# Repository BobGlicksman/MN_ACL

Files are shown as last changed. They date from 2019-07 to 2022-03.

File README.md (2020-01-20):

# MN_ACL
## RFID based access control and monitoring system for Maker Nexus.
This repository contains hardware, software and test information 
related to the development of an access control system for
Maker Nexus.

Each member is issued an RFID card that has been prepared to identify the member
and to ensure that cards can be revoked and/or replaced.  Membership information relevant
to card issuance and to member check-in and permission to access certain equipment
is supplied via real-time
query of the Maker Nexus CRM system which uses EZ Facility.  The code to access EZ Facility
via their REST API has been broken out into separate functions so that it can be replaced
by any suitable database.  Administrative utilities are also provided to facilitate recycling
membership RFID cards and identifying the owner of misplaced RFID cards.

A "Facility Database", separate from EZ Facility, is included in this project.  EZ Facility is the
authoritative source for all membership status, payment and training information needed for access
control decisions.  The Facility Database provides membership access records for both a real-time 
status display and for off-line reporting on facility and equipment utilization.

This project uses a Particle Argon; however, a Xenon should also work in a Particle Mesh configuration.  
The access control system is based upon Mifare Classic 1K RFID cards that are written to/read from
using a PN532-based MFC/RFID breakout board.  The Adafruit PN532 library is used to supply
the underlying communication support between the Particle device and the RFID card. Mifare Classic 1K 
cards have been chosen because they are inexpensive and widely available on the Internet.
These cards are older technology and not very secure.  However, we have deemed them to be secure 
enough for this application.  One sector of the card is chosen for this application and the sector encryption
keys and block access control bits are changed to make the card data secure from casual inspection and
from cloning.  The
remaining sectors of the card can be used for other applications, e.g. vending machine credits or special room
access.

A detailed technical overview of this project is provided in Documents/RFID_ACS_Overview_Document.pdf.  
We strongly encourage you to read through his document before deciding how this project might be
applied to your unique access control and monitoring situation.

## Files and Folders:
#### README.md:  
This document.
#### Repository_Overview.pdf:  
An overview of the structure and contents of this repository.
#### Terms_Of_Use_License_and_Disclaimer.pdf:  
You MUST READ this document and AGREE TO 
its terms and conditions before you are authorized to use the material in this repository. This
project is released under and open source, non-commercial license.
### Documents (folder):
Project documentation, including the RFID_ACS_Overview_Document and build, install and
usage documents.
### Hardware (folder): 
Design information (CAD files) and documentation for all of the hardware used
in this project, including electronic design, printed circuit board design, and
mechanical/packaging design and build information.
### Software (folder):
Design information, documentation, source and executable code for all of the software
in this project, including Particle (Argon) software, webhooks, PHP files, database
schema and stored procedures, Android app source and executable files, and web/html
files.
### Test and Development (folder):
Legacy test code and test results for integrating RFID cards and EZ Facility API calls with 
Particle devices.  The information in this folder is not necessary to build or install
this project.  However, it may be useful for developing extent ions to the RFID and/or EZ Facility
capabilities of this project.

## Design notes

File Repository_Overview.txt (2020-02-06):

Repository Overview

In this repo you will find all the software, hardware design files, and documentation to allow you to bring up and use your own RFID badge system. 

You will find the following folders:

1. Hardware: Contains the files for
1.1 creating the printed circuit board
1.2 CAD files for laser cutting the enclosure,
1.3 parts list

2. Software: Contains software for:
2.1 The Arduino C code to compile and download to the Particle.io Argon processor.
2.2 The Particle.io webhooks that allow the Argon to interact with internet based resources.
2.3 The MySQL database code and PHP web site that interface it to the internet.
2.4 The two Android administrator applications, written in the MIT App Inventor 2 environment.

3. Documents: A robust set of documentation for both assembly and operation of the RFID system.

4. Test And Development: Several programs that can be used to experiment with parts of the overall system. In particular, there are several programs we used to exercise the PN532 RFID system and software to help us understand how it works. We include them in case they are useful to you.

We hope this project is useful to you. We do not, of course, offer support in any way. However, drop us an email if you have questions and we might be able to advise you.
Bob Glicksman, Jim Schrempp, Mike Calyer

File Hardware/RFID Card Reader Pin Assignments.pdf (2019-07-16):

# RFID Card Reader Photon/Argon/Xenon Pin Assignments

Bob Glicksman; 7/15/19

## LCD Wiring:

LCD | | Particle
VSS | -- | GND
VDD | -- | +3.3 volts
V0 | -- | 10K ohm pot wiper
RS | -- | A0
RW | -- | GND
E | -- | A1
D0 | -- | N/C
D1 | -- | N/C
D2 | -- | N/C
D3 | -- | N/C
D4 | -- | A2
D5 | -- | A3
D6 | -- | D5
D7 | -- | D6
A | -- | +3.3 volts
K | -- | GND

## PN532 Breakout Board Wiring:

Breakout | | Particle
5V | -- | VIN (Photon); VUSB (3rd Gen)

GND | -- | GND
3.3V | -- | N/C
SDA/TXD | -- | D0 (5.6K pullup to 3.3V)
SCL/RXD | -- | D1 (5.6K pullup to 3.3V)
IRQ | -- | D3

DIP Switches: SEL1 = OFF (L); SEL0 = ON (H)

LED and Buzzer Wiring.

Buzzer | -- | Photon D2
Ready LED | -- | Photon D4
Admit LED | -- | Photon A4
Reject LED | -- | Photon A5

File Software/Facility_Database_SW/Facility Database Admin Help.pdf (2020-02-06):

# Facility Database Admin Help

The Facility Database holds the event logs from each of the RFID stations. It also holds the configuration information for the stations. And, it is the data source for the reporting web site.

In this document we assume you are familiar with PHP, MySQL, phpMyAdmin (or similar tool), and curl.

# Database Setup

## Create the database

Using your ISP admin console, or similar, create a database called rfidlogs (or your own name). You do not need to make the database available for remote access.

## Create users

Create two users:

- rfidreader (Execute SP, Select)
- rfidlogger (Insert, Select)

## Database structure

Use the file rfidlogs_schema.sql to create the tables and stored procedures.

# Website Setup

## Deploy

Copy all the files in datalogging to the root of your website.

## Modify the rfidconfig.ini file

- Add the two database uses in the appropriate keys, and their passwords.
- Change the photoDisplay key to have the URL prefix of the server hosting your member's photos.
- Change the file permission to 660

## Test

Bring up the web page rfidhome.html

# The Database

The rfidlogs database has two tables: rawdata and stationConfig.

## rawdata

This table holds the data for every log event that is recorded. These are typically made by an rfid Station, but could be made by any process that calls the correct URL.

rawdata is written to by rfidcheckin.php and rfidlog.php. These pages accept the POST of a JSON package. Each file has a description of the JSON it expects in the header of the file.

### rfidcheckin.php

is used to toggle the state of a clientID in the database. Each day, the first time rfidcheckin is called for a particular clientID, a record is entered for Checked In.

The next time that clientID is used a Checked Out record is entered.

### rfidlog.php

is a more generic log function. The parameters passed to it are added to the rawdata table. This is useful for logging errors, warnings, restart events, etc.

## stationConfig

This table contains configuration information for the different stations you have. In a nutshell, each station has a deviceType. When the station boots it calls fdbGetStationConfig.php passing in its deviceType. The URL returns a JSON package telling the Station what name to use, what eventName to use when logging, the strings it should look for to validate a client for machine use, etc. The fields are each documented in the comments section of the database.

Use phpMyAdmin to insert records to this table to establish your configuration.

Note: We have included sample data in stationConfig_sampledata.sql. You can insert this data into your database if you want to see what our config looks like.

# Tests

Note: To facilitate testing we supply two files of sample data: rawdata_sampledata.sql and stationConfig_sampledata.sql. You can load these two sample sets to see what the website reports look like if you are unable to get your own POSTs to work for some reason.

1. Test Logging:
a. In the header of file rfidlog.php is a sample JSON. Use that JSON to construct several test packages.
b. Post each to rfidlog.php. Look in the rawlog table to see your data.
c. Use rfidclientactivity.php to see that the data is presented on the page.
2. Test Check in/out
a. In the header of file rfidcheckin.php is a sample JSON. Use that JSON to construct several test packages. Use the same clientID in a few of the packages.
b. Post each to rfidcheckin.php.
c. Use rfidclientactivity.php to see that the data is presented on the page.
d. Use checkinreport.php to see that your clientID has been checked in and then post again to see that has been checked out.
3. Other Reports
a. From the rfidhome.html page, click on each link and see that the report shows the activity you have just performed.
4. Manual Checkout
a. With at least one client Checked In, bring up checkinreport.php.
b. Click on one of the names and see that the client is checked out.
5. Station Configuration
a. Call the URL fdbGetStationConfig.php?cmd=-1
b. See that the JSON returned has a list of stations and their device types. This is used by the admin configuration app.
c. Call the URL fdbGetStationConfig.php?cmd=<<any valid device type>>
d. See that the JSON returned is a set of configuration parameters for the Station.

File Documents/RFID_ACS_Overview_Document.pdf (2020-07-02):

# RFID Access Control System System Overview Document

By: Jim Schrempp, Bob Glicksman and Mike Calyer; v5, 6/30/2020

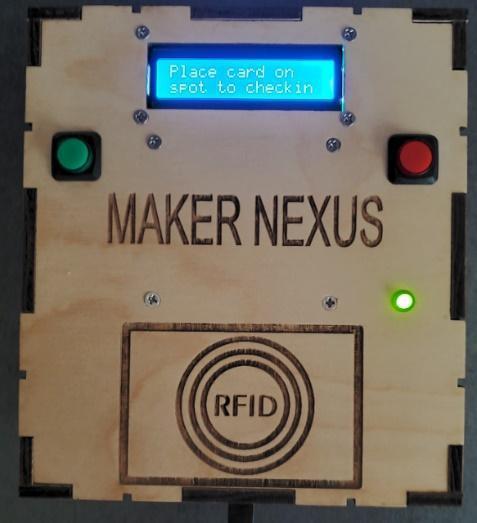
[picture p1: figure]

© 2019/2020 Team Practical Projects, Maker Nexus, Bob Glicksman, Jim Schrempp and Mike Calyer. All rights reserved.

NOTICE: Use of this document is subject to the terms of use described in the document “Terms_of_Use_License_and_Disclaimer” that is included in this release package. This document can be found at:

https://github.com/TeamPracticalProjects/MN_ACL/blob/master/Terms_of_Use_License_and_Disclaimer.pdf

© 2019/2020, Team Practical Projects, Maker Nexus, Jim Schrempp, Bob Glicksman and Mike Calyer; all rights reserved. Subject to “Terms of Use, License and Disclosure”

TABLE OF CONTENTS.

TABLE OF CONTENTS. | 1
FORWARD. | 2
GLOSSARY AND KEY CONCEPTS. | 2
PROJECT REQUIREMENTS. | 5
Background. | 5
Top Level Requirements. | 7
Control vs Cost and Accessibility Requirements. | 8
Facility Access Control Detailed Requirements. | 8
Location/Equipment Access Control Detailed Requirements. | 9
Administrative Requirements. | 9
Facility Monitoring Detailed Requirements. | 10
Technical Failure Backup Requirements. | 10
DESIGN OVERVIEW. | 10
Top Level Design. | 11
RFID Lock Design. | 13
RFID Station Design. | 15
Administrative Station Design. | 17
RFID Station Type Selection. | 17
Design for EZ Facility Access. | 18
Design For Facility Database. | 19
Security Design and Secret Information. | 21
RFID Card Security. | 21
Station Security. | 24
Cloud Security. | 25
Administrative Security. | 25
Cost Effective Design. | 26
CONCEPTS FOR PROJECT USE BY OTHER THAN MAKER NEXUS. | 26
Implement this project in a non-Maker Nexus Facility that uses EZ Facility. | 26

Implement this project in a non-Maker Nexus Facility that uses a different CRM system than
EZ Facility. | 27

Implement this project in a non-Maker Nexus Facility that does not have an electronic CRM
system. | 27

FORWARD.

The RFID Access Control System is a very complex project. The project was driven by the need for such a system at Maker Nexus, a 501(c)3 non-profit makerspace located in Sunnyvale California. This document is intended to provide the reader with an overview of the requirements and design of the project. Complete details of the project are posted in this repository and are offered to the general public under a Creative Commons open source, non-commercial license.

Interested parties may wish to implement variants of this project that meet the unique needs of their establishment or organization. We feel that it is very important for anyone who wishes to do so to read through this overview document and become familiar with the requirements and architecture of the project. It is only through a complete understanding of the project architecture that interested parties can successfully modify this project to meet their own, specific requirements and needs.

GLOSSARY AND KEY CONCEPTS.

The following terms are used throughout this document and are defined herein.

Maker Nexus. Maker Nexus is a 501(c)3 non-profit makerspace located in Sunnyvale California. https://www.makernexus.com/

EZ Facility. EZ Facility is an on-line scheduling, management and membership system. Maker Nexus has chosen EZ Facility to fulfill its customer relationship management (CRM) needs. As such, EZ Facility is the authoritative source for all Maker Nexus member information, including current membership status, current member payment status, and member “packages”. Maker Nexus uses EZ Facility “packages” to record all member training, including basic operating and safety training that is required before a member can access certain locations within Maker Nexus or use certain pieces of equipment. https://www.ezfacility.com/ If you use some system other than EZFacility, then when you see this term think: “Membership Management System”.

RFID. “Radio Frequency Identification”. In this context, “RFID” refers to a system that uses Mifare Classic 1K NFC cards operating at 13.56 MHz. Maker Nexus members are each issued a personalized “RFID” card that contains encrypted information that identifies the card holder in EZ Facility and contains a provision for card revocation. Classic 1K cards provide a reasonable level of security to prevent card cloning or tampering at a low per-card cost from a wide variety of sources. This project utilizes NFC technology based upon the NXP PN532 chip. This chip supports a wide variety of RFID cards, including the latest technology Mifare Desfire EV1/EV2 cards. This approach offers a pathway to upgrade the system to a higher level of security, albeit at a significantly higher price per card.

Encryption Keys. Mifare Classic 1K cards allow two encryption keys per sector, where a “sector” is a group of 4 user-read/write 16-byte data blocks. This project uses one sector of a Classic 1K card and two secret encryption keys. “Key A” is a secret key that is required to authenticate with a Maker Nexus RFID card for reading (only) of two items of data: the member’s EZ Facility unique “clientID” and a randomly assigned “MN card UID”, retained in the CRM system, that is used for card revocation purposes. These items of information can only be read from an RFID card by a device that knows this secret key. The second secret key, “Key B”, is required to write data to the Maker Nexus sector on the RFID card and is also required to change keys on the card and to reformat a card back to its “factory fresh” condition. Key B is only used for administrative purposes – to create new cards, update/revoke cards, and to restore a card to “factory fresh” condition.

Particle. Particle is a company that provides a complete “Internet of Things” (IoT) platform, including Arduino-like hardware, development software, and connectivity. This project uses Particle’s “3rd generation” mesh devices; specifically, the Particle Argon. The Argon is an inexpensive yet powerful microcontroller module with built-in WiFi capability. The Argon can also act as a mesh network gateway; specifically, with the lower cost Particle Xenon modules. As of this writing, we have tested use of a Xenon/Argon mesh/WiFi configuration for our stations and they appear to work. However, our initial deployment is limited to Argon devices because Particle does not yet support redundant mesh gateways with automatic failover. Therefore, each of our Particle based stations has direct WiFi connectivity via its Argon module. https://www.particle.io/

Particle Cloud. “Particle Cloud” refers to Particle’s cloud platform that provides Internet device management and integration between Particle hardware modules and the Internet connected world. This project uses basic Particle cloud connectivity to communicate with Argon-based RFID stations.

Webhook. A webhook is a real time service provided by the Particle Cloud for connecting Particle processors to the larger internet. A webhook is invoked when a Particle processor publishes a specific event via Particle.publish(), passing any parameters in a JSON package. The webhook calls out to a specified URL and interprets the JSON for any parameters to use. When a response is returned from the URL, the Particle Cloud webhook returns the data to the Particle processor, optionally formatting the response. Our system uses Particle’s cloud webhook capability to communicate with EZ Facility’s cloud API and with a cloud-based SQL database for real-time recording of member activities within Maker Nexus.

RFID Station. Various “stations” are located within the Maker Nexus facility where members are required to “tap in” with their RFID membership card. Each station uses the Secret Key A to read information from the Maker Nexus “sector” in the RFID card that is presented. The station then communicates with EZ Facility in order to obtain membership information that is necessary to determine if the member has access to the location/equipment under that station’s purview. RFID stations are configured (by an administrator) to provide specific types of access control services. There are three general types of RFID stations in this project:

Administration Station: There is generally only one administration station provided within Maker Nexus. This station is subject to added physical security and is the only station type that can create new RFID cards, revoke old RFID cards, reset RFID cards, and update/change Maker Nexus secret encryption keys used on a card.

Check-in/out station: There are one or more of these stations at each entrance/exit to Maker Nexus. Members must tap their badge at one of these stations when they enter and leave the Maker Nexus facility. Check-in/out stations use data from EZ Facility to ensure that memberships and dues are current before a member is admitted to the facility. This station also logs check-in/out events to both EZ Facility and the Facility Database.

Location/equipment station: Various subtypes of these stations are placed within Maker Nexus to check status and log member use of locations/equipment within the Maker Nexus facility. Location/equipment stations use data from EZ facility to ensure that members have the necessary safety training “packages” for that location/equipment before the member can access the associated machine or location within Maker Nexus.

RFID Lock. An “RFID lock” is a separate electronic circuit board that controls an electromechanical locking device. RFID Stations “publish” successful “tap-in events” to the Particle cloud. RFID Lock devices “subscribe” to these events and can use such events to unlock a cabinet or drawer. Such a cabinet or drawer might contain a physical access key for some piece of equipment (e.g. a laser cutter), essential tooling to use some piece of equipment (e.g. bits and a locking key for a drill press), or anything else that should only be accessible to people who are authorized to use some item of equipment. Multiple RFID Locks may be associated with a specific type of RFID Station (e.g. “Laser Cutter” location/equipment station type). Multiple RFID Stations may be of the same type (e.g. multiple facility check-in stations). Station type codes and the codes for RFID Locks to “listen for” are completely facility dependent and are defined in a table within the Facility Database (see below). Particle publish/subscribe capabilities utilize the particle Cloud and are highly secure. The RFID Lock project is an add-on to this project and details are contained in its own GitHub repository; see:

https://GitHub.com/TeamPracticalProjects/RFID_Lock

Facility Database. The “facility database” is a cloud-based SQL database (with associated php software) that keeps track (in real time) of member activity within Maker Nexus. This database keeps track of members who are inside the facility and of location/equipment for each member as they tap into areas within Maker Nexus. The facility database provides administrators and emergency response personnel with immediate and current information about member location in the event of an emergency. This database can also be used to monitor access control compliance and to produce analytical reports about equipment and location utilization. RFID stations communicate with the Facility Database through a Particle cloud webhook.

Checkin Display. A web page available within the Maker Nexus facility that shows members who are currently in the facility using data from the Facility Database. It also shows an indication of which stations each member has activated while in the facility. The Checkin Display is presented on at least one monitor located at a prominent spot within the facility.

PROJECT REQUIREMENTS.

Background.

Maker Nexus is a 501(c)3 non-profit makerspace located in Sunnyvale, California. The Maker Nexus mission statement is as follows:

“Our mission is to increase the capacity of individuals in our community to make things. We believe that unleashing the innate innovation in people can make their lives better, can improve our community, and can even change the world.”

Safety, security, and financial viability are key concerns of Maker Nexus. Maker Nexus has a substantial amount of industrial grade equipment, including (but not limited to):
- 3D printers
- Electronics bench (including soldering equipment, test equipment and hand tools)
- Laser cutters/engravers
- Vacuum formers
- CNC embroidery machines
- Woodshop, complete with planers, joiners, table, miter and band saws, drill press, lathes, CNC router, workbenches, and hand tools
- Metal shop (in development, as of this writing)
- Classrooms, including computers
- High speed WiFi

Safety is a primary concern. Each member must pass a class (or take an alternative operation and safety test) before they are permitted to use specific items of industrial equipment. The classes emphasize safety and the proper operation and handling of each item of equipment. The scope of safety also includes staff training, procedures, and information needed for emergency first responders.

Security is a related concern. It is important to monitor who is in the facility and who is using each equipment item at all times.

Financial viability is the remaining main concern of Maker Nexus. Several previous maker spaces have gone bankrupt due to a lack of financial scrutiny and control. Financial viability includes safety, as proper safety procedures and enforcement help to reduce insurance and liability costs. Financial viability includes security because good security procedures and enforcement mechanisms reduce financial losses due to abuse, neglect, and theft. Finally, financial viability necessitates tight financial controls, including billing and tracking of memberships, dues payment, and expenditures.

Maker Nexus, like virtually all non-profits, must maintain a tight budget that limits the number of paid staff personnel needed to operate the facility. Automation is viewed as a key element in reducing staffing requirements. Maker Nexus has selected EZ Facility as its CRM system. EZ Facility is the authoritative source for all Maker Nexus membership, membership status, billing, payment tracking, and class/test completion information.

Maker Nexus has also determined that automation can assist a limited and busy paid staff via an RFID card-based access control system. This system is what this project is about. Each member is issued an RFID card. The RFID card is required to check in and out of the facility and to gain access to locations/equipment within Maker Nexus. Since EZ Facility is the singular, authoritative source for all the information needed for access control purposes, the RFID card system must query EZ Facility directly, and in real-time, for information needed to make proper access control decisions. EZ Facility has a cloud API that is suitable for this purpose. However, EZ Facility does not have an RFID card system that suits this purpose. This project provides for this latter need.

The idea behind this project is that various RFID card reader stations are placed within the Maker Nexus facility. Stations are placed at the main entrance reception desk so that members can check in and check out of the facility by tapping their membership RFID card at the station. Check in/out stations are also located at secondary entrances and exits to the facility. Check -in/out stations obviate the need to staff a reception desk and to directly monitor secondary entrances/exits. Members are only permitted into Maker Nexus if they are paid up members in good standing. Otherwise, members must contact a facility manager to resolve their membership-related issue(s).

Additional RFID card stations are located inside the facility, near specific locations (e.g. textile area) or specific pieces of industrial equipment (e.g. laser cutter) that require members to pass safety and operation classes/tests before they are permitted to use the equipment. Members gain access to locations/equipment by tapping their RFID card at the location/equipment station.

Members must have the proper “package(s)” within EZ Facility in order to gain access to the associated locations/equipment. An EZ Facility “package” represents completion/passing of the relevant class(es). A member who does not have the proper package(s) in EZ Facility needed to gain access to an item of equipment or a location is rejected by the RFID card system and must contact a facility manager to resolve their credentialing issue(s).

Maker Nexus staff needs to monitor the RFID card system admit/reject decisions. Two means are provided to accomplish this end. First, each RFID card station is equipped with highly visible red and green lights that clearly indicate the station’s accept/reject decision for each card tapped. Each station also has a buzzer that provides an audible indication of accept or reject. Second, a summary status display is provided on monitors located at the entrance and at other locations within the facility. This display provides a quick overview of who has been admitted into Maker Nexus and what location/equipment each admitted member has been accepted. Staff members can use this display to quickly determine who is in the facility, where in the facility they may be, and (by omission) whether someone is in the facility or using equipment for which they do not have permission. The Facility Database drives this display and the same database may be used to generate various administrative reports, such as facility and machine utilization statistics.

RFID Locks optionally provide additional access control by keeping equipment enable keys and critical tooling locked up and inaccessible to anyone who does not successfully tap in to an RFID Station that is associated with some specific location or item of equipment. RFID Locks are supported by this project but the details are contained in their own repository; see:

https://GitHub.com/TeamPracticalProjects/RFID_Lock

Top Level Requirements.

Each member of Maker Nexus shall be issued an RFID card. The member must use their RFID card to gain access to the Maker Nexus facility and to gain access to specific items or equipment or specific locations (e.g. textile area) within the facility.

The RFID card system shall query EZ facility directly, and in real-time, in order to determine whether the cardholder is permitted into the facility and/or permitted to use specific items of equipment, depending upon the RFID card station’s location and function.

Each RFID station shall light a green “admit” light and beep an “admission” sound after a card is tapped and the proper credentials for that station location are obtained (for the card holder) from EZ Facility. Each RFID Station shall publish a successful tap-in event to the Particle cloud containing the station’s type (“woodshop”, “laser cutter”, “check-in”, etc.).

Each RFID station shall light a red “reject” light and beep a “rejection” sound after a card is tapped and the proper credentials for that station location are not found (for the card holder) in EZ Facility, or if some error occurs.

The RFID card system shall log all card taps and access control decisions to a cloud-based Facility Database. The Facility Database shall utilize this information to maintain a real-time display of members admitted to and present within Maker Nexus and of locations/equipment that each member has been admitted to.

Members shall be encouraged to “tap out” when leaving Maker Nexus. These taps shall be used to update the Facility Database and the associated summary status display. It is not required that members “tap out” on individual location/equipment stations.

The summary status display shall automatically be cleared each day after the facility has closed. This will compensate for any failures to tap out from the facility.

There shall be a manual process available to Maker Nexus staff members that allows them to “tap out” any member.

Control vs Cost and Accessibility Requirements.

The RFID card access control system shall provide a “moderate” level of security and control. The term “moderate” herein is used to indicate a need for balance between the project goals and objectives on one hand, and the cost and member usability on the other hand. Specific requirements related to “moderate” security and access control are as follows:

- Access control shall be via RFID cards that are reasonably difficult to clone. The use of bar codes or unencrypted RFID tags are not acceptable. On the other hand, RFID cards/technology must be easily available at low cost.
- Physical barriers for access control are not required and are currently deemed to be an unacceptable intrusion on member satisfaction and on safety. Powering off equipment to prevent member access after RFID system rejection is not required and is currently deemed to be undesirable from an equipment longevity perspective. However, the desirability of powering off specific items of equipment is presently under review and this limitation may be removed for certain items of equipment at some later time.

Facility Access Control Detailed Requirements.

The RFID card access control system shall query EZ Facility, in real-time, when a member taps in at a facility entrance station. The member shall be identified to EZ Facility by the EZ Facility “clientID”, which is a unique identifier for each membership record within EZ Facility.

A member shall only be admitted to Maker Nexus if (a) their membership status is “current”, and
(b) they do not owe money for dues or for other purchases, and (c) their RFID card has not been revoked. If a member is rejected for any of these reasons, admission to Maker Nexus shall be rejected and the cardholder shall be directed to see a facility administrator to clear up their account.

Each time that an RFID card is tapped at a facility entrance station, the station shall query EZ Facility for admission information as required above. The station shall also check the current check-in status with the Facility Database to see if the card holder is already checked into Maker Nexus. If not, the station shall consider the tap to be a check-in. If the card holder is already checked into Maker Nexus, the tap shall be considered a check out and the Facility Database shall be updated accordingly.

Location/Equipment Access Control Detailed Requirements.

The RFID card access control system shall query EZ Facility, in real-time, when a member taps in at a location/equipment station. The member shall be identified to EZ Facility by the EZ Facility “clientID”, which is a unique identifier for each membership record within EZ Facility.

A member shall only be admitted to the location/equipment of the station if they have the required “package(s)” for that equipment/location. If a member is rejected on this basis, use of the associated location/equipment shall be rejected and the cardholder shall be directed to see a facility administrator to clear up their records.

If the member is admitted by the station, an indication shall appear with their information on the summary status display.

Access control activity - positive and negative - shall be logged to the Facility Database.

Administrative Requirements.

Maker Nexus administrative personnel shall be provided with the following capabilities:
- The capability to create and issue a valid Maker Nexus RFID card to a member.
- The capability to revoke all previous cards issued to a member whenever a new card is issued.
- The capability to reset any Maker Nexus formatted cards to a “factory fresh” condition.
- The capability to determine the owner and status of an unknown RFID card.

All information needed to produce/manipulate Maker Nexus RFID cards and EZ Facility record information shall be kept secret and shall be known only to selected Maker Nexus administrative personnel.

RFID card check in/out stations and location/equipment stations shall not have the capability to write or to alter information stored on the RFID cards; only to read information from the cards securely. Only specifically designated administration stations shall have the capability to create or modify Maker Nexus formatted RFID cards.

Only duly designated Maker Nexus administrative personnel shall be able to configure or reconfigure RFID card stations to be check in/out stations, location/equipment stations for specific location/equipment, configure RFID Lock types and listen codes, or to perform administrative functions.

Facility Monitoring Detailed Requirements.

A Facility Database shall be provided to record successful and unsuccessful taps at all check-in and location/equipment stations. Information recorded in the facility database shall be used to determine if a tap at a facility check-in station represents a check-in or check-out; i.e. toggling this status.

The Facility Database shall drive a summary status display (e.g. web page) that depicts all members who are currently checked-in to Maker Nexus. This display shall be updated in near real-time as check-ins and check-outs take place. This display shall also show current member check-in status for each location/equipment item within Maker Nexus. Reports of check ins shall only report members who have checked in that day. Members who fail to check out the previous day shall not be reported as checked in.

Displays that are driven from the Facility Database shall be placed near the front desk and at other locations within Maker Nexus that are visible to staff members throughout the facility.

Note: the Facility Database does not supply data used to admit or deny a member access to the facility or equipment. The data for these decisions shall be provided by EZ Facility exclusively.

Technical Failure Backup Requirements.

Procedures for facility check-in and location/machine access control shall be created that operate in the event of failure of any part of the RFID card access control system. The same procedures shall be used if a member does not have their RFID card with them and for guests who are not current members of Maker Nexus. Manual sign-in sheets are an acceptable solution.

DESIGN OVERVIEW.

The section presents an overview of the RFID access control system project design. The overview introduces the major components of the system and the data flows between them. This overview also highlights how the system design achieves the project requirements.

Top Level Design.

The overall architecture for the system is depicted in figure 1:

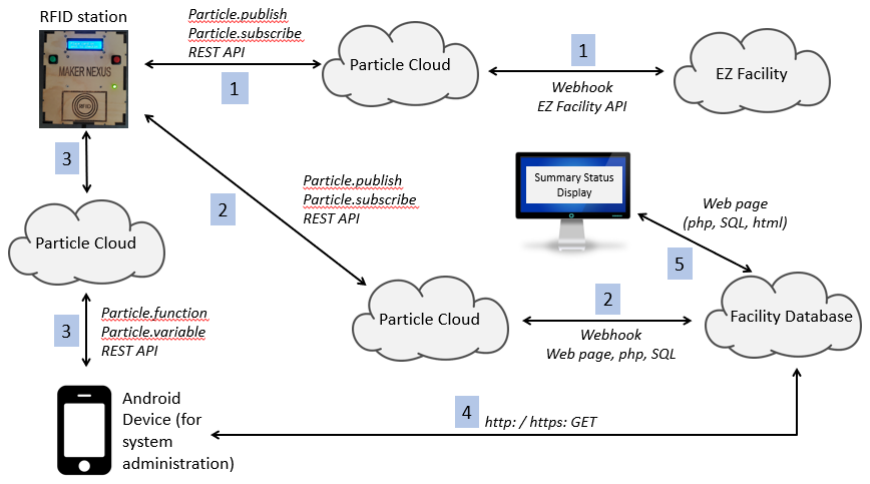
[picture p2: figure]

Figure 1. System Architecture.

The major components of the system are as follows:

- RFID station: There are multiple RFID stations that are part of this project. The stations are used for facility check-in, location and equipment access control, and system administration. Each station contains a Particle¹ Argon²
; a high-end microcontroller with WiFi – Internet access.
- Particle cloud: The Particle devices in the RFID stations communicate securely with the Particle cloud. The Particle cloud allows Particle devices to securely communicate with Internet based services via a REST interface, and also via webhooks. Both the REST interfaces and webhooks are used in this project.

1 www.particle.io

2 Any 3rd Generation Particle device may be used in RFID stations. The Argon provides WiFi access to the Internet directly. Xenons can be used to provide Internet access indirectly, via the Particle mesh network capability, using an Argon or Boron as the Internet gateway. We have tested a Xenon working through an Argon as the gateway but have not currently deployed any Particle devices other than Argons. As a result, each RFID station communicates directly with the Particle cloud over the Maker Nexus WiFi.

- EZ Facility: EZ Facility is a cloud-based CRM system. EZ Facility offers a REST API that allows Internet connected devices to query and modify information in the EZ Facility Maker Nexus account.
- Facility Database: This is a mySQL database, with associated web pages and PHP code that is hosted in the Maker Nexus web hosting cloud account. At the moment, the database logs all transactions sent there by the RFID stations³
in a single table.
- Summary Status Display: This is a computer monitor that displays a web page(s) produced by querying the Facility Database using php scripts and javascript. The web page shows all members who are currently checked in to Maker Nexus and all locations/equipment that each member checked into using their RFID card.
- Android Device: This is any WiFi-connected android smartphone or tablet. As of this writing, an inexpensive 7” Kindle Fire tablet is used, but most any Android device will do. This device hosts apps that Maker Nexus administrators can use to configure other stations, to manage RFID cards, and other related administrative functions.

The various flows of data within the system are depicted by numbers above the arrows in figure 1.

(1) Several webhooks have been created to communicate with EZ facility using the EZ Facility API. These webhooks are stored in the Maker Nexus RFID Admin account on the Particle cloud. Each webhook is triggered by a Particle.publish() statement in the Argon’s firmware. Each Argon receives webhook responses via Particle.subscribe() statements. Webhooks are provided to: (a) Obtain a temporary access token (OAuth) to the Maker Nexus EZ Facility account, (b) Obtain member information from EZ Facility based upon the membership number, (c) Obtain member information from EZ Facility based upon the EZ Facility ClientID field, (d) Obtain package information for a member from EZ Facility, and (e) check a member in to EZ Facility (check-in to Maker Nexus). (Note, this EZ Facility check in is made to enable EZ Facility reports. It is separate and distinct from the Facility Database check in logging and reporting.)
(2) Three webhooks have been created to communicate with the Facility Database via the webserver and php. The first webhook logs events from an RFID station to the Facility Database. The second webhook logs checkin/out taps and retrieves information from the Facility Database back to the RFID Station to determine if a member is checking in or out. The third webhook returns admission criteria and station codes for each type of RFID station defined for the facility.

3 Another table is used to store information about RFID station types, the codes associated with each station type, and the credentials (packages) needed for member access to locations/equipment. This table provides centralized definition and control of station types and access requirements.

(3) Apps on the Android device communicate with RFID stations to assist Maker Nexus administrators with managing the various RFID station types and with making, revoking, and verifying Maker Nexus RFID cards. Each app communicates with the Administration RFID station via WiFi-Internet to the Particle cloud. Functions on the RFID station are exposed to the Particle cloud via Particle.function() declarations within the firmware. Likewise, data items within the RFID Station firmware are exposed to the Particle cloud via Particle.variable() declarations within the firmware. Apps on the Android device call such functions and read such variables via Particle’s REST interface to the Particle cloud.
(4) A REST interface (http: or https: GET) calls a php script that returns a JSON formatted list of station types and station type codes from the Facility Database. A table in the Facility Database defines all station types, their type codes, and the criteria for admitting a member to the location corresponding to each station type.
(5) A computer obtains a summary status web page from the Facility Database once every few seconds and displays the summary status on the Summary Status Display monitor. At Maker Nexus, the summary status page shows each currently checked in member’s photo and first name and well as the locations/equipment that the member has checked into using their RFID card. In addition, this display shows other web pages in a timed sequence, such as the calendar of events for the current month.

RFID Lock Design.

RFID Locks are optional add-on to the Maker Nexus Access Control system. RFID Locks are particle Photon based circuit boards with hardware to control various types of electromechanical locks. The architecture for incorporating RFID Locks into the system is shown in figure 2, below:

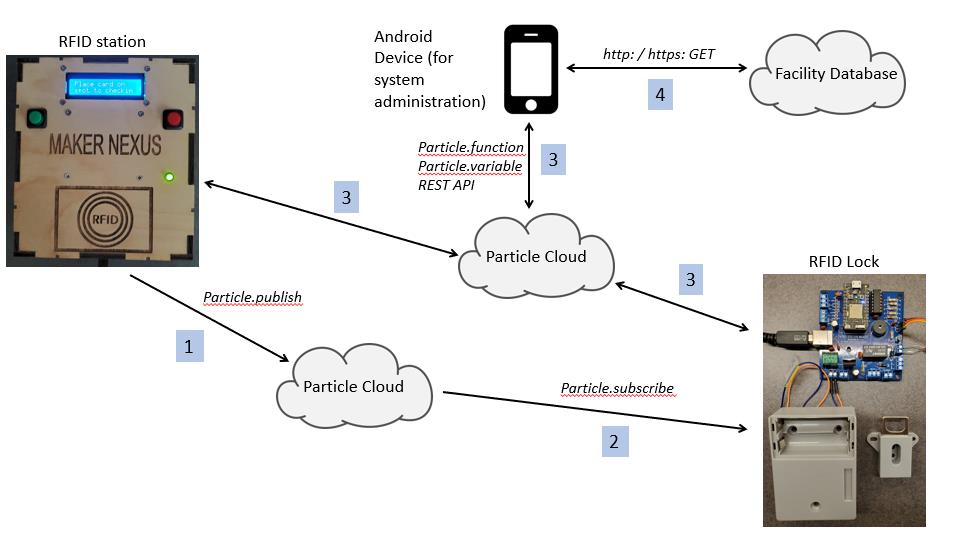
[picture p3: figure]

Figure 2. RFID Lock Architecture.

The components shown in figure 2 are the same as described for figure 1, above, with the addition of an RFID Lock board and associated electromagnetic locking device. The RFID Lock board is based on the Particle Photon and is fully described in its own repository; see:

https://GitHub.com/TeamPracticalProjects/RFID_Lock

The various flows of data supporting the optional RFID Lock capability are depicted by numbers above the arrows in figure 2.

(1) RFID Stations publish an “event” to the Particle cloud whenever a user successfully taps-in to the station. The event data contains the station’s type (“check-in”, “laser cutter”, “woodshop”, etc.). The station type is a code that is defined in a table in the Facility Database.
(2) RFID Locks subscribe to these “events”. Each RFID Lock matches the event data to a “Lock Listen code” that is configured for that specific lock device. If the codes match, the RFID Lock unlocks its electromechanical device.
(3) An App on the Android device communicates with RFID Stations and RFID Locks to set a “station type” into each device. Station types are facility-defined codes that designate the type of the Station or Lock. Codes for RFID Stations are assigned within the range of 0 – 999, while type codes for RFID Locks are assigned values of 1000 and above. Functions on the RFID Station/Lock are exposed to the Particle cloud via Particle.function() declarations within the firmware. Likewise, data items within the RFID

Station/Lock firmware are exposed to the Particle cloud via Particle.variable() declarations within the firmware. The App on the Android device calls such functions and reads such variables via Particle’s REST interface to the Particle cloud.

(4) A REST interface (http: or https: GET) calls a php script that returns a JSON formatted list of station/lock types and station/lock type codes from the Facility Database. A table in the Facility Database defines all station/lock types, their type codes, and the criteria for admitting a member to the location corresponding to each station type.

Hardware and software details pertaining to RFID Locks are contained in the repository:

https://GitHub.com/TeamPracticalProjects/RFID_Lock

RFID Station Design.

Figure 3 depicts the internals of an RFID station. All RFID stations contain identical hardware and firmware. The station’s function is set by calling a cloud function on that station with an argument that designates the type and function of that station. Once set, the station type is stored in non-volatile memory in the Argon. The cloud function can be called from an android app or via the Particle Console.

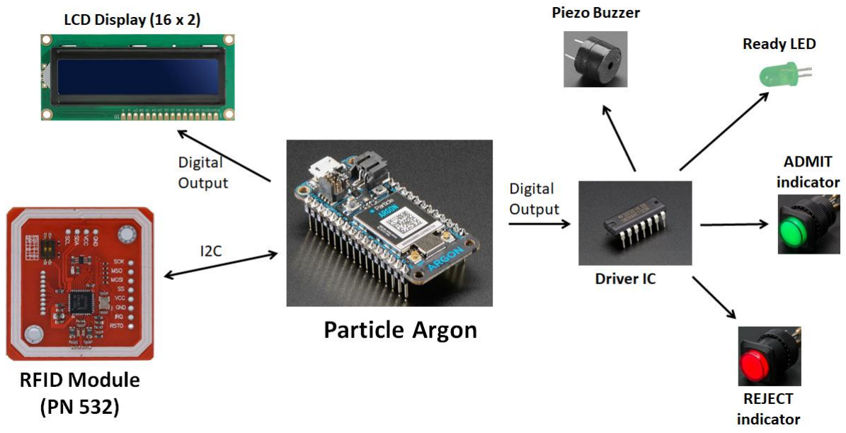
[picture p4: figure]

Figure 3. RFID Station Hardware.

Each RFID station contains the following major components:

- Particle Argon. The Particle Argon is the central “brain” of an RFID station. The Argon contains an advanced microcontroller and internal WiFi capability. The Argon uses WiFi to communicate with the Particle cloud. This communication allows the Argon to be re-programmed “over the air” with new firmware. It also provides for “cloud communication” between the Argon and the other components of the system. As a microcontroller, the Argon communicates with the other hardware components of the station via it’s I/O ports.
- RFID module. The RFID module provides near field power and communication with RFID cards that come it close proximity to it. The module used in the RFID station uses a PN532 chip from NXP. The PN532 can communicate with a wide variety of RFID/NFC cards, including the Mifare Classic 1K cards used in this project. The RFID module offers several means of communication with a host processor. I2C communication is used in the RFID station because it is reliable, is supported by the Argon, and uses only 3 I/O pins (including an “interrupt” signal to the microcontroller).
- LCD display. A two-line, sixteen character per line LCD display is used to provide prompts and feedback between the Station and an RFID card holder. A 3.3 volt LCD module is required to interface with the Argon without additional level shifting circuitry.
- Driver IC. A 74AHCT125 driver is used to integrate LEDs and a buzzer with the Argon microcontroller. This IC allows these external devices to be powered from the Station’s 5 volt power supply, thereby limiting drain on the Argon’s 3.3 volt regulator. The driver IC converts 3.3 volt outputs from the Argon to 5 volts that power these external devices.
- Piezo Buzzer. A piezo buzzer is used to provide audible feedback to users and other people in the vicinity of a Station. User interactions with a Station will normally resolve into either acceptance of their use of the facility or of some equipment, or rejection of their request to use the facility or equipment. The Argon firmware produces distinctive sounds from the piezo buzzer when an accept or reject decision is made.
- Ready LED. A simple, green LED is used on the Station to inform a user that the Station is ready for them to tap their RFID card on the RFID reader.
- Admit indicator. A large, green LED indicator is used to provide visual feedback to users, and to other people in the vicinity of a Station, of acceptance of their RFID card and of their request for access to the facility or equipment (depending upon the Station type and location).
- Reject indicator. A large, red LED indicator is used to provide visual feedback to users, and to other people in the vicinity of a Station, of rejection of their RFID card or of their request for access to the facility or equipment (depending upon the Station type and location).

All of these station components are packaged into a custom enclosure that is assembled from laser cut panels. Complete CAD files for laser cutting the enclosure parts, as well as complete instructions and parts lists for assembling an RFID station are included in this repository.

Administrative Station Design.

The Administrative version of the RFID Station contains the same hardware and the same Particle firmware as all other versions of the RFID Station. In addition, the administrative version of the Station requires an Android device with an app called “MN_Card_Admin”. This app provides administrators with a user interface to:
- Query the EZ Facility database for the ClientID number for a member.
- Format RFID cards for members.
- Identify the contents and format of an unknown RFID card.
- Reset an RFID card that was previously formatted for Maker Nexus to a “factory fresh” state.
The app does not communicate directly with EZ Facility. The app communicates with the administrative Station’s Argon via the Particle cloud. The firmware on the Argon then communicates with EZ Facility using webhooks and Particle.publish() and Particle.subscribe() firmware commands.

The Android app(s) communicate with the Argon using Particle’s REST API to the Particle cloud. The Particle cloud, in turn, communicates with the Argon using Particle’s proprietary, secure internal protocols. A detailed description of the cloud functions and cloud variables involved in this interface is in the document “MN_Card_Writer_API” which is published in this repository.

RFID Station Type Selection.

An Android app called “MN_Station_Configurator” provides administrators with the ability to configure an RFID Station to be an administrative Station, a check-in Station, or any other type of Station (various flavors of location/equipment stations). All RFID Stations share the same hardware and firmware design. A Station is configured to become a certain type by using this app to select the desired type from a list of station types stored in the Facility Database. This station type list contains the station type, a type code for each type, and the criteria for accepting a member into the location/equipment associated with each station type. RFID Stations are configured with type codes in the range of 0 – 999. The type code definitions are otherwise flexible and are defined to meet the needs of any specific facility.

The same App is used to configure RFID Locks. RFID Locks have their own device types that are assigned codes in the range of 1000 and above. The App is also used to configure a “Lock Listen code” into each RFID Lock. The “Lock Listen code” is an RFID Station type that the RFID Lock responds to.

The MN_Station_Configurator app makes an http: or https: GET call to a php script on the Facility database server (“fdbGetStationConfig.php”). The URL, including the script call, is user-configurable within the app. The script queries the Facility Database and returns a JSON formatted list of station/lock types and their associated codes. The user then selects the desired station/lock type and commands the selected Station/Lock to become that type via a Particle.function() cloud call to the selected Particle device (selected station) (“setDeviceType(device type code)”). This cloud function can also be called with an argument of -1 (device types are positive numbers) after which the RFID Station returns the currently set device type to the app. RFID Locks support a second Particle.function() cloud call (“setLockListenType(device type code)”). This cloud function can also be called with an argument of -1 (device types are positive numbers) after which the RFID Lock returns the currently set Listen Code to the app.

After an RFID Station to configured to be a certain type via the setDeviceType() cloud call from this app, the station firmware uses a webhook “fdbGetStationConfg” to query the Facility Database to return a JSON formatted list of member admission criteria for the selected station type.

The “code” for this webhook is contained in this repository in the software folder in the file called “webhooks.txt”. PHP source code is in the Software folder of this repository.

Design for EZ Facility Access.

The Argon in an RFID Station communicates with EZ Facility using webhooks that are stored in the Particle cloud. These webhooks are only accessible to Particle devices that are claimed into the Maker Nexus administrative account. Webhook responses from EZ Facility are only returned to the Argon that published to that webhook.

The following webhooks are involved in the EZ facility interface:

- ezfClientByMemberNumber: queries EZ Facility for membership information based upon the Maker Nexus membership number. This interface is primarily used by the administration Station to look up member information needed to create an RFID card for a member. Member number can be found on the personal information page for each member in EZFacility. The member number can be a mix of letters and digits, and EZFacility enforces uniqueness.
- ezfClientByClientID: queries EZ Facility for membership information based upon the EZ Facility “ClientID” unique key. This interface is used by the administration and checkin Stations to look up member information. This information is needed to determine ownership and revocation status of an unknown RFID card, and to determine if a member has a current valid membership. ClientID is not easily discerned in the EZFacility user interface.
- ezfGetPackagesByClientID: queries EZ Facility for the packages (training records) that are registered for a member within EZ Facility. This interface is primarily used by location/equipment RFID Stations for member access control purposes.
- | ezfCheckInClient: | checks a client into EZ Facility for entrance into Maker Nexus.
EZFacility does not have the notion of “check out”.
- | ezfCheckInToken: | uses Maker Nexus secret information to obtain an OAUTH2 bearer
token that is subsequently used for secure access to EZ Facility in all of the other webhook API functions (above).

The “code” for these webhooks is contained in this repository in the software folder in the file called “webhooks.txt”.

Design For Facility Database.

The Facility Database is a mySQL database that is used for logging events generated by the RFID stations. Each record in the database contains:
- the RFID station local time
- the Particle coreID that generated the request
- the device function
- If the log record was made by an RFID station, this will be the function of the station at the time the request was made (Check In, Woodshop, Laser, etc)
- If the log record was made by another source, such as a PHP script, then that name will be in the field.
- the Particle EventName (this will be the webhook name)
- the clientID
- the client’s first name
- a log event name (this is the truly significant information)
- any log data

One important event is member check in and check out. EZ Facility only provides the capability to record member check-ins to Maker Nexus. The Facility Database records all Station events including facility check-ins and check-outs as well as location/equipment check-ins (access requests).

When an RFID Check-in Station posts a check-in event to the Facility Database system, the system checks to see if the user is already checked-in. If so, the system will enter a Checked Out record in the database. The system returns the action it took so that the RFID Station can inform the user if a check-in or check-out occurred.

The Argon in an RFID Station communicates with the Facility Database using webhooks that are stored in the Particle cloud. These webhooks are only accessible to Particle devices that are claimed into the Maker Nexus administrative account. Webhook responses from the Facility Database are only returned to the Argon that published to that instance of the webhook.

The following webhooks are involved in the Facility Database interface:

- RFIDlogging: logs an event supplied by the Argon firmware to the Facility Database. Logging data is passed to the webhook in a JSON package.
- RFIDLogCheckInOut: logs a check-in request for a ClientID. The Facility Database system returns a status of check-in or check-out that is passed to the RFID Station.

The “code” for these webhooks is contained in this repository in the software folder in the file called “webhooks.txt”.

The API to the Facility Database is a set of PHP scripts that run on the server hosting the Facility Database. Direct internet access to the Facility Database is disabled. There are two main PHP scripts:

- rfidcheckin.php: Called from the RFIDLogCheckInOut webhook. Logs a device “check-in allowed” event to the database. Queries the database to see if the ClientID has already checked in on this date. If not, a CheckIn record is created. If a CheckIn record exists, then a CheckOut record is created. The result of the operation is returned to the caller.
- rfidlog.php: Called from the RFIDlogging webhook. The event name and data are added to the database.
- rfidhome.html: Various reports from the database are available. These reports are all links on the rfidhome.html page.

The PHP source code that executes webhook transactions in SQL on the mySQL database is provided in the Software folder in this repository.

The Facility Database also contains a table that lists all station/lock types configured for a facility and the station/lock type codes and member admission criteria for each station type so defined. This table is managed by a facility administrator and is queried (only) by the station configuration app and by RFID Stations/Lock, as described in the section “RFID Station Type Selection”, above.

Security Design and Secret Information.

The security requirements for the RFID Access Control System project are satisfied using several techniques. Chief among these is the use of secret information to access key resources, such as authentication of RFID cards and access to member information in EZ Facility. This secret information includes access controls (passwords, secret numbers, and encryption keys), particularly to cloud based resources. Physical security over various aspects of the system, particularly administrative equipment, is also employed in the overall system design. It must be emphasized that the requirements dictate a moderate level of security. Hardware costs, administration costs, and member satisfaction weigh heavily into security-related design decisions.

RFID Card Security.

The RFID cards chosen are Mifare Classic 1K cards. These cards include the provision to encrypt data on the card, using 48-bit encryption keys. The key size is relatively small for modern day systems, and there are reports of these cards being hackable by other than brute force means. On the other hand, these cards are widely used as hotel room keys and for fare collection on public transit systems around the world. As such, they are widely available at very low cost and their widespread use is similar to the needs of Maker Nexus.

The primary use of RFID cards in this system is to identify and authenticate the holder of the card so that access control decisions can be made based upon the cardholder’s membership data stored in EZ Facility. The cards themselves hold data that is not particularly secret. The main security function required of these RFID cards is that they be difficult to clone (therefore, to forge). Members are expected to keep track of their RFID card and to use their card to identify and authenticate themselves (and nobody else) to the system. If a card is lost, Maker Nexus administration can issue a new card to the member in a manner that automatically revokes the old card(s).

Figure 4 depicts the layout of a Mifare Classic 1K card for use within the Maker Nexus RFID system.

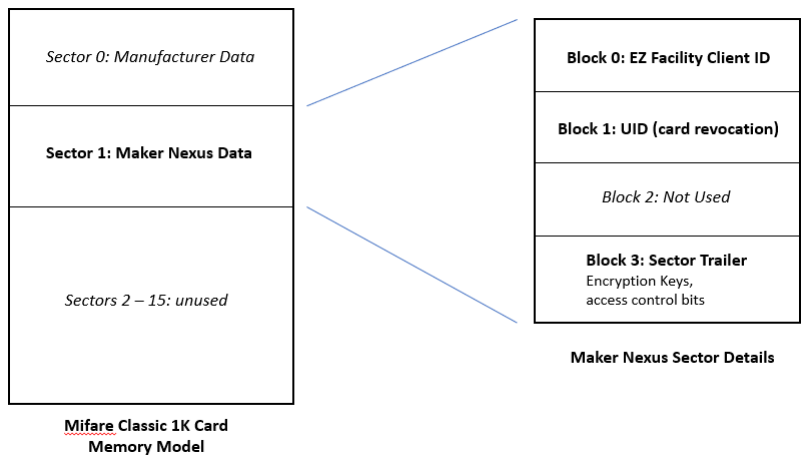
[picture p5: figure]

Figure 4. RFID card layout.

Classic 1K cards are divided up into “sectors”. There are 16 sectors on a 1K card. Each sector contains exactly 4 “blocks” of user read/write data; 16 bytes per block. The last block in each sector is called the “sector trailer” block and this block contains two 6-byte long encryption keys (key A and key B), as well as access control bits. The access control bits define how the keys are used for read/write/modify access to each of the 4 data blocks of the sector (i.e. the three user-defined data blocks and the sector trailer block). Each of the 16 sectors has its own sector trailer block and is independent of the remaining 15 sectors on the card.

The first sector of a Classic 1K card (sector 0) contains information placed there by the manufacturer and is left alone for the purposes of this project. The Maker Nexus data is nominally stored in sector 1 of each RFID card that is issued to a member. The remaining sectors are not used by this project and may be used for any other desired purpose.

Maker Nexus maintains two secret keys for all cards issued for this project. The keys are known only to a very few people and are stored in a secure location. The keys are included in file “rfidkeys.cpp”. Templates for these files, lacking the actual Maker Nexus secret keys, are included in the Software folder in this repository. These files actually contain 3 sets of keys:

- Factory default keys: these are the publicly known keys for all factory fresh cards. They are 0xFF (6 times) for key A and the access control bits allow key A to be used for reading and writing of all blocks inside of each sector (key B is not specified nor used).
- Maker Nexus secret keys: key A and key B are generated randomly and used to secure each card as it is formatted for Maker Nexus on an administration Station. Key A is used to read (only) data from the Maker Nexus sector and cannot be used to write data nor to modify access control bits for the sector. Key B can be used for reading, writing, and modifying data on all 4 blocks of the sector.
- Old Maker Nexus secret keys: in the event of a security breach, it is necessary to have the current secret keys (key B, in particular) available so that the sector trailer block of existing cards can be modified to accept new keys (or to reset existing cards back to factory fresh).

RFID Stations that are configured as administrative Stations configure the trailer sector of sector 1 to contain Maker Nexus secret keys A and B, and set the sector trailer access control bits to require Maker Nexus secret key A (only) to read data from blocks 0 and 1 of this sector. The sector trailer access control bits require Maker Nexus secret key B (only) to be used to change the contents of any data block (including the sector trailer block) of the Maker Nexus sector (sector 1).

All other RFID Stations use Maker Nexus secret key A (only) to read the contents of blocks 0 and 1 (of sector 1). Block 0 data is the EZ Facility ClientID and is used to query EZ Facility for member information needed to make an access control decision for that RFID Station. Block 1 data is an arbitrary string that is stored for each member in “custom field 1” of that member’s record in EZ Facility. When a new card is created for a member, the administrator (who is creating the card) enters an arbitrary number into custom field 1 of the member’s EZ Facility record and that number is then copied to data block 1 of the Maker Nexus sector on the newly written card (the EZ facility ClientID for that membership record is written to block 0 of the Maker Nexus sector of the newly created RFID card). When a member uses their card to check-in to the Maker Nexus facility or to a location/equipment within the facility, the RFID Station firmware uses the block 0 data (ClientID) to query EZ Facility for that member’s data and it checks that the returned data from EZ facility custom field 1 matches the block 1 data on the RFID card that was presented to the RFID station. The card is accepted only if these two data items match. This feature provides the required automatic revocation mechanism. A card may contain the correct encryption keys and a valid ClientID but if the card is an old one (one that has been replaced), the custom field 1 data from EZ Facility will not match that on the card and the card will be rejected as a revoked card.

Note: In our implementation RFID cards are issued to new members using the default null string in the “custom field 1” of the user’s EZ Facility record (In the EZ Facility administrative interface this field is labeled “RFID Card UID”). If a card is lost, the administrator will enter some arbitrary string in the “RFID Card UID” field before creating a new RFID card. This will have the effect of revoking the lost card.

It is important to understand that the encryption keys used on these RFID cards are really authentication credentials. The fact that these items of data (blocks 0 and 1) are encrypted is not particularly important to the overall security architecture of this project. These data items are not, in and of themselves, particularly secret. However, these data items cannot be read from an RFID card unless the appropriate encryption key is first used to authenticate a read or write operation on a particular sector. Therefore, security is provided in the sense that the card is unusable unless the RFID card Station can first authenticate the Maker Nexus sector (sector
1) with Maker Nexus secret key A. Furthermore, Maker Nexus secret key B is required to write data to any block in the Maker Nexus sector on these cards, as well as to change keys and access control bits for the Maker Nexus sector on these RFID cards. Therefore, these cards cannot be cloned or hacked unless the hacker knows the Maker Nexus secret keys. These secret keys are only stored in a special header file that is maintained only within the Maker Nexus production firmware build environment and which is accessible only by a few trusted Maker Nexus administrator/developers.

Note that the hardware design of the Classic 1K cards does not allow keys stored in the sector trailer block to be read, even by a bearer of the currently valid secret keys. If the secret keys are lost, the Maker Nexus sector on these cards become forever unusable.

It is always possible that a Maker Nexus secret key may be compromised. In this event, both secret keys will be changed. The header file that contains the new secret keys also contains the old secret keys, since the old keys (key B, in any event) are needed to change the Maker Nexus sector trailer block keys and access control bits to the new keys. In this manner, all currently issued RFID membership cards can be updated to use the new Maker Nexus keys.

The security features of the RFID cards described above also mean that a revoked card will need to authenticate with an RFID administration station using Maker Nexus secret key B in order to restore the card to a factory fresh state. An administration function is provided to do this, using the “factory fresh” default keys that are also stored on the secret key header file. A card can be reclaimed from a terminated member or from a revoked status by reverting the Maker Nexus sector on the card to its factory fresh state. This allows cards to be recycled and re-issued as if they were fresh “out of the box”, saving the cost of new factory fresh cards.

Station Security.

RFID Stations are mounted at various location throughout the Maker Nexus facility and are not physically secured from access by other than authorized personnel. However, the locations where these Stations are located a public and any tampering of a Station is, necessarily, a public event.

The use of Particle devices as the “brains” of each RFID Station provides a high degree of protection over software (firmware) tampering. There are only two ways to change the firmware on a Particle device: “flashing” the firmware over the Internet directly from the Particle cloud, or using “DFU mode” to flash firmware to the device over the device’s USB cable. Both of these methods require a secret OAUTH2 user access token and a Particle device ID to be presented to the device in order to flash new firmware to it. These two data items are long hex strings and are securely stored in the device owner’s account on the Particle cloud. Maker Nexus has an RFID administrative account on the Particle cloud that is used to “own” all RFID Station Particle devices and only people who know this account’s username and password can access the information/resources necessary to change a Station’s firmware. Two factor authentication is available from Particle for added security.

Firmware development and testing is performed on a separate “sandbox” clone of the entire Maker Nexus RFID system and on Particle devices that are owned by the developer(s) and are not part of the Maker Nexus deployed RFID Stations. After release to production is authorized, the new firmware is transferred to the production system by a select developer/administrator who has access to the production Particle account.

Cloud Security.

Maker Nexus cloud functions are maintained in an account that is accessible only to specifically designated administrator/developers. Access to this file requires knowledge of the secret password established for this account. Two factor authentication of administrator/developers is available and can be enabled for added security.

An open development environment has been created so that various firmware and cloud software developers can develop, test and maintain software for this project. A release-to-production procedure is in place to review new software and approve it for release. Release to the production system is then made by transferring the new software to the secret production account by an authorized administrator/developer, and building the system there using the real (production) secret keys.

Secret information that is needed to access EZ Facility via the REST API is contained within the webhooks located in the Maker Nexus Particle account. The same is true for access to the facility database. Only authorized administrator/developers have the secret password needed to access this account. Likewise, two factor authentication is available for added security. The RFID stations themselves do not contain the secret information needed to access either EZ Facility or the facility database.

Administrative Security.

All RFID Stations utilize the same hardware and firmware. This minimizes cost and logistics. A generic RFID Station is made into an administrative station via a cloud function call from the Maker Nexus Particle account, or via an App that has been created for this purpose. This account is only accessible to specifically designated authorized administrator/developers. Once a Station has been configured to be an administrative Station, the Station is physically secured (lock and key) so that only designated facility administrators can use it. Only administrative Stations have the capability to issue new cards, revoke old cards and reset cards to factory fresh condition. All other RFID Stations can only read cards and make access control decisions based upon data from EZ Facility, and EZ Facility data can only be obtained via webhooks that are only available to Particle devices that are registered to the Maker Nexus Particle administrative account. In general, there will be only one administrative Station, but the system design allows for multiple administrative Stations if there is a reason to have more than one such station.

Cost Effective Design.

Cost effectiveness is achieved through common hardware and firmware for all RFID stations. The hardware is based upon low cost Particle IoT devices. Very low cost character displays and RFID breakout boards have also been tested and documented in the parts list. Likewise, a low cost printed circuit board vendor has been identified and tested for the PCBs used to assemble station electronics.

Maker Nexus personnel have assembled enough generic RFID stations to meet the facility requirements for administration, check-in and location/equipment Stations, plus a few spares. Software developers purchase their own station hardware for development use. The deployed RFID Stations are configured by an administrator and the spare Stations are left generic so that a failed Station can easily and quickly be replaced by any available spare.

The choice of Classic 1K RFID cards for this project has already been cited as a compromise between security and cost. The cards are reasonably secure (when used as designed) and can be purchased for less than $0.30 a piece in low quantities (100 pcs) from multiple vendors on the Internet.

The need for additional user interface capabilities by administrators has been satisfied by an App for an Android device. Maker Nexus has purchased an Amazon 7” Kindle Fire tablet on a Black Friday sale for $30. An old Android phone will do as well. The App should run on just about any version of Android 2.5 or above.

# CONCEPTS FOR PROJECT USE BY OTHER

THAN MAKER NEXUS.

Some readers of this document intend to use this project as the basis of an RFID access control system for their own facility or organization. This section offers some guidance for various scenarios.

## Implement this project in a non-Maker Nexus Facility that uses EZ

Facility.

An organization that uses EZ Facility as its CRM system can adopt this project to their needs relatively easily. The Maker Nexus facility check-in process tests membership status and member payment information from EZ Facility to make the check-in access control decision. The card revocation feature also uses custom field 1 of each member’s EZ facility record to hold a number that represents the current member’s card. The Maker Nexus location/equipment check-in process retrieves package information for the member and tests that the member has a package(s) that permits them to access some location or item of equipment. The acceptable packages for each type of station are contained in a table in the Facility Database, so the relationship between packages and location/equipment access is configurable without code changes.

An organization that uses EZ Facility as its CRM system but requires different facility check-in rules than Maker Nexus uses will need to change the firmware accordingly. Additionally, the webhook for ezfClientByClientID may need to be changed if the Maker Nexus filtering rules don’t pass the necessary data through the webhook response back to the Argon firmware. Similarly, an organization that uses different location/equipment check-in rules than Maker Nexus may need to change the webhook for ezfGetPackagesByClientID if different filtering rules are needed to pass the webhook response back to the firmware. Note too that Maker Nexus names the packages in such a way as to make firmware testing for the necessary member package(s) easy. This part of the firmware should be studied carefully in order to determine how to accommodate different location/equipment access control rules. See the firmware functions: isClientOkToCheckIn() and isClientOkForWoodshop() for two examples.

## Implement this project in a non-Maker Nexus Facility that uses a

different CRM system than EZ Facility.

EZ Facility is not a general purpose relational database management system and the REST API is very specific to the EZ Facility schema. An organization that uses a different CRM system will have to change both the webhooks and the Argon firmware test rules in order to use this project in their facility. Alternatively, an organization may implement the relevant parts of their CRM system in a general purpose relational database management system. In this event, it might be possible to emulate the relevant EZ Facility API calls on such a system (e.g. via PHP/SQL) so that the webhooks and firmware can be used without any changes.

In general, all code that interfaces the CRM to the system can be found in firmware functions that begin with the letters ezf. Changing these functions and the webhooks will be needed.

## Implement this project in a non-Maker Nexus Facility that does

not have an electronic CRM system.

An organization that does not have an electronic CRM system (and does not wish to have one) could emulate the relevant EZ Facility API calls on a general purpose relational DBMS (e.g. via PHP/SQL). Since the facility database is such a DBMS, the same DBMS can be used to store tables containing membership status, membership dues and/or member “packages”. In so doing, the webhooks and firmware might be usable intact. Of course, an administrative front end would need to be developed to store and maintain the membership/package information in this database.

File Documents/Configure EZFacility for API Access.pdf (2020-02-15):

# Configure EZFacility for API Access

EZFacility (EZF) is our CRM solution. When an RFID card is tapped on a Station, the Station reads from the CRM service to verify the credentials and access rights associated with the clientID that is stored on the RFID card.

The RFID Station communicates with internet resources via the Particle.io cloud service called webhooks.

This short document explains how to configure the various systems to allow a Particle.io webhook to access EZF.

# API Client vs EZF User

The EZF API uses OAuth to handle authentication. An external application presents credentials and obtains an OAuth token that is good for some period of time (currently one hour). This application passes this token to EZF with every API call.

To obtain an OAuth token you need four pieces of information.
- EZFacility API Client and Client Secret
- EZFacility instance User and Password with the appropriate permissions

It is easy to confuse these two credentials, and that is the source of a lot of frustration. As you read the rest of this document please keep these two sets of credentials in mind.

# Sandbox or Production?

An important concept is that EZF provides you with both your Production CRM instance (of course) and a “sandbox” instance that contains some data, but is completely disconnected from your production instance. Each instance has its own credentials. Any work you do using the sandbox credentials are not charged to your account and can not affect your production instance.

EZF also has a very nice web page that lets you test the API calls to get a feeling for how they work. Unfortunately the web page for your Production instance looks identical to the web page for your Sandbox instance; the only difference is in the URL. BE VERY CAREFUL.

In addition, it seems that while an API Client can be designated for Sandbox, if paired with the correct URL and EZFacility User, it can modify your Production instance. BE VERY, VERY CAREFUL.

On top of all this, the API Client information is encoded in a way that is impossible for a human to verify on sight. Did we already mention: BE CAREFUL?

For this reason we strongly suggest you have different EZFacility Users in your Production and Sandbox account, and that you name them in a way that indicates Production vs Sandbox. For example, “SandboxUser1” and “ProductionUser1”. The EZF User credentials are easy for you to verify on visual inspection and are specific to the instance that hosts them.

# Step by Step

1. Establish an EZFacility API account.
a. At https://developers.ezfacility.com/
2. Create an API Client
a. Log on to https://developers.ezfacility.com/
b. Create an Application
i. Sandbox or Live
ii. Wait about 24 hours for an activation confirmation from EZF
c. Once activated you can return to the developers site, click on the Application name and obtain two important pieces of information: Client ID and Client Secret.

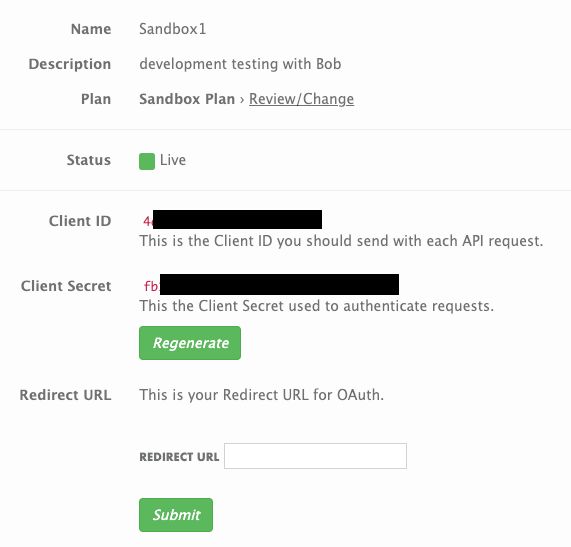
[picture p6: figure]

3. Create an EZFacility User in the correct system
a. Choose Production or Sandbox and log in
i. Production: https://tms.ezfacility.com
ii. Sandbox: https://tms-ua.ord.ezfacility.com/
b. Go to Administration / User Administration / Role Administration i. Create a role called API Checkin
ii. Remove all permissions from this role except:
1. Exempt From Login IP Address Restriction
2. View Client List
3. View Clients
c. Go to Administration / User Administration / User Administration
i. Add a user with the name API Checkin.
1. Generate a password.
2. Assign this user the role API Checkin ii. Add a user with the name API ReadOnly
1. Generate a password
2. Assign this user the role Read Only
4. Test in the API sandbox page.
a. We will assume you are testing sandbox credentials.
b. Go to https://api.sandbox.ezfacility.com/swagger/ui/index#/
c. Enter the four pieces of credential info in the boxes shown

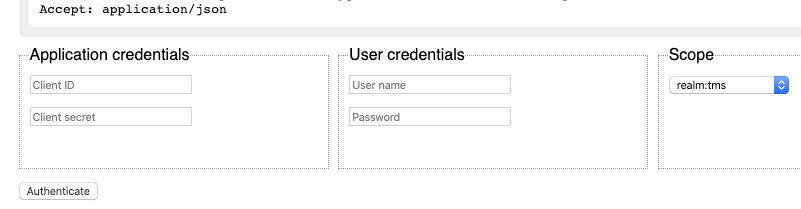
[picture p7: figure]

d. Click Authenticate and wait for a pop up that says “ok”
e. If you don’t get the OK pop up, then something is not right.
5. Authentication String
a. Now you will build the string necessary for web access. You will need the API Client ID and Client Secret.
b. Use a text editor (not a WYSIWYG editor) like Notepad to create the following string: Client ID:Client Secret
c. B64 encode this string. (You can use a web based tool: https://www.base64encode.org/ )
d. Record this string and use it with the instructions on configuring your Particle.io webhooks.
e. Example:
i. Client ID: 4538976
ii. | Client Secret: 874f9a76cd0325efb4a3ab98c
iii. | Create: 4538976:874f9a76cd0325efb4a3ab98c
iv. | B64 encoded:
| NDUzODk3Njo4NzRmOWE3NmNkMDMyNWVmYjRhM2FiOThj

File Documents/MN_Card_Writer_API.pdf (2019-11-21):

# Maker Nexus Card Writer API

Version 1.2; by: Bob Glicksman & Jim Schrempp; 10/05/19

Overview.

The Maker Nexus Card Writer application will consist of two parts:

- GUI -- the GUI will be an AI2 app that provides a user interface for a Maker Nexus administrator.
- Particle Firmware -- firmware for an Argon or Xenon that communicates with an RFID card and with EZFacility in order to implement the function selected by the administrator via the GUI.

The detailed requirements are contained in a separate Concept and Requirements document:

https://docs.google.com/document/d/13DphSTjkPGKusOAcMALxCAwIjKkrsXL4rh26epaUW9I/edit#heading=h.jfvwj4z7t60w (https://docs.google.com/document/d/13DphSTjkPGKusOAcMALxCAwIjKkrsXL4rh26epaUW9I/edit)

This document describes the API between the GUI and the Firmware. The API uses Particle.function() to expose functions in the Firmware to the Particle Cloud, Particle.variable() to expose variables to the Particle Cloud, and the Particle REST interface to communicate GUI commands and status over the Internet to the Particle Cloud.

The Card Writer consists of three functions:

- Make a factory fresh card into an MN formatted card for a specific member.
- Reset an MN formatted card to factory fresh condition
- Identify an unknown card

Format a Factory Fresh Card for a Member.

The GUI will have a text box for the administrator to manually type in the Membership Number for the member for whom a card is to be produced. The GUI will have a button that activates the firmware to query EZFacility by membership number and return and display membership information from EZFacility for verification by the administrator. Once the administrator has verified that the member is the correct one, another button will become available to command “burning” the RFID card for that member.

The function prototype for asking the firmware to look up the member by number in EZFacility will be as follows:

int queryMember(String memberNumber);

Where:
memberNumber is a String representation of the number typed into the GUI by the administrator.

The return value is an int with the following encoding:

0 = query accepted
1 = query is underway
2 = query is done and results are in the cloud variable (including any error report) 3 = query was already underway, this query is rejected
4 = memberNumber was not a number or was 0
5 = other error, see LCD panel on device

The expected success pattern is to call queryMember and get a 0 return code. Then poll queryMember with the same memberNumber every one second. If a poll returns 1, poll again in one second. If a poll return 2, then access the cloud variable. At some point the application will stop polling, assuming the firmware has failed to respond correctly.

Successful query will load the JSON representation of member data from EZ Facility into the cloud variable:

String queryMemberResult;

Where queryMemberResult is JSON formatted name:value pairs. The GUI will present each JSON name as a literal and each JSON value next to the variable name. The returned name:value pairs shall be:

ErrorCode: 0
ErrorMessage: OK
Name : Bob Glicksman
ClientID : 12345678
Status : Active
Checkin: Allowed (or another message that would be displayed if a checkin is attempted)

Where ErrorCode is
0 = member found and membership data is in the JSON.
1 = member not found in EZFacility
2 = more than one member found in EZfacility (this should be impossible)

3 = other error.

ErrorMessage is a short string in English, suitable for display to a user.

Note that other information may be provided in the JSON response as deemed appropriate from the information that is in EZ Facility. The purpose of this information is for the administrator to verify that the card is being made for the correct member (e.g. that they did not mistype the membership number). The application should display the required fields to the user (as specified above). Additional information in the JSON response may be displayed if it is decided that this additional information is helpful to the administrator and does not unduely compromise member privacy.

At this point the LCD on the device will display “Selected User” and the user’s name.

After return of correct membership information, the GUI will present a “burn card” button to the administrator. Tapping this button will result in the following Cloud function call:

int burnCard(String clientID);

Where:
clientID is a String representation of the clientID that was returned in the membership information JSON response above

The return value is an int with the following encoding:

0 = function called successfully; follow instructions on the LCD 1 = failed to contact card reader/writer

The user will be prompted on the LCD panel and/or LEDs when to remove the card and what the burn status is (good or fail).

Note that prompts for the administrator to place the card on the card writer and to subsequently remove the card will be performed by the Firmware using the hardware LCD (rather than the GUI). The LCD is right where the card is to be placed and is therefore the logical place for such user prompting.

If the burnCard function is not activated within a timeout period after the memberQuery call, the device firmware will clear itself and return to a ready state.

Reset a MN Card to Factory Fresh.

A member resigns and turns in their card. The cards are not expensive, but we might as well recycle them. The easiest way to recycle a card is to make it factory fresh. Otherwise, we rely on the MN format staying the same -- i.e. the secret keys not changing. If we change keys and forget about recycled cards, they become useless. Factory fresh always has known default keys. The function will only reset cards that are valid with the most recent previous encryption write key. Cards constructed with older encryption write keys cannot be reused.

The GUI will have a button to select this function. The button will result in the following Cloud function call:

int resetCard();

The return value is an int with the following encoding:

0 = function called; follow instructions on the LCD panel
1 = failure to contact the card reader/writer hardware
2 = device is busy with other operation

Note that prompts for the administrator to place the card on the card writer and to subsequently remove the card will be performed by the Firmware using the hardware LCD (rather than the GUI). The LCD is right where the card is to be placed and is therefore the logical place for such user prompting.

Test A Card.

This function is used for several things.
1. If a card is found with out any markings, this function can be used to read the card and determine who it belongs to, if it is bad, or some non-MN format.
2. Once a card has been burned, this function can be used to verify that the card has been correctly burned.
3. If a member has failed to checkin (red light) this function can be used by a manager in the office to discover why a member’s checkin failed and discuss the issue privately with the member.
4. If a member corrects the problem that caused the failed checkin (e.g. paid their outstanding balance) this function can be used to verify that the card will successfully work at a checkin station now.
5. If a member is incorrectly denied checkin (red light) the manager can use this function to test the card as they attempt to correct the problem.

The GUI will have a button to select this function. The button will result in the following Cloud function call:

int identifyCard();

The return value is an int with the following encoding:

0 = query for member data initiated
1 = query is underway (return in one second)
2 = query complete; card owner data is in the string memberInformation
3 = unknown error

When the function returns < 2 the application will wait 1 second and then call again. Successful query will load the JSON representation of member data from EZ Facility into the cloud variable:

String identifyCardResult;

Where identifyCardResult is JSON formatted name:value pairs. The GUI will present each JSON name as a literal and each JSON value next to the variable name. The returned name:value pairs shall be:

- ErrorCode: 0
- ErrorMessage: OK
- Name : Bob Glicksman
- Member Number : 7654
- Card Status : Current (alternative: Revoked)
- Checkin: OK (Status of what would happen if the card was presented to a checkin station)

Note: the parameters above are mandatory. The Card Status is the result of comparing the MN card UID on the card with that in the member’s record in EZ Facility. The card status is Current if they match and Revoked if they don’t match.

Note that prompts for the administrator to place the card on the card writer and to subsequently remove the card will be performed by the Firmware using the hardware LCD (rather than the GUI). The LCD is right where the card is to be placed and is therefore the logical place for such user prompting.

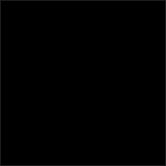
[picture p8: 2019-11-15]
Hardware/Enclosure/Enclosure_CAD_Files/pn532_sink_44_44.png

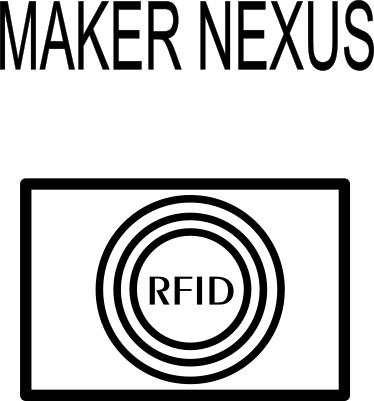
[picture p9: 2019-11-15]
Hardware/Enclosure/Enclosure_CAD_Files/mn_text_and_rfid.png

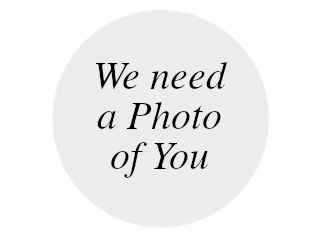
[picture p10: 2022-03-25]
Software/Facility_Database_SW/datalogging/WeNeedAPhoto.png

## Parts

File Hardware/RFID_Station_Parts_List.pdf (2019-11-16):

LOCATION | ITEM | Part Number | Qty | Description | Vendor | URL | Unit Price Total price NOTES | ALT Supplier
PCB | 1 | 1536 | 1 | Piezo Buzzer - 5 volt | Adafruit https://www.adafruit.com/product/1536 | $0.95 | $0.95
PCB | 2 | 2886 | 1 | Headers for Argon (Feather) | Adafruit https://www.adafruit.com/product/2886 | $0.95 | $0.95
PCB | 3 | 392 | 1 | Male pin headers, 10 x 36 | Adafruit https://www.adafruit.com/product/392 | $4.95 | $4.95
PCB | 4 | 43001 | 1 | Potentiometer - 10K ohm | Jameco https://www.jameco.com/z/72PR10K-3386P-1-
| | | | | | 103--BI-Technologies-1-2-Watt-3-8-Square- Trimming-Potentiometer-10k- Ohm_43001.html?CID=MERCH (https://www.jameco.com/z/72PR10K-3386P-1-103--BI-Technologies-1-2-Watt-3-8-Square-Trimming-Potentiometer-10k-Ohm_43001.html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)
$1.25 | $1.25
PCB | 5 | 2781 | 1 Resistor, 470 ohm; pack of 25 | Adafruit https://www.adafruit.com/product/2781 | $0.75 | $0.75 Need 3 resistors
PCB | 6 | 2783 | 1 Resistor, 4.7 Kohm; pack of 25 | Adafruit https://www.adafruit.com/product/2783 | $0.75 | $0.75 Need 3 resistors
PCB | 7 | 1787 | 1 74AHCT125 quad level shifter | Adafruit https://www.adafruit.com/product/1787 | $1.50 | $1.50
PCB | 8 | 112214 | 1 | IC socket, 14 pin DIP, 0.3" | Jameco https://www.jameco.com/z/6000-14DW-R-
| | | | Socket-IC-14-Pin-Dual-Wipe-Low-Profile-0-3- Inch-Wide_112214.html (https://www.jameco.com/z/6000-14DW-R-Socket-IC-14-Pin-Dual-Wipe-Low-Profile-0-3-Inch-Wide_112214.html) | $0.25 | $0.25
PCB | 9 | 3997 | 1 | Particle Argon | Adafruit/Particle https://www.adafruit.com/product/3997 | $27.50 | $27.50 | https://store.particle.io/collections/wifi/products/arg
| | | | | | | | on (https://store.particle.io/collections/wifi/products/argon)
PCB | 10 | 753 | 1 | Capacitor, 0.1 uF; 10 pack | Adafruit https://www.adafruit.com/product/753 | $1.95 | $1.95 Need 6 capacitors | https://www.jameco.com/webapp/wcs/stores/servle
| | | | | | | | t/ProductDisplay?langId=-
| | | | | | | | 1&storeId=10001&catalogId=10001&productId=2552
| | | | | | | | 3 (https://www.jameco.com/webapp/wcs/stores/servlet/ProductDisplay?productId=25523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)
PCB | 11 | | 1 | Printed circuit board | OSHPark https://oshpark.com/shared_projects/QX8CtBIz | $36.15 | $36.15 Much cheaper boards are available from
| | | | | | | JLCPCB.com. Upload the zip archive found
| | | | | | | in Hardware/PC_board/Eagle Files to this
| | | | | | | site. Use the default board settings that
| | | | | | | are presented. | https://jlcpcb.com/
S/T PCB: | $76.95
BOX | 2289807 | 1 USB Power supply, 5 volts, 1 amp or greater

Jameco https://www.jameco.com/webapp/wcs/stores/servlet/ProductDisplay?productId=2289807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 (https://www.jameco.com/webapp/wcs/stores/servlet/ProductDisplay?productId=2289807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)

$3.95 | $3.95
BOX | 222608 | 1 USB Cable, 3 feet or longer, A male to B male

https://www.jameco.com/z/10U2-02203-BK-Cable-USB2-0-A-B-3-Feet-Black-USB-A-Male-To-USB-B-Male_222608.html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 (https://www.jameco.com/z/10U2-02203-BK-Cable-USB2-0-A-B-3-Feet-Black-USB-A-Male-To-USB-B-Male_222608.html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)

$1.49 | $1.49
BOX | 937 | 1 Cable, USB B panel mount to
micro USB
Adafruit https://www.adafruit.com/product/937 | $3.95 | $3.95
BOX | 1 | LCD character display. 16x2,
3.3 volt

EBay https://www.ebay.com/itm/DC-3-3V-HD44780-1602-LCD-Display-Module-16x2-Character-LCM-Blue-Blacklight-NEW/191563253688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 (https://www.ebay.com/itm/DC-3-3V-HD44780-1602-LCD-Display-Module-16x2-Character-LCM-Blue-Blacklight-NEW/191563253688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)

$2.19 | $2.19 Make sure to purchase a 3.3 volt model
(not 5 volt!)
BOX | 34761 | 1 | LED, 5 MM, Green | Jameco https://www.jameco.com/z/LG3330-LED-Uni- Color-Green-565nm-2-Pin-T-1-3- 4_34761.html?CID=MERCH (https://www.jameco.com/z/LG3330-LED-Uni-Color-Green-565nm-2-Pin-T-1-3-4_34761.html?CID=MERCH)
$0.15 | $0.15
BOX | 1439 | 1 | Backlit pushbutton, Red | Adafruit https://www.adafruit.com/product/1439 | $1.50 | $1.50
BOX | 1440 | 1 | Backlit pushbutton, Green | Adafruit https://www.adafruit.com/product/1440 | $1.50 | $1.50
| 23077 | 1 | 5 MM LED panel mount kit
| | | (10 pack) | Jameco https://www.jameco.com/z/PT18H013-LED-
| | | | Mounting-Hardware-T1-3-4-Black_23077.html (https://www.jameco.com/z/PT18H013-LED-Mounting-Hardware-T1-3-4-Black_23077.html) | $0.17 | $0.17 Need 1 panel mount
BOX | 1 | RFID Reader, PN532 chip | Ebay https://www.ebay.com/itm/1set-PN532-NFC- RFID-Wireless-Module-V3-User-Breakout-For- Arduino-For-Android/183458101571 (https://www.ebay.com/itm/1set-PN532-NFC-RFID-Wireless-Module-V3-User-Breakout-For-Arduino-For-Android/183458101571)
$4.74 | $4.74
BOX | 2260746 | 1 | Jumper, Female/Female (40 wire strip)

Jameco https://www.jameco.com/z/ZW-FF-20-Busboard-Prototype-Systems-ZipWire-40-Piece-20cm-Female-to-Female-Colored-Jumper-Wires_2260746.html (https://www.jameco.com/z/ZW-FF-20-Busboard-Prototype-Systems-ZipWire-40-Piece-20cm-Female-to-Female-Colored-Jumper-Wires_2260746.html)

$4.95 | $4.95 Need 27 wires | https://www.amazon.com/gp/product/B01L5ULRUA/
ref=ppx_yo_dt_b_asin_title_o02_s00 (https://www.amazon.com/gp/product/B01L5ULRUA/ref=ppx_yo_dt_b_asin_title_o02_s00)
BOX | 1 | Enclosure parts kit | ------------ ------------------------- | $0.00 Laser cut enclosure; see CAD files in this
| | | | repository
BOX | 1 | Machine screw, flat head,
| | phillips, M3-0.5 x 16 mm | Amazon https://www.amazon.com/gp/product/B000NH
| | | VQXU/ref=ppx_yo_dt_b_asin_title_o02_s01 (https://www.amazon.com/gp/product/B000NHVQXU/ref=ppx_yo_dt_b_asin_title_o02_s01)
$4.40 | $4.40 Need 8 screws; price is for a pack of 100
| | | | scews
BOX | 1 | Machine screw, socket cap,
| | hex drive, M3-0.5 x 16 mm | Amazon https://www.amazon.com/gp/product/B07BS9
| | | TWP5/ref=ppx_yo_dt_b_asin_title_o02_s02 (https://www.amazon.com/gp/product/B07BS9TWP5/ref=ppx_yo_dt_b_asin_title_o02_s02)
$8.99 | $8.99 Need 8 screws; price is for a pack of 100
| | | | scews
BOX | 1 | Hex nut, M3, black carbon
| | steel | Amazon https://www.amazon.com/gp/product/B07H1N
| | | PJGP/ref=ppx_yo_dt_b_asin_title_o02_s00 (https://www.amazon.com/gp/product/B07H1NPJGP/ref=ppx_yo_dt_b_asin_title_o02_s00)
$6.99 | $6.99 Need 8 nuts, prince I for pack of 150 nuts
BOX | 1 | Hex nut, M3, nylon | Amazon https://www.amazon.com/gp/product/B07DX6 RBFS/ref=ppx_yo_dt_b_asin_title_o02_s02 (https://www.amazon.com/gp/product/B07DX6RBFS/ref=ppx_yo_dt_b_asin_title_o02_s02)
$8.99 | $8.99 Need 16 nuts (8 for spacers, 8 for
fastening). Price is for a pack of 200 nuts
S/T BOX: | $53.96
TOTAL: | $130.91

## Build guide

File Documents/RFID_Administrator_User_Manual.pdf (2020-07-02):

# RFID Administrator User Manual

By: Jim Schrempp, Bob Glicksman and Mike Calyer; v3, 6/24/2020

© 2020 Team Practical Projects, Maker Nexus, Bob Glicksman, Jim Schrempp and Mike Calyer. All rights reserved.

NOTICE: Use of this document is subject to the terms of use described in the document “Terms_of_Use_License_and_Disclaimer” that is included in this release package. This document can be found at:

https://github.com/TeamPracticalProjects/MN_ACL/blob/master/Terms_of_Use_License_and_D isclaimer.pdf

© 2019/2020, Team Practical Projects, Maker Nexus, Jim Schrempp, Bob Glicksman and Mike Calyer; all rights reserved. Subject to “Terms of Use, License and Disclosure”

TABLE OF CONTENTS.

TABLE OF CONTENTS. | 1
OVERVIEW. | 2
Station Configurator App. | 5
Station Configurator App Installation and Setup. | 9
Installation. | 9
App Setup. | 9
Station Configurator App User Instructions. | 17
Setting the Station Type for an RFID Station. | 17
Setting the Station Type and Lock Listen code for an RFID Lock. | 22
Card Administration app. | 26
Card Administration App Installation and Configuration. | 27
Installation. | 27
App Setup. | 28
Card Administration App User Instructions. | 33
Making an RFID Card for a Member. | 36
Get Ready | 37
Android Tablet | 38
Maker Nexus ADMIN Box | 38
Blank RFID Cards | 39
Get the Member Number | 39
The Process | 39

OVERVIEW.

RFID Administrators are responsible for:

1. Configuring RFID Stations and RFID Locks to be a specific type (check-in, administration, woodshop etc).
2. Managing RFID cards that are issued to users/members of an organization.

Two Android apps are used by Administrators to perform these functions:

1. Station Configurator App: this app allows Administrators to configure RFID Stations/Locks to become a specific type of station, including configuring one or more RFID Stations to become Admin stations. An Admin station works alongside the second app – “Card Administration App” – to provide the ability to make RFID cards for users, reset RFID cards to factory fresh condition, and to identify unknown RFID cards. This app also allows Administrators to configure RFID Locks to respond to events published by specific RFID Station types (e.g. to open a cabinet when a user successfully taps into some specific location/equipment within their facility).
2. Card Administration App: this app works alongside an RFID Station that has been configured as an Admin station to provide RFID card administration capabilities.

These two apps can run on pretty much any Android tablet or phone; even very old ones. Administrators can use their own Android phones to host these apps or can be provided with a device dedicated for this purpose that is kept alongside an Admin RFID Station. We have found that a very cheap Kindle Fire 7” tablet ($50 list, $30 on sale) works fine for this purpose.

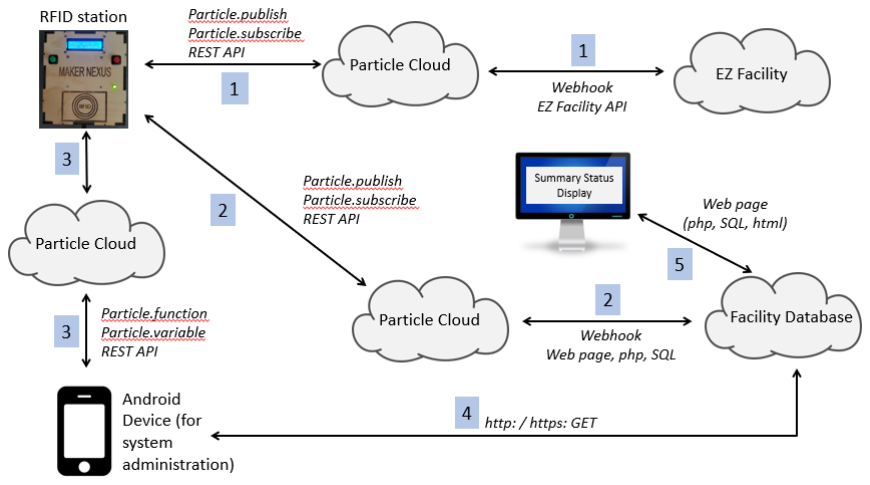
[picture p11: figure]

Figure 1-1. RFID System Architecture.

Figure 1-1 depicts the overall RFID system architecture. The Android device is shown in the lower left part of this figure. The Android device that hosts these two apps must have Internet access; usually via WiFi (but cellular will work equally well).

The Station Configurator App running on this device communicates with a web server/PHP script that returns a list of station type names and associated station type codes that are specifically tailored for the facility or organization that uses this RFID Access Control System. The Station Configurator App communicates with a selected RFID Station (it’s Argon processor) over the Internet (via the Particle cloud) to command the Station to become a certain type and to query the Station for the type that it is currently configured to be. The Station Configurator App also communicates with a selected RFID Lock device¹
(it’s Photon processor) over the Internet (via the Particle cloud) to command the Lock device to become a certain device type and to listen for unlock events from a specific RFID Station type. The Station Configurator App can also query RFID Lock devices for their current device type and “Lock Listen type code”.

The Card Administration App running on this device communicates with a selected RFID Station (it’s Argon processor) over the Internet (via the Particle cloud) to command the Station to query the CRM system for user/membership information. This information is then used to make a factory fresh RFID card into a Maker Nexus formatted card specific to that user. Other functions performed by this App are: reset a Maker Nexus formatted card back to factory fresh condition; query an unknown RFID card about its formatted type and owner (if the card is Maker Nexus formatted).

1 See “https://GitHub.com/TeamPracticalProjects/RFID_Lock”

We suggest that at least one RFID Station be configured as an Admin station and kept in a secure location alongside an Android device that has these two apps installed on it. Although the Android device containing these two apps can be secured via biometrics, password and/or PIN, we strongly recommend adding a layer of physical access security so that only properly credentialed Administrators can manipulate RFID Stations, RFID Locks, and RFID cards.

Further information about RFID card formats, RFID system architecture, EZ Facility, the Facility database, security, etc. can be found in the document “RFID_ACS_Overview_Document” that is in the “Docs” folder in this repository.

STATION CONFIGURATOR APP.

The Station Configurator App is used to command an RFID Station/Lock to become a certain station type. The station types (their type names and type codes) are stored in a table in the Facility Database and can be tailored specifically to the needs of your Facility or Organization.

Every RFID Station and RFID Lock must be configured with a station type. The station type defines the criteria for an RFID Station to accept or reject a tapped RFID card. The station type defines the application (e.g. cabinet location) for an RFID Lock. RFID Station types are assigned type codes 0 – 999 and RFID Lock types are assigned codes >= 1000.

RFID Stations publish an event to the Particle cloud whenever a successful user card tap-in occurs; i.e. when the RFID Station green “OK” light comes on. This event publication contains the station type code of the RFID Station that published the event. RFID Lock devices subscribe to these events and determine if they should unlock based upon the RFID Station type code that is encoded in the event. The RFID Station code that any specific RFID Lock should respond to is called the “Lock listen code” and must be configured into every RFID Lock in the facility. Since “Lock Listen codes” are RFID Station types, these codes will be in the range of 0 – 999.

Every RFID Lock must be configured with its own, unique station type; codes 1000 and higher. Every RFID Lock must also be configured with a station type code to which it is to respond (“Lock listen code”; in the range of 0 – 999). Each RFID Lock can respond (e.g. unlock a cabinet) to one station type. That is to say, an RFID Lock must be configured with a designated device type (e.g. “laser cutter key cabinet”, e.g. type code 1001) and a “Lock listen code” (e.g. “Lasers” RFID Station; e.g. type code 105). In this example, an RFID Lock is installed on a cabinet that contains a key to enable a laser cutter and miscellaneous laser cutter tools. When a card is tapped-in at the laser cutter RFID station (code 105 in this example), the RFID Station publishes an event which all RFID Locks subscribe to. The RFID Lock with station type code 1001 (defined to be the Lock on the laser cutter key cabinet) will unlock the cabinet when there is a successful tap-in at the laser cutter RFID Station because Lock device type 1001 has been configured to respond to events with device type code 105.

Many different RFID Locks may be configured to respond to one station type (i.e. successful tap-in on one RFID Station may unlock several cabinets), but any given RFID Lock can only respond to events from one station type²

2 There can, of course, be multiple RFID Station of the same type; e.g. facility check-in stations at each entrance to the facility. Tapping in at any of these stations will trip the lock on all RFID Lock devices that listen for this station type code.

Station/Lock type codes and Lock listen codes are specific to a facility and are defined by the facility administration via a table in the Facility Database.

Figure 2-1 shows an overview of the Station Configurator App:

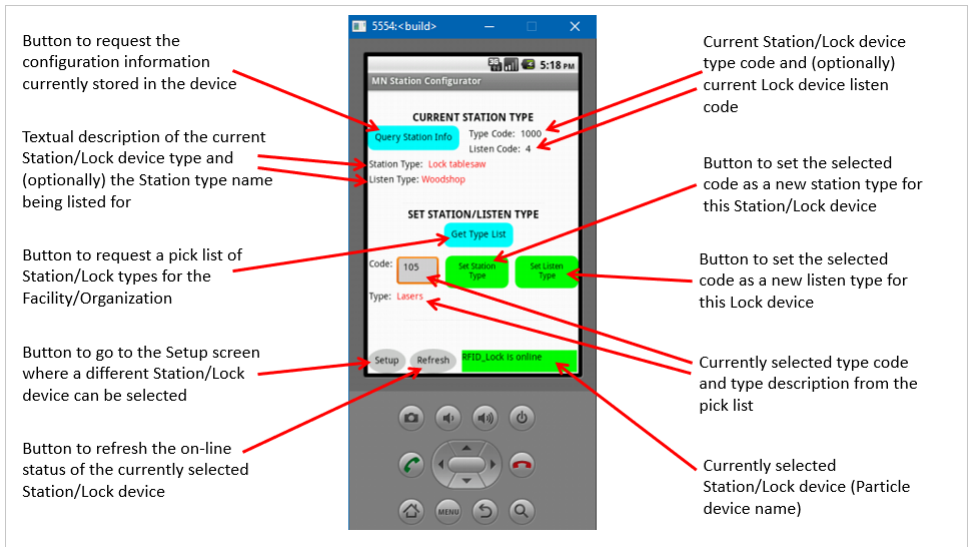
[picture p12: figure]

Figure 2-1. Station Configurator App Functional Overview.

The top section of this App is used to obtain the currently set station type of the selected RFID Station and the Lock listen code and type if it is an RFID Lock³
. The name of the currently selected RFID Station/Lock (its Argon/Photon processor) is shown at bottom right of the App screen. Note that the RFID Station/Lock must be on-line (powered and communicating with the Particle cloud) in order for this App to be able to communicate with it. Tapping the “Query Station Type” button requests this information from the RFID Station/Lock. The RFID Station/Lock returns its current station type code (and, optionally, its Lock listen code), which is displayed next to the “Query Station Type” button (e.g. Type code = “1000”, Lock code = “4”). The name of the Station Type (e.g. “Lock tablesaw”) that is associated with the station type code and (optionally) the Listen type (e.g. “Woodshop”) are displayed directly beneath the “Query Station Info” button. When an RFID Station (but not an RFID Lock) is queried for its type, it will also beep; this lets you be certain that you are communicating with the correct RFID Station.

The middle section of this App is used to request a pick list of Station/Lock listen types and the selected station type code and type name are displayed on the screen in the designated areas shown in figure 2-1. The “Set Station Type” button can then be used to command the selected

3
If the device is an RFID Station type, then the Lock listen code and Lock listen types are blank.

RFID Station to change to the designated station type. Similarly, the “Set Listen Type” button can be used to command an RFID Lock to change to change to the designated Listen type⁴ .

Maker Nexus has currently defined five categories of RFID Stations and RFID Locks:

1. “Default” station type (type 0): This is the default type before any other type is commanded for the selected RFID Station. This type provides only hardware testing capabilities.
2. “Admin” station type (type 2): this station type provides RFID card administrative capabilities, in conjunction with the Card Administration App which is described further down in this document.
3. “Check-in” station type (type 1): this station type allows users/members to check in and check out of the facility. Several of these station types may be mounted at each entrance/exit to the facility.
4. “Location/Equipment” station type (various other type codes in the range 3 - 999): stations of this type are placed by specific items of equipment or equipment locations within the facility where users/members are expected to tap their membership RFID card to indicate their desire to use items of equipment associated with the RFID Station’s location.
5. RFID Lock station types (codes 1000 and above): these type codes are assigned to RFID Locks. The fact that the code is >= 1000 defines that the device is an RFID Lock to the Station Configuration app. This is how the app knows to allow or disallow setting of a Lock listen code into the device.

The bottom section of this app contains two buttons and a display field. The “Setup” button is used to change over to the Setup screen of the App where a different RFID Station/Lock can be selected and where the URL of a script to return the station type name and code table is located. The “Refresh” button is used to ping the selected RFID Station/Lock for its current status – e.g. if it is off-line and then is brought on-line, “Refresh” can be used to verify that the Station/Lock is indeed on-line. The display field at the bottom right of the screen displays the name of the RFID Station/Lock (name of its Argon or Photon processor) and its current status. The device is on-line and OK if the background of this field is green; it is not on-line or otherwise not OK if the background of this field is red; it is waiting for a ping response from the device if the background is yellow.

When the App is first installed on an Android device, it must be set up. Complete instructions for setting up the App are below.

4
If the station type is in the range 0 – 999, then the “Set Listen Type” button will be inactive and grayed out.

Station Configurator App Installation and Setup.

Installation.

The installation file is called MN_Station_Configurator.apk. It can be found in this repository:

Software/Android_Apps/StationConfigApp/MN_Station_Configurator.apk

In order to install this app on your Android device, you must transfer this installation file to your device. There are several ways to do this; here are three suggestions:

- Downloading: Download the file MN_Station_Configurator.apk to your Android device using a web browser on the device. Make sure that you know the folder on the Android device where the browser stores downloaded files.
- Sideloading: Download the file MN_Station_Configurator.apk to your desktop or laptop computer. Attach a USB cable from your desktop/laptop to your Android device. The Android device’s flash memory should appear as a drive on your computer. Drag and drop the installation file to a location on the Android device where you will be able to find it later.
- E-mail: Download the file MN_Station_Configurator.apk to your desktop or laptop computer. Email this file to yourself as an attachment. Open email on your Android device and download the attachment, making sure that you know where the email program/browser stores attachments.

Regardless of the method that you use to get the file MN_Station_Configurator.apk onto your Android device, you now use a file explorer on your device to locate the file and tap on it to start the installation. The App should now install on your Android device. NOTE: you may get a message on your Android device saying that the app is “untrusted” or “unverified”. This means that Android knows that the App did not come from the Google play store. Go ahead and install it anyway – it is safe! The installer will list the permissions that the App needs to run. Go ahead and accept them. The App should install properly.

App Setup.

Once the App is installed on your Android device, tap on its icon to open it. You should see a screen similar to figure 2-2. Note the currently selected station message field at the bottom right of the screen. It will be yellow for some time and ultimately turn red with an error message. This is because the app needs to be set up the first time that it is used.

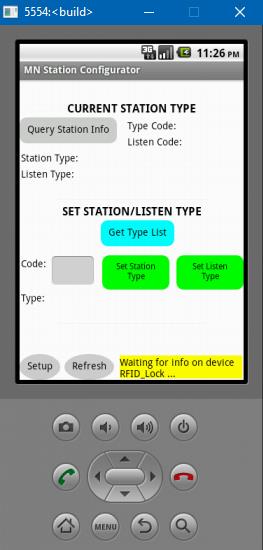
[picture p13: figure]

Figure 2-2. First Time Opening Screen.

You need not wait for the device message field to turn red.

Tap on the Setup button at the bottom left of the screen. This will take you to the SETUP screen of the app, as shown in figure 2-3.

Figure 2-3. Setup Screen.

Enter your Particle User ID and Particle User Password (PW) in the fields at the top of the Setup screen. The User ID and PW are for the Particle account where the Argon/Photon processors of your RFID Station(s)/Locks(s) are registered. If you do not know this information, then ask your System Administrator for it.

Once the Particle User ID and Particle User PW are entered, tap on the button “Request Device List” which is directly under the Particle User ID text field. If the information that you entered was correct, you will get a screen similar to figure 2-4.

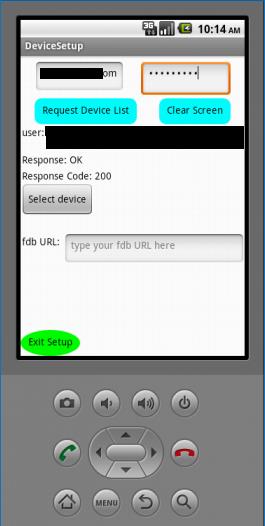
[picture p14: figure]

Figure 2-4. Requesting Device List from Particle Cloud.

Note the following in figure 2-4:
- A long, hexadecimal string of characters will appear to the right of “user:”. This is the Particle OAUTH2 user access token from the Particle cloud for the Particle account that you just logged into.
- “Response:” should show “OK”
- “Response Code:” should show “200”
- The button immediately below “Response Code” should change from “No devices” to “Select device”

If you don’t get this response information, then you probably typed in an incorrect User ID or PW. Triple check this; it is easy to make a mistake. Also, make sure that your Android device is connected to the Internet; otherwise, the Particle cloud is unreachable.

After getting the screen in figure 2-4, tap the button “Select device”. You will now get a pick list showing all Particle devices in your Particle account; see figure 2-5.

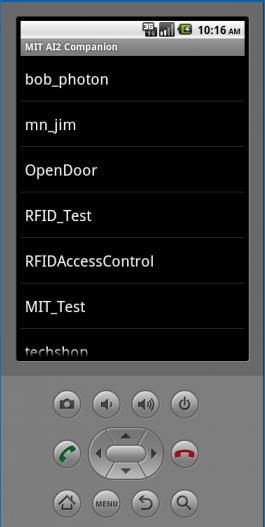
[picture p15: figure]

Figure 2-5. Device List Picker.

Tap on the device that you want to configure. The screen will return to the Setup screen, similar to figure 2-6.

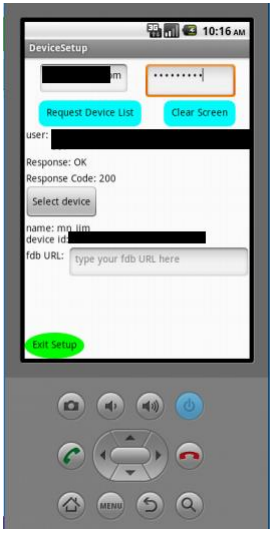
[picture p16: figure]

Figure 2-6. Device Selected.

Referring to figure 2-6, you should now see “name:” followed by the name of the device in the pick list that you selected and also “device id:” with a long hexadecimal string after it. The Particle device (Argon in an RFID Station, Photon in an RFID Lock board) has now been selected for access by the App.

Finally, you must type in the URL to access the devices table in your Facility Database. The URL must be fully constructed to return a JSON formatted list of device type names and associated device type codes. If your Facility Database is constructed as we have documented for Maker Nexus, then the URL will fire off a PHP script that queries the Facility database for this information and returns the proper JSON response. The format is similar to:

http://<theURLforYourFacilityDatabase>/fdbGetStationConfig.php?cmd=-1

Triple check that you have typed in this string correctly! Otherwise, you will get an error message when you return to the App screen.

Figure 2-7 depicts what the Setup screen should look like after typing in the URL. Now tap the button “Exit Setup” at the bottom left of this screen.

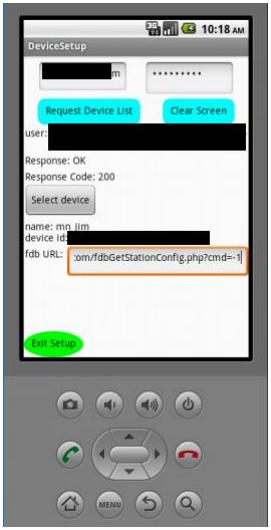
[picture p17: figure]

Figure 2-7. Entering Facility Database PHP Query URL.

The App should now return to the opening App screen as shown in figure 2-8, below.

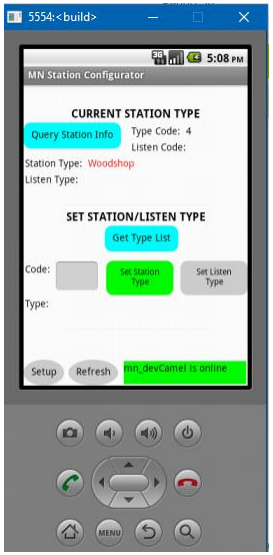
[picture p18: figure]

Figure 2-8. Exit Setup.

Note that now the device message at the bottom right of the screen should be green (after a brief time in yellow) and should show the name of the device that you selected and the fact that it is currently online.

NOTE: The information that you provided on the Setup screen is now stored in the App. Hereafter, when you open the App, you should get the screen shown in figure 2-8 with the previously selected device showing at the bottom right of the screen.

Station Configurator App User Instructions.

The Station Configurator App need only be setup once. After initial setup, the Particle User ID, Particle User PW, Particle User Access Token, Device ID of the last device selected, and the URL for the station type list should all be saved in the App’s data space on the Android device and the Setup screen need not be reentered unless any of this information needs to change. The most common change will be to select a different station device to configure.

Setting the Station Type for an RFID Station.

Here we assume that the device that was previously selected on the Setup screen is an RFID Station. We will want to set up the station type for this device. Instructions for an RFID Lock are in the next section of this document.

After the App is initially installed and set up, opening the App will show a screen similar to figure 3-1. The last Particle device (RFID Station) selected will be pinged and its on-line status displayed in the status area at the bottom right of this screen; see figure 3-1. The device status field should be green, indicating that the last selected device is on-line. If not, and if you want to configure this device, then check to make sure that the RFID Station of this device is powered up and connected to the Particle cloud via the Internet. If the RFID Station needs to be
powered and/or rebooted, you can again ping the device for status by tapping the “Refresh” button at the bottom middle of the screen, after the RFID Station boots up and connects to the Particle cloud (Argon “breathing cyan”).

If you need to select a different Particle device (i.e. a different RFID Station or RFID Lock to configure) than was previously selected, then tap “Setup” at the bottom of the screen to re-enter the Setup screen. Once in the Setup screen, you will see a display similar to figure 2-6. You do not need to re-enter the Particle User ID or Particle PW as long as the new device that you want to select is in the same Particle account. Likewise, you do not need to retype the “fdb URL” unless you need to change it. Just tap on “Select device” to get the device pick list, similar to figure 2-5, and then tap the device that you want to select. The setup screen will then look like figure 2-7, with the new device name and device ID displayed. If all is correct, tap “Exit Setup” to return to the main App screen, shown in figure 3-1.

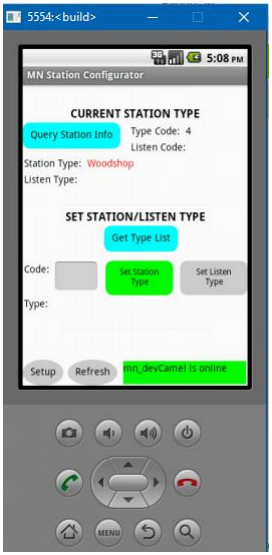
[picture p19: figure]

Figure 3-1. Opening Screen (after first time setup).

Once your App screen shows the correct device and that this device is on-line (see figure 3-1), then you can use this screen to perform the main functions of the App:

- Find out what type the selected RFID Station is currently configured as
- Obtain the station type list for your facility/organization and select a new station type for the selected RFID Station.

The currently set station type in the device is automatically queried for when the app is opened or when the Setup screen is exited. If you need to execute a fresh query for the station type information, tap the “Query Station Type” button at the top left of the App screen. After a brief pause, the RFID Station will beep once and the App will display the current station type (name and code), as shown in figure 3-2. Note that the app “knows” that this is an RFID Station and not an RFID Lock by the station type code (codes < 1000). Therefore, it does not query for the Lock Listen code and it leaves the Listen code and Listen type text blank.

Figure 3-2. Query Current Station Type.

If you want to change the station type of the selected RFID Station, you should first obtain a pick list of the station types that are defined for your facility/organization. You can do this by tapping the “Get Station Type List” button in the middle of the screen. After a brief pause, you will be presented with a pick list, similar to figure 3-3, below.

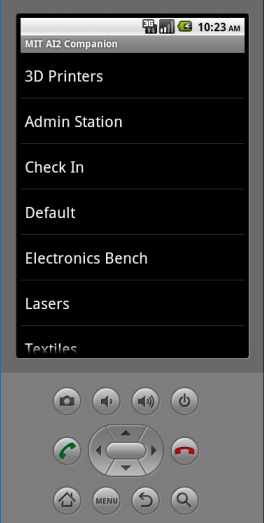
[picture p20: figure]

Figure 3-3. Station Type Pick List.

Tap on the station type that you want to configure the selected RFID Station to become. The pick list will disappear and the new station type name and type code will appear, as shown in figure 3-4.

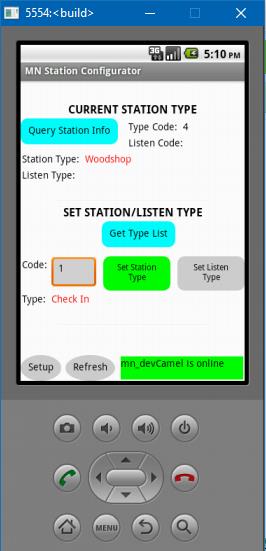
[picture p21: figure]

Figure 3-4. Setting New Station Type.

At this point, you have selected the new station type to command the RFID Station to become. After verifying that the new station type name and station type code are what you want, tap the “Set Station Type” button in the middle left of the screen. The “Set Station Type” button will gray out briefly and then return green. When it returns to green, the RFID Station should be rebooting into the newly selected station type. Note: it will take some time for the RFID Station to reboot. Wait until the RFID Station has fully rebooted before using it or before re-querying for its current type (figure 3-2). The “Set Station Type” button returning to green is NOT an indication that the Station is fully rebooted – only an indication that the Station received the command to change its type.

Setting the Station Type and Lock Listen code for an RFID Lock.

If the selected device is an RFID Lock, the opening app screen will look similar to figure 3-5.

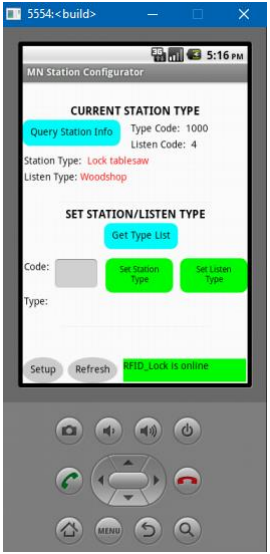
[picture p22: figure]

Figure 3-5. Opening Screen for RFID Lock.

Note that figure 3-5 looks very similar to figure 3-1 (RFID Station opening screen) except that the automatic query is for both the currently configured device type code and also for the current configured Lock Listen code. The app “knows” to query for the Lock Listen code because its current device type is >= 1000.

Changing the device type is exactly as described for changing an RFID Station device type; see the preceding section of this document. Note, however, that the “Set Listen Type” button is now green and enabled. When you tap “Query Type List” you will get the same pick list as shown in figure 3-3. If you wish to change the Lock Listen code, select an RFID Station type to listen for.

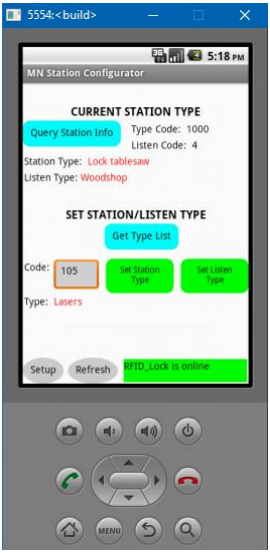
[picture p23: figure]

Figure 3-6. Selected Code for a New Lock Listen Type.

Referring to figure 3-6, we have selected “Lasers” from the pick list because we wish this RFID Lock device to listen to successful tap-in on any RFID Station that has been configured for “Lasers”. Now tap the “Set Listen Type” button to configure the RFID lock to listen for “Lasers” tap-in events.

Note that setting a new station type or a new Lock Listen code on an RFID Lock will cause the Photon processor to reset. This process will take a little while. Make sure to wait for the Photon device to come back up on-line before proceeding to use the Lock device or querying to verify that the new RFID Lock configuration is correct.

Once the RFID Lock device is reset and back on-line, you can tap the “Query Station Info” button at the top of the app to verify that the new configuration is correct. In this example, the result will be a shown in figure 3-7.

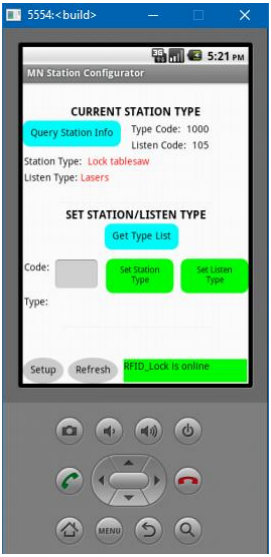
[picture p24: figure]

Figure 3-7. Verification of New Lock Listen Type.

CARD ADMINISTRATION APP.

The Card Administration App is used to manage RFID cards. The App works in conjunction with an RFID Station that has been configured as an Admin station type. The App communicates with the Admin station and acts as an extended user interface for the Station.

Figure 4-1 depicts an overview of the Card Administration App:

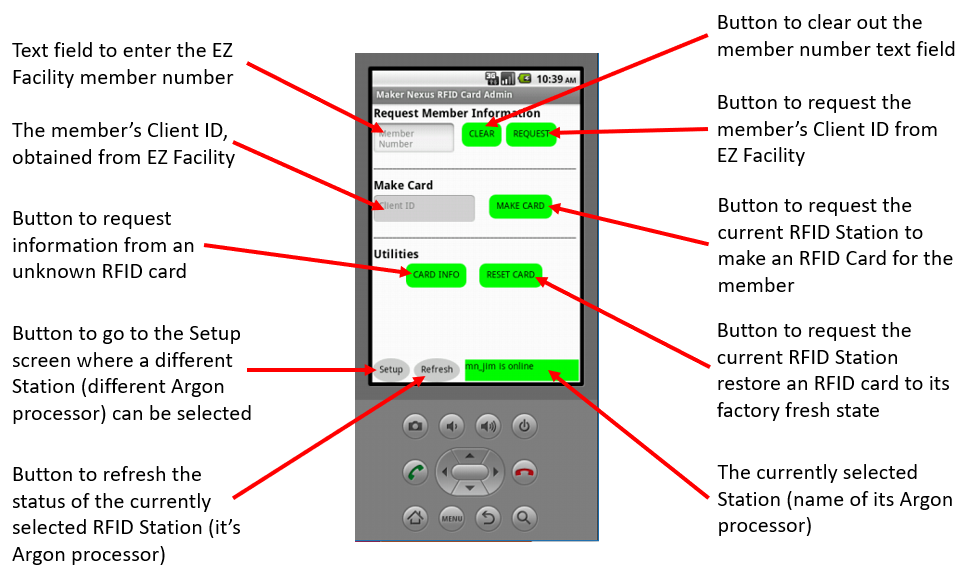
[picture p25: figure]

Figure 4-1. Overview of Card Administration App

The top section of this App is used to obtain member information from the CRM system (in our case EZ Facility) that is needed to make a membership card for a member. The App does not communicate directly with EZ Facility; rather it communicates with the Admin station and the Station then communicates with EZ Facility. The LCD display on the Admin station, as well as the LED indicators and buzzer on the Station, act as additional user interface elements of the RFID card management process.

The user of the Card Administration App must type the member’s membership number into the text box at the top left of the App screen. If a mistake is made, the “CLEAR” button at the top center of the screen may be used to clear out the current data from the member number text field. When the correct member number is entered in the text field, the “REQUEST” button may be tapped to request that the Admin station obtain member information from EZ Facility. The specific member information that is needed to make an RFID card is the EZ Facility “Client ID” and the “Custom Field 1” information for that member from EZ Facility. When this information is retrieved from EZ Facility, the “Client ID” field is populated with the Client ID from EZ Facility.

The middle section of this App is used to actually make a factory fresh RFID card into a membership card. The user of the App should check the Client ID to verify that it is correct and then use the “MAKE CARD” button to command the Admin station to make the card. The LCD display on the Admin station, along with the LED indicators and buzzer, further prompts the user to place a factory fresh RFID card on the RFID area on the Station and when the card may be removed.

The “Utilities” section of the App contains two additional buttons. The “CARD INFO” button is used to identify an unknown RFID card and the “RESET CARD” button is used to reset a formatted card back to the factory fresh condition for reuse at a later time (e.g. to recycle a card after member resigns).

The bottom section of this app contains two buttons and a display field. The “Setup” button is used to change over to the Setup screen of the App where a different RFID Station can be selected. The “Refresh” button is used to ping the selected RFID Station for its current status – e.g. if it is off-line and then is brought on-line, “Refresh” can be used to verify that the Station is indeed on-line. The display field at the bottom right of the screen displays the name of the RFID Station (name of its Argon processor) and its current status. The device is on-line and OK if the background of this field is green; it is not on-line or otherwise not OK if the background of this field is red; it is waiting for a ping response from the device if the background is yellow.

When the App is first installed on an Android device, it must be set up. Complete instructions for setting up the App are below.

Card Administration App Installation and Configuration.

Installation.

The installation file is called MN_Card_Administration.apk. It can be found in this repository:

Software/Android_Apps/AdminGUIApp/MN_Card_Administration.apk

In order to install this app on your Android device, you must transfer this installation file to your device. There are several ways to do this; here are three suggestions:

- Downloading: Download the file MN_Card_Administration.apk to your Android device using a web browser on the device. Make sure that you know the folder on the Android device where the browser stores downloaded files.
- Sideloading: Download the file MN_Card_Administration.apk to your desktop or laptop computer. Attach a USB cable from your desktop/laptop to your Android device. The Android device’s flash memory should appear as a drive on your computer. Drag and drop the installation file to a location on the Android device where you will be able to find it later.
- E-mail: Download the file MN_Card_Administration.apk to your desktop or laptop computer. Email this file to yourself as an attachment. Open email on your Android device and download the attachment, making sure that you know where the email program/browser stores attachments.

Regardless of the method that you use to get the file MN_Card_Administration.apk onto your Android device, you now use a file explorer on your device to locate the file and tap on it to start the installation. The App should now install on your Android device. NOTE: you may get a message on your Android device saying that the app is “untrusted” or “unverified”. This means that Android knows that the App did not come from the Google play store. Go ahead and install it anyway – it is safe! The installer will list the permissions that the App needs to run. Go ahead and accept them. The App should install properly.

App Setup.

Once the App is installed on your Android device, tap on its icon to open it. You should see a screen similar to figure 4-1, except that the currently selected station message field at the bottom right of the screen will be yellow for some time and ultimately turn red with an error message. This is because the app needs to be set up the first time that it is used. Tap the “Setup” button at the bottom left of the App screen to go to the App’s Setup screen. The Setup screen looks like the picture in figure 4-2, with no information in the text boxes at the top.

Figure 4-2. Admin App Setup Screen.

Enter your Particle User ID and Particle User Password (PW) in the fields at the top of the Setup screen. The User ID and PW are for the Particle account where the Argon processors of your RFID Station(s) are registered. If you do not know this information, then ask your System Administrator for it.

Once the Particle User ID and Particle User PW are entered, tap on the button “Request Device List” which is directly under the Particle User ID text field. If the information that you entered was correct, you will get a screen similar to figure 4-3.

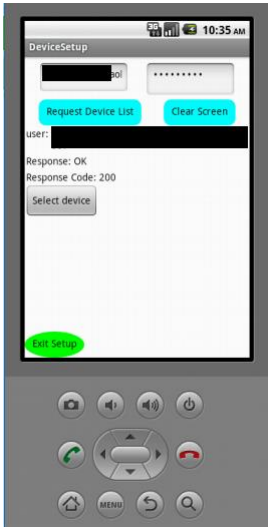
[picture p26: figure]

Figure 4-3. Request Device List.

Note the following in figure 4-3:
- A long, hexadecimal string of characters will appear to the right of “user:”. This is the Particle OAUTH2 user access token from the Particle cloud for the Particle account that you just logged into.
- “Response:” should show “OK”
- “Response Code:” should show “200”
- The button immediately below “Response Code” should change from “No devices” to “Select device”

If you don’t get this response information, then you probably typed in an incorrect User ID or PW. Triple check this; it is easy to make a mistake. Also, make sure that your Android device is connected to the Internet; otherwise, the Particle cloud is unreachable.

After getting the screen in figure 4-3, tap the button “Select device”. You will now get a pick list showing all Particle devices in your Particle account; see figure 4-4.

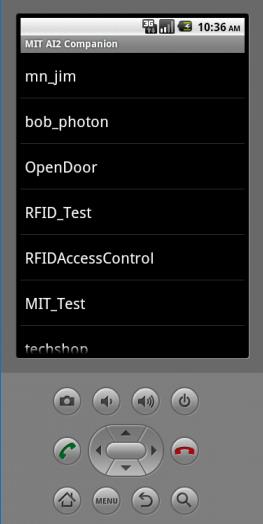
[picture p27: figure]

Figure 4-4. Device List Picker.

Tap on the device that you want to configure. The screen will return to the Setup screen, similar to figure 4-5.

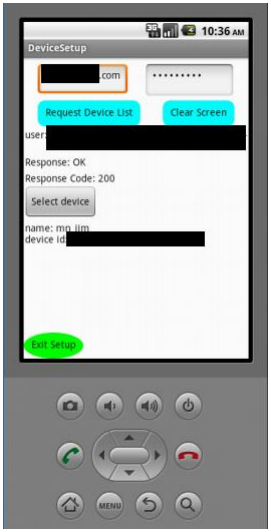
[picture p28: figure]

Figure 4-5. Device Selected – Exit Setup.

Referring to figure 4-5, you should now see “name:” followed by the name of the device in the pick list that you selected and also “device id:” with a long hexadecimal string after it. The Particle device (Argon in an RFID Station) has now been selected for access by the App. Now tap the button “Exit Setup” at the bottom left of this screen. The App should now return to the opening App screen as shown in figure 5-1, below.

Note that now the device message at the bottom right of the screen should be green (after a brief time in yellow) and should show the name of the device that you selected and the fact that it is currently online.

NOTE: The information that you provided on the Setup screen is now stored in the App. Hereafter, when you open the App, you should get the screen shown in figure 5-1 with the previously selected device showing at the bottom right of the screen.

Card Administration App User Instructions.

The Card Administration App need only be setup once. After initial setup, the Particle User ID, Particle User PW, Particle User Access Token, and Device ID of the last device selected will all be saved in the App’s data space on the Android device and the Setup screen need not be reentered unless any of this information needs to change.

After the App is initially installed and set up, opening the App will show a screen similar to figure 5-1. The last Particle device (RFID Station) selected will be pinged and its on-line status displayed in the status area at the bottom right of this screen; see figure 5-1. The device status field should be green, indicating that the last selected device is on-line. If not, and if you want to use this RFID Admin Station, then check to make sure that this device is powered up and connected to the Particle cloud via the Internet. If the RFID Admin Station needs to be powered and/or rebooted, you can again ping the device for status by tapping the “Refresh” button at the bottom middle of the screen, after the RFID Station boots up and connects to the Particle cloud (Argon “breathing cyan”).

If you need to select a different Particle device (i.e. a different RFID Admin Station) than was previously selected, then tap “Setup” at the bottom of the screen to re-enter the Setup screen. Once in the Setup screen, you will see a display similar to figure 4-3. You do not need to re-enter the Particle User ID or Particle PW as long as the new device that you want to select is in the same Particle account. Just tap on “Select device” to get the device pick list, similar to figure 4-4, and then tap the device that you want to select. The setup screen will then look like figure 4-5, with the new device name and device ID displayed. If all is correct, tap “Exit Setup” to return to the main App screen, shown in figure 5-1.

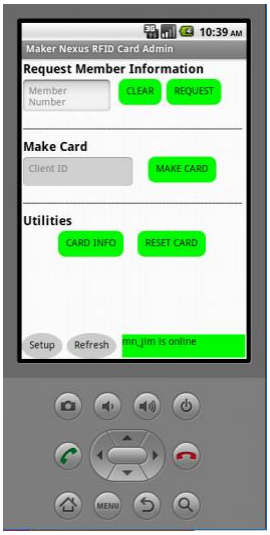
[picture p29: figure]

Figure 5-1. Admin App Opening Screen (after first time setup).

In order to make an RFID card for a member, the member’s membership number must be known. If necessary, the Administrative user should look up this number in EZ Facility. The App user should then enter the membership number in the “Member Number” text field at the top left of the screen and then tap the “REQUEST” button. The button will turn gray for a short time while the RFID Station is requesting member information from EZ Facility. When the information is retrieved from EZ Facility and returned to the App from the Admin station, the member information will appear in a popup window, similar to figure 5-2. This information can be used by the Administrator to make sure that the correct member has been selected and that the member is in good standing (membership active and paid up). See figure 5-2 for such a result.

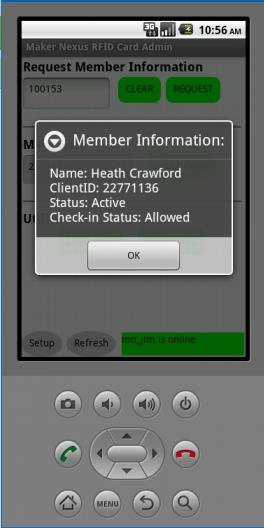
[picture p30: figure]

Figure 5-2. Request member Information.

The pop-up message can be dismissed by tapping “OK”.

After tapping “OK”, the message will disappear and the “Client ID” text field will be filled in with the EZ Facility Client ID for the member. If the name presented in the pop up was correct, the App user can then tap on the “MAKE CARD” button and follow the directions on the Admin station to make the RFID membership card.

Referring back to figure 5-1, tapping the “CARD INFO” button will cause the Admin station to display prompts for presenting an unknown RFID card to the Admin station. After the card is presented and read, the App will show the results; e.g. figure 5-3.

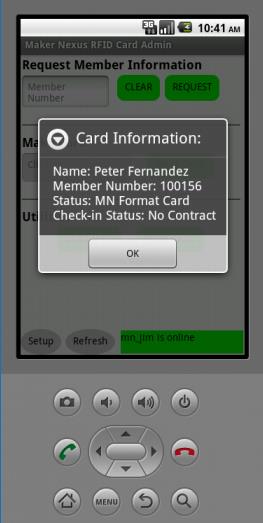
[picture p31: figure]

Figure 5-3. Request Card Information.

The card information message in figure 5-3 can be dismissed by tapping “OK” on the message.

Referring back to figure 5-1, tapping the “RESET CARD” button will cause the Admin station to display prompts for presenting a formatted membership RFID card to the Station, after which the card will be reset to the factory fresh state. All prompts for this operation are on the Admin station itself, not on the App

Making an RFID Card for a Member.

The process of making an RFID membership card for a member involves accessing EZ Facility first and then using the App and the Admin station as described above. Before an RFID card can be made for a member, the member’s information must be in EZ Facility and a facility/organization specific membership number assigned to the member. EZ Facility will ensure that the membership member is unique, but otherwise it is entirely up to the facility/organization’s rules as to how these numbers are created. The Card Administration App uses this number to lookup the Client ID for that member. Client ID is an index into the member’s EZ Facility data that is generated by EZ Facility itself.

Two items of data are retrieved from EZ Facility and written (encrypted) to the RFID card: (1) the Client ID assigned by EZ Facility, and (2) the contents of “Custom Field 1” of the member’s record in EZ Facility. Initially, Custom Field 1 is blank, and it may be left so for the first issuance of an RFID card to a member. However, if the member needs a replacement RFID card, the administrator should enter some arbitrary, random number into Custom Field 1 in EZ Facility prior to making the new RFID card. The RFID Access Control System uses this number to make sure that the card presented to any RFID Station is the latest card and not an older one; i.e. it provides for automatic card revocation.

The following is excerpted from Maker Nexus’ Administration Instructions. The specifics may vary for your facility or organization:

### Get Ready

Assemble all the tools and supplies you will need.

Android Tablet, Maker Nexus ADMIN box, blank RFID card(s)

### Android Tablet

Marked on back | Kept in drawer at front desk | Should be charged up

### Maker Nexus ADMIN Box

Marked on the side.

This is kept in the drawer at the front desk

### Blank RFID Cards

These are NOT the same cards as the ones we print id badges on. They look identical but they are not. Our system uses “13.56MHz MIFARE Classic 1K RFID Smart Cards ISO14443A Sublimation Printable”.

A box with blank cards in it.

When I buy a new pack of cards, I mark the edge so, hopefully, people will know they are different.

### Get the Member Number

Member Number of each person you want to make a card for. This is found on the Personal info tab of the client in EZFacility.

### The Process

1. OPTIONAL: If you are replacing a card and want to invalidate the old card, then you must update a field in EZ Facility. On the client’s “personal” information tab, about half way down on the left is the “RFID Card UID” field (Custom Field 1, renamed). It is usually blank. To invalidate an old RFID card, change this field in some way. It does not matter what you put in the field, so just put in three or four random characters.

2. Make sure the Maker Nexus ADMIN box is running. The display should look like this:
3. Turn on the Android tablet. Scroll to the bottom and tap on the MN app icon.

This will bring up the MN Administration App, which looks like this:

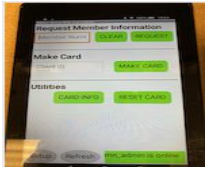
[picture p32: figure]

4. Make sure the app is set up. If the lower right corner is not green, then something is wrong. Try tapping the REFRESH button once. If that doesn’t fix it, make sure that the RFID Admin Station is plugged in and connected to the Particle cloud (the Argon processor is “breathing cyan”). A green indicator that the system “is online” is good.
5. Enter the member number. In this case we entered 100153. Tap the REQUEST button.
6. Watch the LCD screen on the MN ADMIN box. It will eventually show the name associated with the member number you entered.

7. After a few seconds, the Android app will display information about the member.
a. Verify that the member name is the person you want to make a card for.
b. The ClientID is different than the Member Number, don’t worry about this.
c. Status shows if they have an active membership.
d. Check-in Status shows what will happen if they try to check-in.
i. Allowed means they will get a green light
ii. Any other message should give you an indication of why the system would not allow them to check-in. Perhaps their membership has expired. Perhaps the credit card on their account did not process correctly.
e. No matter the status, you can still create an RFID card for this person.
f. Tap OK to dismiss this information box.
8. Tap MAKE CARD. A message shows up telling you to look at the MN ADMIN box. Note that you must do this within 15 seconds of when you tapped the REQUEST button. If time expired the system will reset and you will have to tap REQUEST again.

9. The MN ADMIN box should now be ready to create the card.

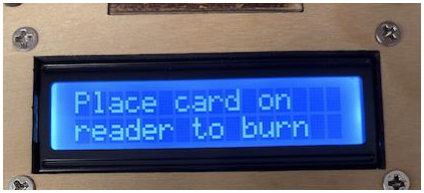
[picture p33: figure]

Place a blank card on the square:

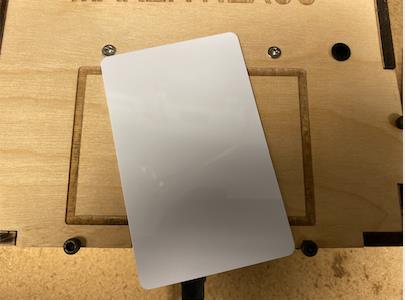
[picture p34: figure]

This message will appear immediately followed by two beeps. That’s it, the card has been created.

10. Wrap up
a. Either give the card to the member.
b. Or put a piece of tape on it with their name and file the card in the office. Then use EZ Facility to send the member a note that their card is ready (there is a template message in EZ Facility for this.)
11. Clean up
a. Unplug the MN ADMIN box and put it on the shelf.
b. Return the Android tablet to the drawer and plug it in.
c. Return unused RFID cards to the office.

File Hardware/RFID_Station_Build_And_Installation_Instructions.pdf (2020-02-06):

# RFID Station Build and Installation Instructions

By: Jim Schrempp, Bob Glicksman and Mike Calyer; v1, 2/06/2020

© 2020 Team Practical Projects, Maker Nexus, Bob Glicksman, Jim Schrempp and Mike Calyer. All rights reserved.

NOTICE: Use of this document is subject to the terms of use described in the document “Terms_of_Use_License_and_Disclaimer” that is included in this release package. This document can be found at:

https://github.com/TeamPracticalProjects/MN_ACL/blob/master/Terms_of_Use_License_and_Disclaimer.pdf

© 2019/2020, Team Practical Projects, Maker Nexus, Jim Schrempp, Bob Glicksman and Mike Calyer; all rights reserved. Subject to “Terms of Use, License and Disclosure”

TABLE OF CONTENTS.

TABLE OF CONTENTS. | 1
OVERVIEW. | 2
PCB ASSEMBLY INSTRUCTIONS. | 4
ENCLOSURE FABRICATION INSTRUCTIONS. | 21
STATION ASSEMBLY INSTRUCTIONS. | 25
FIRMWARE INSTALLATION AND TESTING INSTRUCTIONS. | 37
troubleshooting. | 38
The Station Appears Dead. | 38
Checking out the Buzzer, Pushbutton LEDs and READY LED. | 39
Checking out the LCD Display. | 39
Checking out the PN532 RFID Module. | 40

OVERVIEW.

This document provides step-by-step instructions for assembling an RFID Station. Before proceeding with this project, you must read and accept the “Terms_of_Use_License_and_Disclaimer” document which is located in the root level of this repository. It is strongly suggested that you read and understand the document “RFID_ACS_Overview_Document” which is located in the Documents folder of this repository before deciding whether or not to proceed with this project!

In order to build an RFID Station, you must procure the parts listed in the “RFID_Station_Parts_List” that is located in the Hardware folder of this repository. In addition, you must have the necessary skills and tools, as follows:

- PCB assembly: This project requires that you assemble a custom designed printed circuit board (PCB). Board assembly requires through-hole electronic soldering tools and skills. PCB assembly does not require surface mounting of parts. Eagle CAD files are provided so that you can order blank PCBs from a manufacturer of your choice. Links to two manufacturers that we have tested are included in the parts list.
- Enclosure manufacture: The enclosure is made from laser cut ¼” thick birch. Vector CAD (.svg) files are included in the Hardware folder of this repository. We at Maker Nexus have access to in-house laser cutters, but you should be able to order laser cut parts from a reputable on-line vendor. The enclosure itself is glued together. All electronic parts are assembled on the underside of the enclosure front cover and either screwed or hot glued in place.
- Firmware installation: The Station is not complete until the Particle Argon microcontroller is captured into your Particle cloud account and the firmware is flashed onto it. You will be required to understand how to use the Particle Workbench Visual Studio IDE in order to edit files containing your secret encryption keys, build, compile and flash firmware code to your Argon device, create webhooks in your Particle cloud account using the Particle Console. Our documentation will guide you through this process, but you need to know how to use Particle’s tools before you can follow these instructions. Refer to: www.particle.io for further details.

NOTE: Do not proceed to order parts and to attempt this project until you are confident that you have the necessary skills, tools and knowledge to do so. We are not responsible for the outcomes of your attempts to build and install this project. You may contact us if you get stuck or have a problem, but we make no guarantees that we can help you or even that we can respond to your inquiries.

This document is divided into major sections:

- PCB Assembly Instructions: this section provides you with detailed instructions for assembling the custom PCB needed for this project. This is normally the first step that you will take, as the assembled PCB is a major component of the overall Station assembly.
- Enclosure Fabrication Instructions: this section describes how to assemble the enclosure from the laser cut parts. The back, sides, top and bottom are fit and glued together to form the enclosure. The front panel must first have the electronics installed on it and is then fit to the enclosure and fastened down with screws and nuts.
- Station Assembly Instructions: this section includes instructions for assembling and wiring the electronics onto the Station front panel. When this is complete, the front panel is attached to the rest of the enclosure and fastened down with screws.
- Firmware Installation and Testing Instructions: summary instructions for capturing the Argon into your Particle account and for compiling and flashing the firmware onto the Argon are contained in this section. Reference is made to detailed system and software installation instructions that are contained in a separate document.
- Troubleshooting: instructions about how and what to check in the event that the RFID Station that you built does not come up fully operational. This is not a step-by-step debugging set of instructions, but it may help you if the Station exhibits some common problems. You will need a multi-meter and possibly a magnifying glass, as well as familiarity with the Particle web environment in order to troubleshoot your RFID Station.

We suggest that you follow these instructions in this order. However, you may wish to assemble the PCB and then assemble and wire up the remaining electronics on the bench in order to flash the firmware and test out the electronics before manufacturing the enclosure and mounting the electronics therein.

PCB ASSEMBLY INSTRUCTIONS.

The completed printed circuit board (PCB) is shown in figure 1-1, below. The major parts are called out in this figure.

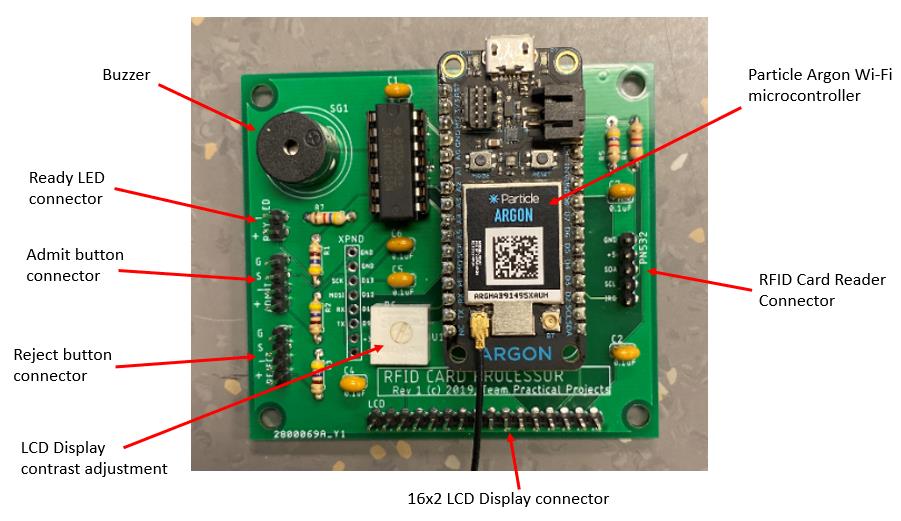
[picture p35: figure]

Figure 1-1. Completely Assembled PCB.

Assembly of the PCB begins with the blank PCB and the parts to be used in board assembly. In order to assemble the PCB, you will need the following tools and materials:

- Fine tipped electronics soldering iron
- Electrical solder
- Needle nose pliers
- Diagonal wire cutters
- Electrical tape

You should also have a multi-meter available and know how to use it.

You can solder the parts onto the PCB in any order that you wish. However, we recommend that you follow the order in our instructions.

Begin with the bare PCB, shown in figure 1-2.

Figure 1-2. Bare PCB.

Figure 1-2 shows the top side of the PCB. This is where you will insert the parts. After inserting parts, flip the board over and solder the leads to the bottom of the PCB, being careful to keep the parts firmly seated onto the board.

Before proceeding further, we recommend that you make sure that there are no shorts on the bare PCB – particularly that neither the 3.3 volt nor the 5 volt power rails are shorted to ground. The connector field labeled XPND has to pins marked GND and pins marked +3.3v and +5v. Use your multi-meter to check that neither the +3.3v nor the +5v pins are shorted to GND and that +3.3v and +5v are not shorted to each other. If there is a short, you have a bad PCB; you could try to discover what is wrong, but most likely you have a bad manufacturing situation and the board should be thrown away.

Mount and solder six 0.1uF capacitors (C1, C2, C4, C5, C6, C7), as shown in figure 1-3.

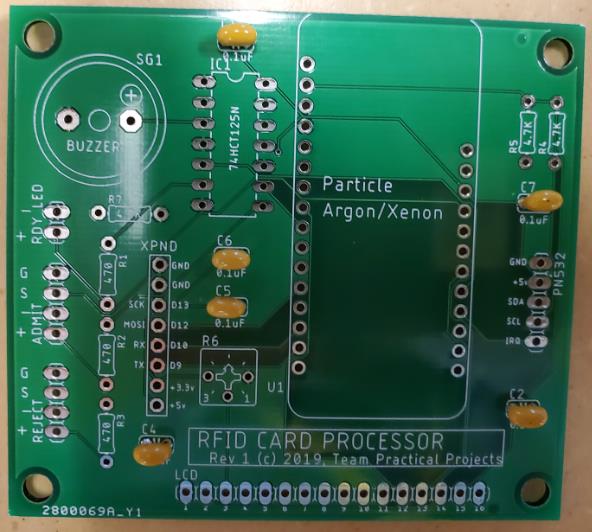
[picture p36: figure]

Figure 1-3. Mount decoupling capacitors.

Next, mount and solder three 4.7K resistors, as shown in figure 1-4 (R4, R5, and R7). Be careful to check the color code on the resistors and/or to check the resistance with a multi-meter prior to soldering in the resistors. Do not confuse these with the three 470 ohm resistors that are assembled onto the PCB in the next step.

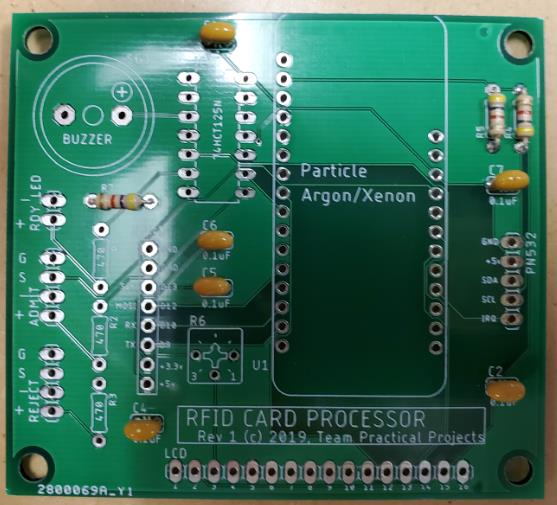
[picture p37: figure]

Figure 1-4. Mount 4.7K resistors.

Next, mount and solder three 470 ohm resistors, as shown in figure 1-5 (R1, R2, and R3). Be careful to check the color code on the resistors and/or to check the resistance with a multi-meter prior to soldering in the resistors. Do not confuse these with the three 4.7 K ohm resistors that were assembled to the PCB in the prior step.

Figure 1-5. Mount 470 ohm current limiting resistors.

The next step is to mount the 14 pin DIP socket in the IC1 position, as shown in figure 1-6. Position the socket so that the notch in the plastic body is facing up, i.e. as shown in the silkscreen on the PCB.

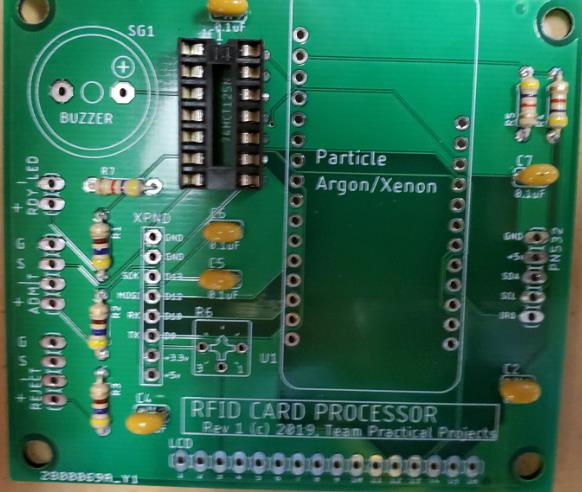
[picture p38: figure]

Figure 1-6. 14 pin DIP socket for IC1.

Unlike the components that were previously soldered to the PCB, the leads on the DIP socket are small and cannot be bent over on the underside of the board to hold the socket in place while soldering. We suggest that you affix the socket to the PCB using electrical tape to hold it in place while soldering, as shown in figure 1-7.

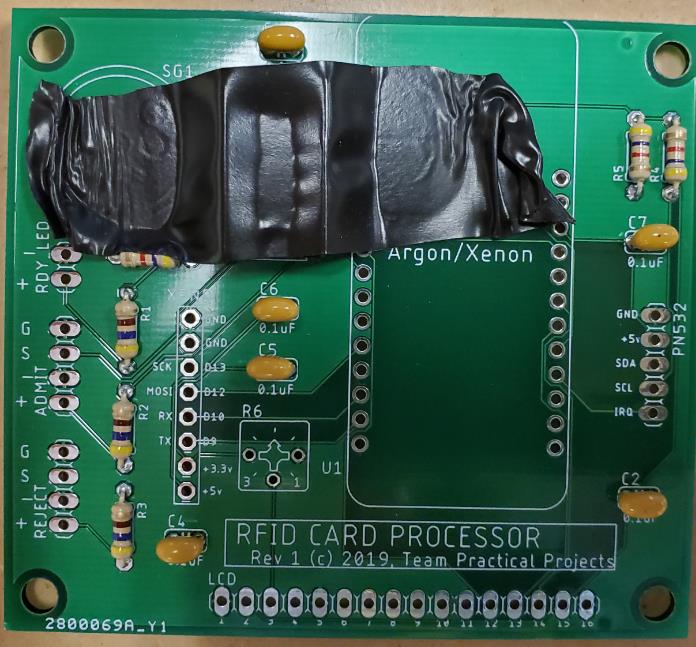
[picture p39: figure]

Figure 1-7. Holding the DIP socket in place for soldering.

Carefully examine the soldering on the bottom of the board to make sure that there are no solder bridges, either between pins or between a pin and vias on the board. See figure 1-8 for a closeup. Note the small through board via near pin 4 that must not be soldered.

Figure 1-8. View of IC1 solder side.

Next, place the 10K potentiometer (R6) into the holes on the PCB, as shown in figure 1-9.

Figure 1-9. Mounting 10K potentiometer

The potentiometer can only mount on the PCB in one way. As with the IC socket, it is suggested that you use some electrical tape to hold the potentiometer fast to the front of the PCB while soldering the leads on the back of the PCB – see figure 1-10.

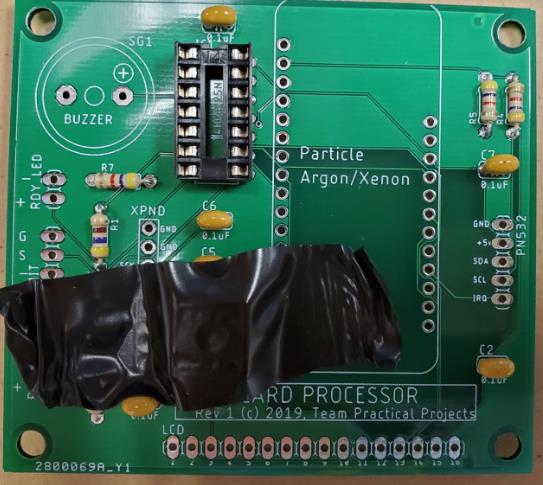
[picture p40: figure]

Figure 1-10. Holding the potentiometer in place for soldering.

The next item to solder to the PCB is the piezo buzzer. Note in figure 1-10 that there is a plus (+) sign by one of the buzzer terminals on the PCB. The buzzer must be placed so that the plus (+) lead of the buzzer is aligned with the plus (+) sign on the PCB.

Figure 1-11 shows the buzzer inserted into the PCB with the plus (+) label indicating where the plus (+) lead of the buzzer is. However, the label can move in shipping and is not always reliable. Remove the label and observe the plus (+) mark on the buzzer itself to be sure that you have placed the buzzer on the PCB properly.

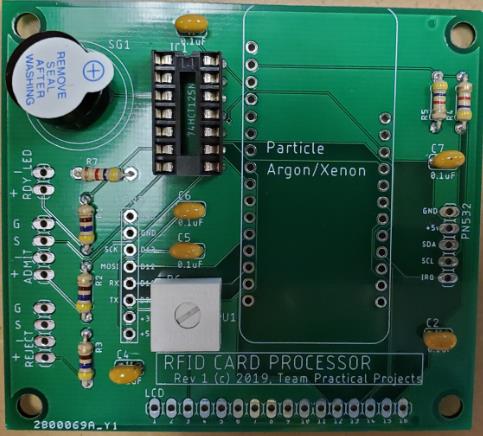
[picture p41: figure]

Figure 1-11. Placement of Buzzer

After removing the label and double checking the buzzer placement on the PCB, use some electrical tape to hold the buzzer fast to the PCB, as shown in figure 1-12.

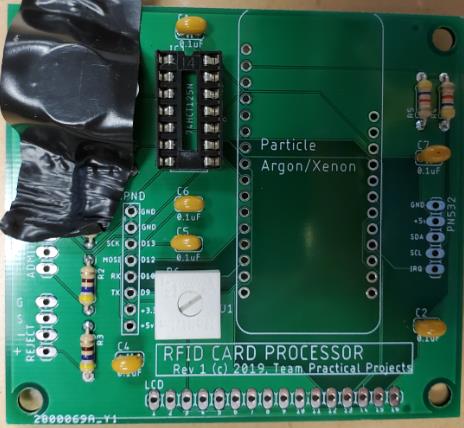
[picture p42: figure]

Figure 1-12. Holding the Buzzer in Place.

How, flip the board over and solder the buzzer leads to the PCB.

Now that you have soldered the electronic components onto the PCB, it is time to mount the connectors. Take one of the male pin header strips and break off a 5 pin section. We suggest that you use the smaller of the Argon female header connectors to help mount the 5 pin male header as shown in figure 1-13.

Figure 1-13. Using the Argon Female Connector to Help Mount the 5 pin Male Header.

Now, insert the solder pins of the 5 pin male header into the PCB in the area marked “PN532”. Use electrical tape to hold this assembly in place for soldering, as shown in figure 1-14. Take care to make sure that the tape holds the connector completely upright and not tilted to the PCB (i.e. at right angles to the PCB). See figure 1-14 for details.

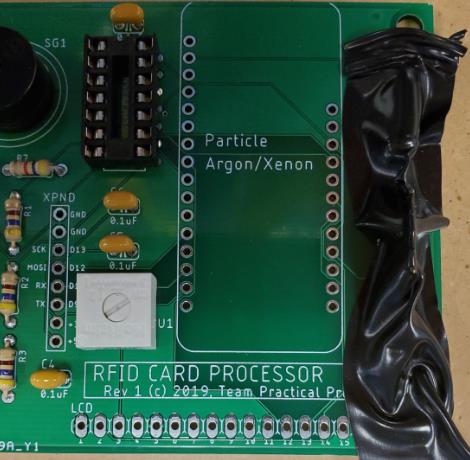
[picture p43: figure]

Figure 1-14. Mounting the 5 Pin Header.

Solder the header to the PCB and remove the electrical tape. Unplug the Argon female connector from the pin header and check your work. See figure 1-15 for what the result should look like.

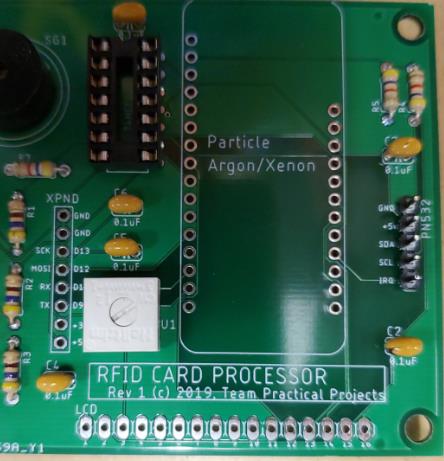
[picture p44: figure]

Figure 1-15. 5 Pin Header Assembled onto the PCB.

Next, mount the button/LED pin header connectors on the opposite end of the PCB. The procedure is similar to the 5 pin header, above. Break off two 4 pin header sections and one 2 pin header section from a male pin header strip. Insert these into the smaller Argon female connector so that the male pin headers align with the holes on the PCB, as shown in figure 1-16.

Figure 1-16. LED Connectors Ready for Assembly.

Insert the male pin header solder pins into the PCB and hold the assembly in place and upright (perpendicular to the PCB) using electrical tape, as you did for the 5 pin header. Take care that the assembly is firmly inserted into the PCB and upright. Then solder the pin headers to the PCB. The PCB should look similar to figure 1-17.

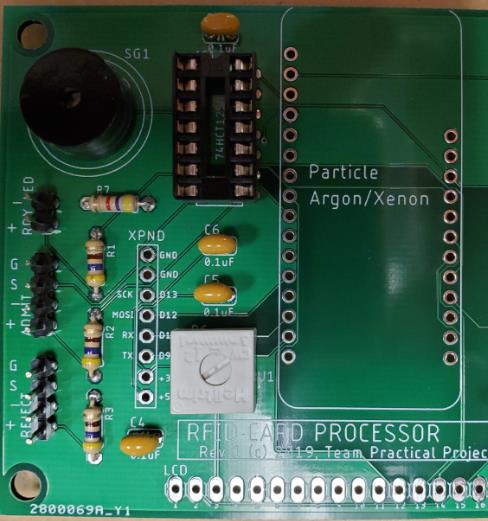
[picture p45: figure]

Figure 1-17. Button/LED Header Assembled to PCB.

Break off a 16 pin male pin header strip and insert it into the LCD connector on the PCB. Use electrical tape to hold the strip in place and vertical, as in the previous steps. Solder the 16 pin header strip to the PCB. We suggest that you solder the two ends and the pin in the middle first, to hold the whole connector body in place. Then solder the remaining pins to the PCB. Figure 1-18 shows the PCB as it should look after this step.

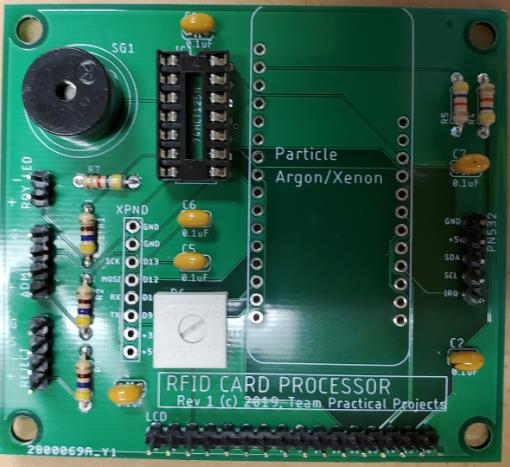
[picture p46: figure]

Figure 1-18. LCD Connector added to the PCB.

The next step is to mount the two female connector strips for the Argon to the PCB. The best way to assure that the connectors are soldered to the PCB in alignment (so that the Argon male pins will fit correctly into the two female connectors after soldering to the PCB) is to insert the connectors onto the Argon first, as shown in figure 1-19.

Figure 1-19. Mounting the Argon female headers to the Argon for soldering.

Next, the entire assembly is inserted onto the PCB and held on place with electrical tape. BEWARE: cover the 2D barcode on the Argon with something non-sticky before placing sticky electrical tape over it! You do NOT want the barcode label to peel off of the Argon when you later remove the electrical tape! See figure 1-20 for this step.

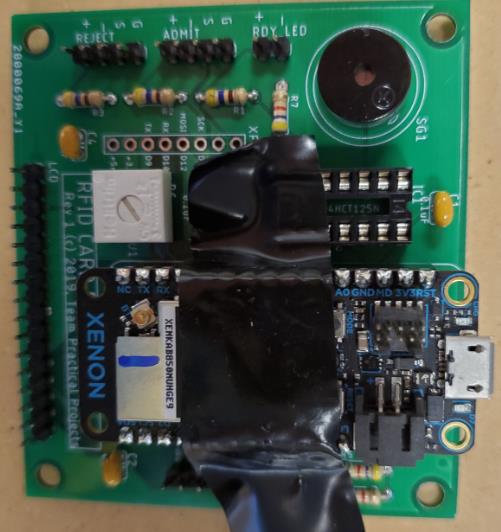
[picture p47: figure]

Figure 1-20. Holding the Argon/header connectors to the PCB for soldering.

Make sure that the Argon/connectors are flush to the PCB and fully inserted. Now, carefully flip the PCB over and solder the two end pins and one center pin on each of the two header connectors to the PCB, as shown in figure 1-21. Do not solder more pins than this in order to avoid heat damage to the Argon. Three pins are enough to hold the connectors firmly in place for subsequent soldering with the Argon removed.

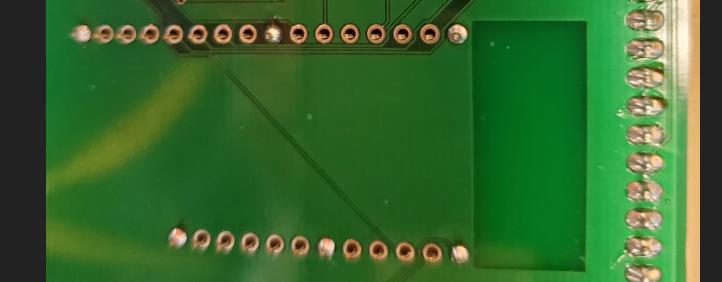
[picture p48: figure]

Figure 1-21. Soldering 3 pins of each connector to the PCB with the Argon still inserted.

Now, remove the Argon so that it will not be subjected to further heat stress and then solder the remaining Argon header pins to the PCB.

Carefully inspect all solder joints on the PCB to be sure that all connections have been made and that no cold solder joints remain. Clean excess solder and flux off of the underside to the PCB and inspect the top (component) side of the PCB to ensure that everything is properly mounted. The completed PCB should look like the photo in figure 1-22, below.

Figure 1-22. Completely soldered PCB – top view.

To finish the PCB assembly, Insert the Argon into the connectors provided on the PCB. The micro USB on the Argon should be at the top of the board as oriented in figure 1-22. Insert the 74AHCT125 level shifter IC into the 14 pin socket (IC1). The chip has a notch and/or a white dot at the top of the chip. The chip must be oriented with this notch/dot toward the top of the PCB and aligned with the notch on the IC connector.

At this point, you can power up the PCB using the micro USB connector on the Argon module. The board should power up and 5 volts and 3.3 volts should be available in the XPND connector that is just to the left of the 10 K ohm trim pot. If you want to claim the Argon to your Particle account at this time, you will first need to plug the WiFi antenna into the u.FL connector on the Argon. Skip ahead to figures 3-8 and 3-9 in the section “STATION ASSEMBLY INSTRUCTIONS”, below.

ENCLOSURE FABRICATION INSTRUCTIONS.

This section describes building the enclosure. The enclosure is laser cut from ¼” birch stock, or similar material. The laser cut parts of the enclosure are called out in figure 2-1, below.

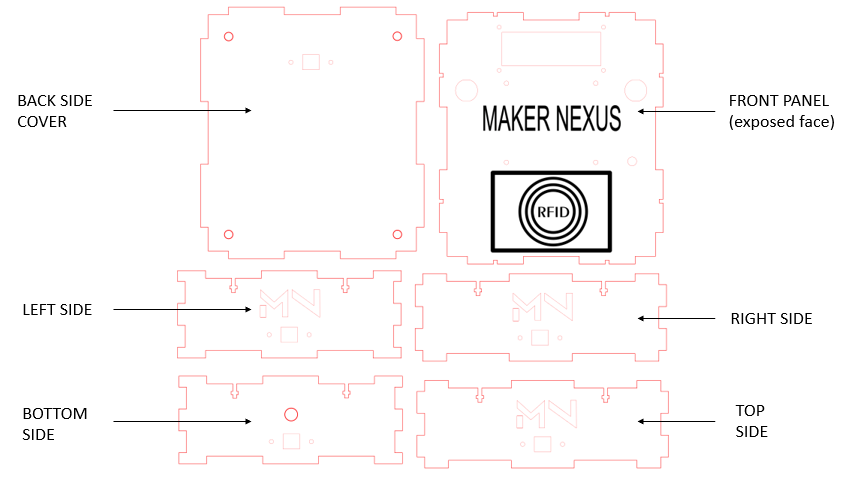
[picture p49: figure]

Figure 2-1. Laser cut parts of the enclosure.

Place the back side bottom cover on a flat surface with the outside face facing down. Next, fit the left side panel to the left side of the box bottom and the bottom side panel to the bottom side of the box bottom. The sides should fit snugly to the bottom panel and should stay in place temporarily without gluing. Fit the right side and top side to the box bottom in the same way. The enclosure parts should all fit snugly. Check that the outside surfaces are positioned on the outside of the enclosure. Check that the front panel fits correctly onto the assembled box with the engraving facing up. Now remove the front panel. Glue the box pieces together with wood glue or other fastener that is compatible with the enclosure material. Wait for the glue to dry. Double check that the enclosure front panel fits correctly onto the assembled enclosure and that the front cover mounting screws fit in the indentations on the front panel and the enclosure side.

The front panel is NOT glued onto the enclosure – it is held to the enclosure by machine screws and nuts. The assembled enclosure should look like the figures below.

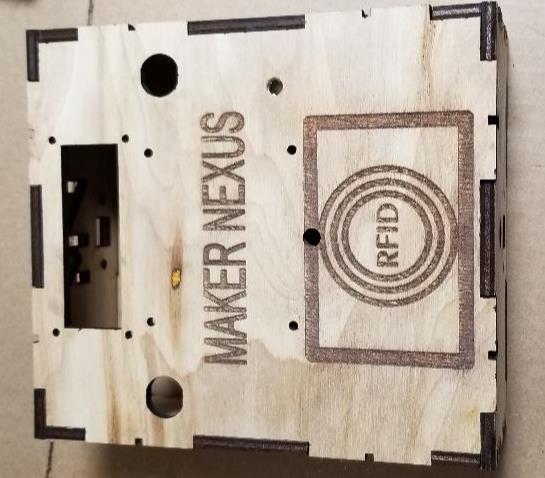
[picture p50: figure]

Figure 2-2. Assembled enclosure – top view.

Figure 2-3. Assembled enclosure – top side view.


Figure 2-4. Assembled enclosure – bottom side view.

STATION ASSEMBLY INSTRUCTIONS.

This section contains instructions for mounting the RFID Station electronic components onto the enclosure. Prior to this step, you should have completed assembly of the RFID Card Processor printed circuit board (PCB) and have the laser cut enclosure top (front) panel available. All of the electronics (except for the box power cable) mount on the underside of the enclosure top panel.

The tools that you will need for the steps described in this section are:
- Fine tipped electronics soldering iron
- Electrical solder
- Needle nose pliers
- Diagonal wire cutters
- Calibrated wire stripper
- Phillips head screwdriver
- (optional) swage connector crimping tool
- Electrical tape
- Hot glue gun
- Multi-meter

The LCD display module and the custom PCB mount onto the underside of the top (front) panel using M3-05 x 16 mm machine screws. The panel is laser cut to accommodate tapered phillips head screws that fit flush into the top (outside face) of the panel. If necessary, use a 7/32” drill bit to manually ream out the mounting holes on the top side of this panel until the phillips head screws fit flush to the panel face. The screws are held in place by M3 nylon washers which also serve as standoffs. See figure 3-1, below.


Figure 3-1. Mounting for the LCD display and PCB using machine screws.

Eight screws are used to mount these components – 4 for the LCD display module and 4 for the PCB. A second set of nylon washers is used to hold these modules in place after they are inserted onto the enclosure panel. The finished assembly picture in figure 3-10 illustrates this. At this point, however, you should simply prepare the panel as in figure 3-1.

The next step is to solder pigtail connector wires onto the red and the green backlit pushbutton switches. The connections to these switches are shown in figure 3-2.


Figure 3-2. Pushbutton switch terminals.

Four 9-inch long female-female wires are used to connect these terminals to the corresponding male connectors on the PCB. There are several ways to prepare these wires for soldering to the pushbutton switch swage terminals:

- Cut off the female pin header connector at one end of each wire; carefully strip back ¼” of insulation from the cutoff end of the cable; tin the bare wire and solder to one of the swage lugs on the pushbutton switch. This method is illustrated in figure 3-3, below.
- Cut off the female pin header connector at one end of each wire; carefully strip back ¼” of insulation from the cutoff end of the cable; crimp a matching swage connector onto the bare wire. The swage connector must fit snugly onto the pushbutton switch terminal.
- Bend and solder a stiff, male header pin to each pushbutton switch terminal, making sure that the mechanical connection is solid. Female-female jumper wires can then be connected to the male terminals at both the pushbutton switch and the PCB ends.

Regardless of the method that you use, you should use a different color wire for each terminal on the pushbutton switch and you should CAREFULLY note which color goes with which terminal, as annotated in figure 3-2.

After affixing 4 connector wires to each of the red and green pushbutton switches, take two more female-female connector wires and solder them to the 5 mm green LED, using any method that suits you. Once more, make CAREFUL note of the color of the wires – the longer lead on the LED is the “+” wire and the shorter lead on the LED is the “-“ wire. The finished product should look like figure 3-3, below.

Figure 3-3. Cable assemblies for the buttons and ready LED.

Break off a 16 pin male header and solder it to the LCD module with the male connector pins on the bottom (non-display) side of the LCD module; see figure 3-4. Now mount the LCD panel on the mounting screws and fasten tight using 4 nylon nuts; see figure 3-4.

Mount the red and green pushbutton switches onto the enclosure front panel as shown on figure 3-4. The pushbutton switches come with their own threaded hold-down fasteners. The red pushbutton is on the left side as viewed in figure 3-4; the green pushbutton is on the right side.

The 5 mm green LED can be panel mounted using the parts in the parts list. However, the enclosure panel is too thick for these panel mounts to fit well. Take a 7/16” drill bit and use it to manually ream out some of the panel thickness until the LED panel mounting clips snap the LED firmly into place. See figure 3-4 for what the results of this step should look like.


Figure 3-4. Mounting the LCD, buttons and admit LED.

Strip off a 16-wire strip from the female-female ribbon cable assembly from the parts list. Connect one end of this cable to the LCD male header pins, as shown in figure 3-5, below. Be careful to place the connections in the order of the wires in the ribbon cable; the wires are one-to-one in order between the LCD module and the corresponding 16-pin male header on the PCB. The cable listed in the parts list is about 8” long; however, shorter wires (4” or longer) may be more convenient, if you have them.


Figure 3-5. LCD cable.

The next step is to prepare the PN-532 RFID module for mounting and cabling. If the module does not have male pin headers soldered onto it, break off a 4 pin section of Male PCB headers and an 8 pin section of male PCB headers and carefully solder them onto the component side of the PN-532 RFID reader module, as shown in figure 3-6. Use electrical tape to hold the headers in place on the top of the board while soldering to the bottom side of the module. Take care to ensure that the pin headers remain vertical while soldering them into place.

A 5-wire strip of female-female ribbon cable is used to connect this module to the RFID male header connector on the PCB. Four of the wires attach to the 4 pin header marked: GND, VCC, SDA, SCL, in order. The fifth wire attaches to the IRQ pin on the 8-pin male header. The other 7 pins on this header are not connected. Make a careful note of which color wire is attached to which pin for later connection of this 5-wire cable to the electronics PCB.

Figure 3-6. Cabling the RFID board.

There are a set of 2 micro-miniature DIP switches just below the 4 pin header on the RFID module. Carefully remove the plastic covering these switches and use a tiny screwdriver to set them as shown in figure 3-7. Double check that these switches are set as in the figure and 3-7 and fully seated into these positions. Otherwise, the RFID module will not work!


Figure 3-7. Setting RFID DIP switches.

The custom electronics PCB was assembled in an earlier step. It is now time to connect the patch antenna to the WiFi u.FL connector in the Argon module that is in the PCB, See figure 3-8 for details.

The u.FL connector is very small and quite hard to position so that it snaps into place securely. A closeup of this connection is shown in figure 3-9, illustrating correct insertion of the antenna connector onto the Argon module.

Next, use a hot glue gun to glue the PN532 RFID module to the underside of the front panel. Position the RFID module so that the male pin headers are away from the micro USB connector on the electronics PCB when the PCB is mounted as shown in figure 3-10 below. Glue down just the corners of the module and let the glue cool before proceeding.


Figure 3-8. Connect WiFi antenna to Argon.

Figure 3-9. WiFi antenna detail view.

Now, we are ready to mount the custom electronics PCB onto the screws in the enclosure panel, as shown in figure 3-10, below. Mount the PCB so that the 16 pin LCD header connector is adjacent to the LCD module and connect the LCD ribbon cable female pins to the male pins on the PCB, as shown in the figure. Make absolutely sure that that cable connections are one-to-one between the LCD module and the PCB; no wires should be crossed. Use the wire colors to double check your work!

Figure 3-10. Mounting and cabling the PCB.

Next connect the 5-wire ribbon cable from the PN532 RFID module to the PN532 male header connector on the PCB. Make sure that the corresponding signals are connected to the correct pins, as indicated by the labeling on the PCB.

Finally, connect the cables from the pushbutton switches and the green LED to the corresponding male header pins on the PCB, following the labeling on the PCB. Go back to your notes about which color wire is connected to which contact on the pushbutton and the LED to ensure that you connect the correct wires to the correct pins. The LED connections are polarized and the LEDs will not light of the connections are reversed.

The final step in the enclosure assembly is to mount the pigtail power cable on the enclosure and connect it to the micro USB on the Argon module. See figure 3-11 for details.


Figure 3-11. Mounting the power cable between the PCB and the enclosure.

The power cable comes with its own box mounting screws. The enclosure is laser cut with power cable mounts on each side and on the back of the enclosure. Mount the power pigtail cable to the enclosure wherever it makes most sense to bring power to the RFID Station when it is mounted in your facility. Take care to route the power cable so that it does not interfere with the ribbon cables connecting the RFID module to the PCB. If necessary, re-route the RFID module ribbon cables to not interfere with the power cable route.

The enclosure is now complete. The top panel can be flipped over so that the electronics mounts inside of the enclosure and the top panel is seated correctly into the box.
Eight black M3 machine screws and nuts are used to fasten the top panel firmly onto the rest of the enclosure. There are cutouts in the side of the enclosure to fit in the screw body with a nut attached to it. The knurled screwheads can then be manually tightened to hold the cover firmly to the rest of the enclosure. However, we recommend that you power the electronics and test it out before you close up and fasten the enclosure.

You can now connect the power to the power pigtail cable on the enclosure, using the USB 5 volt power supply and a USB A/B male cable. The Argon should go through its bootup procedure and you should follow Particle’s directions to claim your Argon to your Particle account, if you haven’t already done so. (https://docs.particle.io/quickstart/argon/) (https://docs.particle.io/tutorials/device-os/led/argon/).

After the RFID Station powers up, you should look at the LCD module. The LCD should be lit up. Take a small screwdriver and adjust the 10 k ohm trim pot (R6) on the electronics PCB until each of the 2 rows of 16 characters is illuminated but the background of the LCD is dark. There won’t be any useful information on the LCD at this point in time, but the LCD contrast will be optimized using this procedure.

# FIRMWARE INSTALLATION AND TESTING

INSTRUCTIONS.

After capturing the Argon to your Particle account, you need to flash the firmware to it. Comprehensive testing of the RFID Station requires a complete system installation. This includes setting up secret encryption keys, configuring EZ Facility for API access, setting up and configuring the Facility Database, setting up Particle webhooks that interact with the Facility Database and EZ Facility, and flashing the station firmware to the Argon. See the document “RFID_System_Build_and_Install_Manual” in the Documents folder in this repository for details.

Once the system is set up and firmware flashed to the RFID Station, the Station will boot up into the DEFAULT station type. When this happens, the following should be observed:
- The red REJECT pushbutton LED lights continuously.
- The green ADMIT pushbutton LED lights continuously.
- The green READY LED lights continuously.
- The buzzer sounds briefly.
- A message is displayed on the LCD panel.

If these tests all pass, the RFID Station can be set to be another station type using the MN_Station_Configurator app or the Particle Console. See the “RFID_System_Build_and_Install_Manual” for details.

If these tests do not pass, or if the RFID Station does not respond to an RFID card being presented to it, see the Troubleshooting section, below.

TROUBLESHOOTING.

This section is intended to help you troubleshoot your RFID Station in the event that there is a hardware problem with your Station. This is not intended to be a comprehensive troubleshooting guide, but the information may be helpful for common problems.

The Station Appears Dead.

If there are no lights, sounds or any signs of life, the first thing to check is the power. The PCB has an expansion connector field (XPND) with +5 volts, +3.3 volts, and two GND pins on it. Take a multi-meter and check for the presence of 5 volt and 3.3 volt power to the PCB. The +5 volt power should be between 4.5 and 5.5 volts. The +3.3 volt power should be between 3.0 and 3.6 volts. If any of these tests fail, check the following:
- Make sure that you have USB power to the micro USB connector on the Argon. Check all power supplies and cables.
- Make sure that the Argon is inserted correctly into the header socket pins.
- Make sure that the 74AHCT125 IC is inserted correctly into its socket. Unpower the PCB remove this chip from its socket and then repower the PCB and check the voltages again. If the power is now correct, then something is wrong with this IC or its insertion into the board.
- Remove power and remove the Argon from its socket. Place the Argon on a flat, non-conducting surface and plug USB power back into its micro USB socket. If the Argon comes up powered properly, then there is something wrong with the PCB. If the Argon does not come up properly, then the Argon module is bad.
- If the PCB has a problem, carefully check and then double check all solder connections. Make absolutely sure that there are no solder bridges, either between solder connections and/or between a soldered pin and a via on the PCB. Also, make sure that there are no cold solder joints anywhere on the PCB.
- Remove the Argon and the 74AHCT125 IC from their sockets. Remove all cables from the PCB. Use a multimeter to check the resistance between +5 volts and GND and between +3.3 volts and GND. The +5 Volt – GND should read as an open circuit. The +3.3 volt – GND should read about 10 K ohms (owing to the LCD trim pot R6). If this is not the case, then there is something wrong with the PCB assembly.
- If the PCB checks out OK, then put the 74AHCT125 chip and the Argon back into their sockets but do not reconnect any of the external connections to the PCB. Power up the Argon and check the +3.3 volt and +5 volt supplies. If these are OK, then the cabling to the PCB is the problem. If not, then the board is the problem.
- Unpower the PCB. Re-cable each component to the PCB, one component at a time, and then re-power the PCB: READY LED, ADMIT pushbutton, REJECT pushbutton, LCD, and RFID module. If there was a cabling problem, it should be apparent in this process. If not, then the bad external component should be apparent in this process. Check the polarity on the LEDs and the cable and solder connections to each of these external components until the problem is isolated and corrected.

Checking out the Buzzer, Pushbutton LEDs and READY LED.

If the PCB seems to come up OK but any of these components does not seem to be operating, then carefully check the connections between the affected component and the PCB. Make sure to double check the polarity of LEDs. If an LED is wired backwards, it will not light up. Likewise, if the buzzer was inserted backwards, it will not sound.

The Particle Tinker app can be used to test out these components by setting the relevant Argon pin to HIGH (to activate the component) and LOW to deactivate it. The Argon pins to activate are as follows:

- Buzzer – pin D2
- Ready LED – pin D4
- Admit (green) pushbutton – A4
- Reject (red) pushbutton – A5

NOTE: These devices are level-shifted from 3.3 volts to 5 volts using the 74AHCT125 IC. If the component is correctly wired to the PCB, use a multimeter to check the voltage out of the relevant pin on the Argon and the voltage out of the relevant pin on the level shifter IC. The IC may be bad or a pin may not be correctly inserted in the IC socket, or the socket might not be soldered correctly to the PCB.

Checking out the LCD Display.

If the PCB seems to come up OK but the LCD is completely dark, then the LCD has been cabled incorrectly to the PCB, or else the header pins are not correctly soldered to the LCD or else the PCB or the cable itself has a defect. Carefully check all connections. Note: it is very easy to get wires crossed in the interconnecting ribbon cable, so triple check your connections!

LCD pin 15 should have 3.3 volts to it – this is the backlight power pin. The corresponding backlight ground pin is pin 16. Check that backlight power is on the LCD. You might want to remove all of the other cable connections to the LCD module except for these two pins and make sure that the backlight is wired correctly. If there is power across pins 15 and 16 and the backlight doesn’t come on, then the LCD module is bad.

If the LCD backlight is on but there is no display on the LCD, and if the cabling between the PCB and the LCD is correct, then the first thing to do is to adjust the trim pot (R6) on the PCB. Turn the pot control until the maximum contrast between the characters and the background is obtained.
If the LCD is backlit and the contrast is correctly adjusted but there are no characters on the display, then either the cabling is bad, the connector pins on the LCD or the PCB are not soldered in well, or there is a solder short in the connector or the cabling is incorrect or the cable wires are bad. Triple check all of these things. It is very easy to have a female cable connector not be plugged into the male board connector pin but look like it is connected properly, owing to the density of this connector. If everything else looks good and the LCD seems to be working but the information displayed is not correct, then reset the Station and try again. If this does not work, re-flash the firmware to the Station and try again. If all else fails, go to the Particle web IDE and look for the “LiquidCrystal” library. Load the test code “Spark-HelloSparkey.cpp” into the web IDE. Change the pin definitions as follows:
- LCD RS – Argon A0
- LCD EN – Argon A1
- LCD D4 – Argon A2
- LCD D5 – Argon A3
- LCD D6 – Argon D5
- LCD D7 – Argon D6

So, the declaration in the test code should be:

LiquidCrystal lcd(A0, A1, A2, A3, D5, D6);

After making this change to Spark-HelloSparkey.cpp, compile this code in the Web IDE and flash it to the Argon to test out the connections to the LCD.

Checking out the PN532 RFID Module.

If the PCB seems to come up OK but if the Station doesn’t respond to the presence of RFID cards, then there may be a problem with the PN532 RFID module. The first thing to note is that the little yellow LED on this module is lit. If it is not lit, then the module does not have power from the PCB. Check the cabling between the PN532 pin header on the PCB and the RFID module. Make sure that +5 volts and GND are correctly cabled. The LED on the RFID module must be lit to indicate that the module is powered.

Next, check the micro DIP switch settings. The PN532 RFID module will not work if these DIP switches are not set properly. See figure 3-7 in this document for the correct settings of the DIP switches. NOTE: the DIP switches are very small and hard to see. Flip each switch back and forth to make sure that the final setting of each DIP switch is positively in place.

If the DIP switches are properly set, double check the cabling between the module and the PCB. Make sure that the INT pin, which is on a different connector on the module from the other connections, is connected to the INT pin on the PN532 header connector on the PCB.

Make sure that you are using Mifare Classic 1K cards! An incorrect card type may not give any response when presented to the RFID module in the Station.

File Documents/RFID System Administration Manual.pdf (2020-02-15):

# RFID System Administration Manual

This manual is intended for the technically sophisticated person who is responsible for the configuration and maintenance of the RFID system. This person needs a broad understanding of the facility’s CRM system, policies, and objectives in using the RFID System. This person needs a working knowledge of MySQL, PHP, FTP, Particle.io, Arduino programming, and GitHub. If you do not have these skills, you will need access to resources who can help you with tasks.

This manual assumes you have built and installed the RFID System. This includes:

1. Building the RFID Station hardware (ref: RFID Build and Installation Instructions document in the “hardware” folder of the repository).
2. Setting up the facility’s Particle.io account (ref: Configure Particle.io in the “Software/Particle_SW/ParticleCloudSoftware” folder of the repository).
3. Creating the Facility Database and associated website on a cloud server (ref: Facility Database Admin Help document in the “Software/Facility_Database_SW/” folder of the repository).
4. Installed and configured the two Android control apps (ref: RFID_Administrator_User_Manual in the “Software/Android_Apps” folder of the repository).
5. Configured your CRM system to interface to this RFID System (we document connecting it to EZFacility in Configure EZFacility for API Access in the “Documents” folder of the repository).

# Theory of Operation

RFID Stations accept taps of RFID cards. The stations validate the card against the CRM system to decide if the card is valid and to obtain other information about the associated member. The stations will perform their operation, provide feedback to the user, and log information in the Facility Database. The Facility Database website generates various reports from the logged information.

Each RFID Station is configured to have a particular operation. The configuration is specified by a Station Type Number and the RFID Station stores this number in non-volatile memory. Upon boot up the RFID Station will request configuration parameters from the Facility Database for its Station Type Number. (To set a Station to a particular type see
RFID_Administrator_User_Manual in the “Software/Android_Apps” folder of the repository.)

The Station Types fall into four categories:

Type | Description
0 New | A brand new RFID Station will boot up in this state. All lights are on and the LCD shows characters. This is used for validating your hardware build and firmware installation. A station of this type displays “Undefined” on the LCD.
1 Check In | Check In Station. Tapping a valid RFID card on this station will check for a valid membership in the CRM system and add a record to the Facility Database noting that this member is now checked-in. Tapping an RFID card for the same member will add a record to the Facility Database noting that this member is now checked-out. This can be repeated over and over in one day. An idle station of this type displays “Tap to CheckIn” on the LCD.
2 Admin | Admin Station. This type is meant to be controlled by the Android admin app. An idle station of this type displays “Use Android App” on the LCD.
Area Stations | These stations are assigned to a particular area or machine. Tapping a valid RFID card on this station will check the CRM system to verify member permission and add a record to the Facility Database noting that the user has tapped the station. These stations obtain their configuration from the Facility Database when they boot up. These stations all have similar operation.

# Install Firmware

To install the RFID System firmware you must download and install the Particle.io Workbench development environment. This environment is based on Visual Studio Code. It is freely available at https://www.particle.io/workbench

## Visual Studio Code Tips

Visual Studio Code runs a plug-in from Particle. Here are a few tips to get you started.

When you start VSC you should open the workspace: rfidsystem.code-workspace in the repository. You should see this:


Click the top most left icon and open EXPLORER. Navigate to the checkinfirmware.ino file and open it:


Open the Particle plug-in with the lowest icon on the left hand navigation menu.

Scroll down in the Particle Workbench tab to see this:


Click > Particle Login and supply your Particle.io account credentials

Under TARGET, click Configure for device. Select the OS firmware version (if you don’t know then just select the most recent recent version. Then type in the name you assigned to the Argon you are using for development.

Under COMPILE, click Local compile. If the code does not successfully compile, then you need to figure out why. Once the local compile works...

Under FLASH, click Cloud flash. See your Argon updated with the code!

## Tests

1. Push the current code to your Argon. (If you followed the VSC tips above, then you just did this.)
2. Use the Particle Console to make it DeviceType 1
3. Tap each card in turn on your device, see the result and note that it corresponds to what is written on the card. If each card works, then you are ready to go.
4. Look at the test logging database to see if your taps have been recorded: http://rfidsandbox.makernexuswiki.com/rifdhome.html

# Adding a New Station Type

Each station type number has a record in the Facility Database table stationConfig. The Android station configuration app retrieves a list of valid station numbers and names to present to the admin user.

The Android Station CStation Types other than 0, 1, and 2 retrieve their configuration parameters from the Facility Database when they boot up.

You add a new type, or change the behavior of an existing type, by altering the stationConfig table in the Facility Database.

## How to Add a Station Type

To add a new Station Type, use PHP Admin or another MySQL tool to insert or update records in this table.

## Field Definitions

### stationConfig Table

Each field in the database has a comment explaining its use. This is reproduced here with some elaboration:

### recNum

An automatically created unique number and should never be changed. If you understand databases, then you understand why we have this. If not, you should be careful about what you do in this database.

### Active

If <> 0 this is the active record for the deviceType. There must be only one active record for each deviceType. This field allows the administrator to change a device type by adding a new record and marking the old record with Active = 0, thus preserving the previous configuration in case you need to quickly revert.

### deviceType

This is the number used by a Station when asking for its configuration parameters. The system will return the active configuration for this deviceType.

### deviceName

When Stations of this type make log entries in the Facility Database they will use this name to identify its type. Typical values are: “checkin”, “admin”, “woodshop”, “3D printer”, etc.

### LCDName

When idle, Stations of this type will display this value on their LCD displays. The value should be less than 16 characters. Typical values are: “Woodshop”, “Laser Cutter”, “Bandsaw”, etc.

### photoDisplay

When a user taps on a Station of this type, the Station will log this value in the Facility Database. This value will eventually be displayed under the member’s name on the Checked In photo display web page. To keep the web page clean, this value should be very short. Typical values are: “Wood”, “3D”, “Laser”, etc.

### OKKeywords

This field provides the tie between your RFID System and your CRM member certification system. You must set up your member certification choices in a way that allows you to define keyword groups that will work in your RFID system to achieve your objectives.

A comma delimited list of keywords. Stations of this type retrieve member certification information from the CRM system (in EZFacility these are called “packages”) and scan that certification information for these keywords as substrings. If any of the keywords is found then the member is assumed to have permission to access the area or equipment associated with this type of RFID Station. For instance, a “woodshop” Station might look for the keyword “wood” in the certification information.

Typical values are: “wood”, “3D”, “consew”, etc.

### logEvent

Devices of this type will use this as the Particle Event Name when they log information to the Facility Database. It may be used in reporting. Typical values are: “wood allowed”, “textile allowed”, etc.

This field may seem redundant at this time, but we include it to allow for possible future expansion of the Station operations.

### dateCreated

Defaults to CURRENT_TIMESTAMP and should not be overwritten.

# Test and Troubleshooting

At this point you have
- Built your hardware and tested it per the documentation
- Installed your database and website and tested it per the documentation
- Installed your Particle.io webhooks and tested them per the documentation

Now you are ready to test the overall system.

## Configure a Station

Use the Android Admin app to configure an RFID Station as an Admin Station. Use the webpage rfidclientactivity.php to verify that reboot log messages are making it into the database.

1. If the Admin app does not show a choice of Station Types
a. goto URL
http://<<YOUR FDB WEBSITE>>/fdbGetStationConfig.php
Does the returned JSON contain the list of station types and names?
b. In the Particle.io console
i. Look at the history of the Integration fdbGetStationConfig. If this has not been triggered then your Argon is not communicating with the cloud for some reason.
ii. | Look at the event history for your device. Read the Debug events for any
| errors.
2. If the reboot messages do not show up on the web page then use the Particle.io console
a. Look at the history of your device to see that events have been sent to the database.
b. Look at the history of the Integration RFIDLogging . In particular, look at the response and see if there is a PHP or MySQL error in the website response.

## Create RFID Cards

Configure an Admin Station and create RFID cards for several members. Use the Identify Card function to verify that the cards were created correctly.

1. If the cards cannot be read, are they the correct RFID cards for this system? White ID cards all look alike, yet some operate on different frequencies and some are inert without any RFID functionality.

## Check In

Configure a Check-In Station. Present the cards you created. The Check-In Station should read each card and log to the Facility Database. Use the website page rfidcheckinlog.php to verify that the check in worked. Use the website page rfidcurrentcheckins.php to see that the checked in members are shown. Tap a card again to check out a member. See that they disappear from the currentcheckins page.

1. If you get a red “denied” light, look at the Firmware procedure isClientOKToCheckIn(). This is where the decision is made.

### Area Station

Configure an area station based on the configuration you established in the stationConfig table. See that the LCD displays the name. Tap one of the cards you created and see if the member is allowed or denied depending on the certifications you have set up in your CRM system. Use the website page rfidcurrentcheckins.php to see that the checked in members are shown with the Stations photoDisplay text displayed below their name.

1. If you get a red “denied” light, look at the Firmware procedure isClientOKForEquip(). This is where the decision is made.

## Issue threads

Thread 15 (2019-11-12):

Card Check-in Issues

BobGlicksman, 2019-11-12:
I'm starting a list of issues that we find in testing.

1. Checkin a member who owes money:  The firmware sounds the "bad" sound, lights the red LED,  and puts a message to see the manager on the LCD -- all is good.  But then, after the bad sound, the red LED goes off, the green LED goes on and the LCD message changes to welcome <member name> or goodbye <member name>.  Is this second part correct, or should the member be rejected? Also, after the first goodbye message, the next message is also goodbye (not welcome).

2. Checkin a member who does not have a contract:  The firmware sounds the "bad" sound, lights the red LED,  and puts a message "no contract"r on the LCD -- all is good.  But then, after the bad sound, the red LED goes off, the green LED goes on and the LCD message changes to welcome <member name> or goodbye <member name> Is this second part correct, or should the member be rejected?  Also, after the first goodbye message, the next message is also goodbye (not welcome).

BobGlicksman, 2019-11-12:
NOTE:  the green light after the red light ONLY happens after a good member checkin.  When the device is initialized, bad member checkins result in the red light and associated message only.  After a good member checkin, the bad checkins have this 2 phase behavior; however, the bed member name is displayed (not the previous good member name)!

jschrempp, 2019-11-13:
You are correct that we are missing a break at line 1442.

BobGlicksman, 2019-11-13:
Please commit the change and send me a pull request.  No sense both of us making the same change and somehow getting us out of sync!
Bob

-----Original Message-----
From: Jim Schrempp <notifications@github.com>
To: BobGlicksman/MN_ACL <MN_ACL@noreply.github.com>
Cc: Bob Glicksman <bobg542492@aol.com>; Author <author@noreply.github.com>
Sent: Tue, Nov 12, 2019 4:55 pm
Subject: Re: [BobGlicksman/MN_ACL] Card Check-in Issues (#15)

You are correct that we are missing a break at line 1442.—
You are receiving this because you authored the thread.
Reply to this email directly, view it on GitHub, or unsubscribe.

Closed 2019-11-27.

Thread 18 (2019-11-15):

In state machine routines explicitly set state in all cases

jschrempp, 2019-11-15:
The current code uses a state machine pattern in several cases where we have to wait on input. A typical situation is:

```
switch (loopstate)
case state1
    loopstate = state2
    starttime = millis()
    startNonblockingOperationSuchAsAWebCall()
    break;
case state2
    if (wait case satisfied) {
         do something
         loopstate = state3
    } else if (timer limit exceeded) {
         flag / announce the error
         loopstate = state1 // or wherever you go after an error
    } else {
         //remain in this state
    }
    break;
```
The proposal was to replace the // remain in this state   comment with explicitly setting the loopstate variable to the current state.

jschrempp, 2019-11-15:
I put a few of these in but seeing
```
// remain in this state
loopstate = state2
```
while in state2 didn't look right. It looked like we were setting the loopstate to change, when we really are not. I feel that the comment is actually less confusing.

One option could be to make it
```
// remain in this state
loopstate = loopstate
```
as that would clearly show that we are not changing state. But it didn't feel good either.

I think our objective is to make the code easy to read and understand. This is my current opinion, but I'm interested in other's perspectives.

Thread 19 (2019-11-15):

Reboot once a day

jschrempp, 2019-11-15:
We use a lot of Strings and it would be good to reboot once a day. Why not?

Concept would be to have a routine called every pass through the main loop. The routine testForReboot() would keep a static variable of millisToReboot, initialized to -1. The general flow would be:
```
void testForReboot(){
  static millisToReboot = -1

  if (millisToReboot = -1) {

      if (time is 1 am) {

         // schedule a reboot
         millisToReboot = millis() + 300000  // reboot in five minutes

      }

      // trigger not set and it is not 1 AM so do nothing

   } else if (now > millisToReboot) {

       // we've exceeded the trigger time
        put reboot on LCD screen
        system.reboot()

   }
```

jschrempp, 2019-11-27:
You can assign this to me I'm working on it now.

Closed 2019-12-01.

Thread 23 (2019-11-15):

Move client info JSON deserialization to a common routine

jschrempp, 2019-11-15:
Two routines have JSON parsing in them of almost the same JSON.
```
clientInfoFromJSON()
clientInfoFromJSONArray()
```
The issue comes about because EZFacility returns either a flat JSON or a JSON array with one member in it. Looking into the two routines above, there should be a way that the ...Array() version unpacks the member and then calls a common routine (or even just passes the JSON string to the other routine). Damn if I can figure out how to do this with ArduinoJSON.

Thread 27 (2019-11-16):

Enh: setDeviceType should return a value

jschrempp, 2019-11-16:
Today setDeviceType sets the type in EEPROM then calls for a system.reboot. This means that it does not return a value. When calling this routine from the cloud, the caller is left hanging without a return code.

The suggestion here is to have setDeviceType set a global reboot flag somewhere, then exit returning a value. Some other heartbeat routine called from the main loop would then see the reboot flag and cause the reboot.

BobGlicksman, 2020-01-05:
The current RFID Station Configurator app looks for a return value but only uses it to un-gray the button that caused the cloud function to be called in the fist place.  Neither response codes nor return values are processed (except when the function is called with a -1 argument, which does have defined return values).  When/if this suggestion is implemented in the firmware, the app should be enhanced accordingly.

Closed 2020-01-11.

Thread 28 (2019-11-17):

Device Type 0 should light all LEDs

jschrempp, 2019-11-17:
When a device is first turned on it comes up as Device Type 0, Undefined. This is often the case when a new device is built. It would be good to have all the LEDs turned ON in this state. It will make connecting the LEDs to the PCB easier to test when building it.

jschrempp, 2019-11-27:
#34

Closed 2019-11-27.

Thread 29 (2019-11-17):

Bug: Admit woodshop failed member # 100371

jschrempp, 2019-11-17:
This member has a woodshop package but the device reported "woodshop not found"

jschrempp, 2019-11-27:
I have been unable to reproduce this in the dev environment.

jschrempp, 2020-01-10:
We cannot reproduce this on the current code.

Closed 2020-01-10.

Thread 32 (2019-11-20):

Goodbye after revoked card error

jschrempp, 2019-11-20:
Sarah reported that after swiping her card she "got an invalid error which then mentioned goodbye. " The device log is below. Her card was valid, but I suspect the swipe was so fast we read the first sector but not the second.

However, after a revoked card error we should not say "goodbye". Seems like bad behavior after an error condition.

2163 | 2019-11-19 19:39:58 | RFIDLogging | ... ec572e74 | Check In | checkin denied | ... 51426 | Sarah | Card revoked 1
-- | -- | -- | -- | -- | -- | -- | -- | --
2164 | 2019-11-19 19:40:11 | RFIDLogCheckInOut | ... ec572e74 | Check In | checkin allowed | ... 51426 | Sarah |  
2165 | 2019-11-19 19:40:11 | RFIDLogCheckInOut | ... ec572e74 | rfidcheckin.php | Checked In | ... 51426 | Sarah |  
2166 | 2019-11-19 22:34:14 | RFIDLogCheckInOut | ... ec572e74 | Check In | checkin allowed | ... 51426 | Sarah |  
2167 | 2019-11-19 22:34:14 | RFIDLogCheckInOut | ... ec572e74 | rfidcheckin.php | Checked Out | ... 51426 | Sarah | 174

BobGlicksman, 2019-11-27:
Possibly related to this (and perhaps other issues as well) is not checking the return from readCardData().  There are multiple internal checks to ensure that authentication and data reading is correct and if any of them fail, the return value is false.  The return value is only true if all internal tests pass.  However, when I used this function in my card testing code, I got sloppy and didn't bother to test the return value.  So it is possible that card reading failed (e.g. due to not leaving the card tapped long enough) so that the data in the body of the firmware is not updated, but the state machine thinks that the data is good, resulting in various errors that report incorrectly.  I believe that my sloppy function calls got copied into the production firmware and I think that testing the return value and taking appropriate action on a read failure will solve this issue (and possibly others).

BobGlicksman, 2019-11-27:
I found this snippet at line 605 of mnrfidutils.cpp:

case 1: {
        // MN formatted card
        Serial.println("\n\nCard is type Maker Nexus formatted\n");

        // now read the data using MN Key and store in g_cardData
        readBlockData(dataBlock, 0,  0, g_secretKeyA);

This is from readTheCard(), which I believe is called from a number of places within the main firmware.  I think that if the return from readBlockData() is processed, it may resolve this, and other, issues related to a "too fast tap".  The only question is: what, exactly, to do if the return value is false.  I'm not sure if it is appropriate to handle this within readTheCard() [i.e. in one place] or whether this needs to be passed up the line and handled at higher levels.  We should review the code together to determine how, exactly, to handle a false return value.

jschrempp, 2019-11-27:
readTheCard already does beep the user depending on success or error(s). In the last commit I changed it to this
```
        bool result0 = readBlockData(dataBlock0, 0,  0, g_secretKeyA);
        bool result1 = readBlockData(dataBlock1, 1,  0, g_secretKeyA);
        Serial.println("Remove card from reader ...");
        writeToLCD(" ","Remove card ...");
```
So that the reads happen as close together as possible. And then later test both result0 and result1, beeping and displaying an appropriate message if either is false.

jschrempp, 2019-11-27:
In terms of speed of tap, I don't know how long authenticateBlock takes, but in testCard we first test for default keys and if that fails we test for MN keys. It might be better to test for MN keys first since that is the most common use case. However, if authenticateBlock is really fast, then it does not matter.

BobGlicksman, 2019-11-27:
Ah yes -- I now see the pull request for the updated routine.  I'm not sure that it was necessary to record both read status' -- if either one results in error, some data in some buffer will be old and should not be used.
I'll flash this update code to my test box and try some tests, albeit it is not an easy thing to reproduce.
Bob

-----Original Message-----
From: Jim Schrempp <notifications@github.com>
To: BobGlicksman/MN_ACL <MN_ACL@noreply.github.com>
Cc: Bob Glicksman <bobg542492@aol.com>; Comment <comment@noreply.github.com>
Sent: Wed, Nov 27, 2019 10:29 am
Subject: Re: [BobGlicksman/MN_ACL] Goodbye after revoked card error (#32)

readTheCard already does beep the user depending on success or error(s). In the last commit I changed it to this        bool result0 = readBlockData(dataBlock0, 0,  0, g_secretKeyA);
        bool result1 = readBlockData(dataBlock1, 1,  0, g_secretKeyA);
        Serial.println("Remove card from reader ...");
        writeToLCD(" ","Remove card ...");
So that the reads happen as close together as possible. And then later test both result0 and result1, beeping and displaying an appropriate message if either is false.—
You are receiving this because you commented.
Reply to this email directly, view it on GitHub, or unsubscribe.

BobGlicksman, 2019-11-27:
It would probably be best to test for MN keys first, but I think that the time is tens of milliseconds.  No matter what order we do things in, the real issue is having the user present the card long enough to complete the operation.  So as long as we can detect that the card has been removed too soon, I think that the order of testing is not important.  There will always be the possibility of the user just waving their card past the reader so that the card is removed before all authentication and reading operations complete -- no matter what order we do things in.
Bob

-----Original Message-----
From: Jim Schrempp <notifications@github.com>
To: BobGlicksman/MN_ACL <MN_ACL@noreply.github.com>
Cc: Bob Glicksman <bobg542492@aol.com>; Comment <comment@noreply.github.com>
Sent: Wed, Nov 27, 2019 10:32 am
Subject: Re: [BobGlicksman/MN_ACL] Goodbye after revoked card error (#32)

In terms of speed of tap, I don't know how long authenticateBlock takes, but in testCard we first test for default keys and if that fails we test for MN keys. It might be better to test for MN keys first since that is the most common use case. However, if authenticateBlock is really fast, then it does not matter.—
You are receiving this because you commented.
Reply to this email directly, view it on GitHub, or unsubscribe.

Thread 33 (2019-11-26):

Cleanup: Woodshop device issues false debug warning

jschrempp, 2019-11-26:
The woodshop device calls RFIDLogging hook
```
"name": "RFIDLogging",
  "data": "{\"dateEventLocal\":\"2019-11-26 10:33:48\",\"deviceFunction\":\"Woodshop\",\"clientID\":21613660,\"firstName\":\"Jim\",\"logEvent\":\"Woodshop allowed\",\"logData\":\"\"}",
```
which is not expected and causes a false debug error
```
unknown particle event 2: e00fce683ce9c5a9e5a4f43dmnlogdbCheckin/0 |
```

jschrempp, 2020-01-11:
I am unable to duplicate this in the current 1.52 code. It may be that this was cleaned up earlier and I failed to close the issue.

Closed 2020-01-11.

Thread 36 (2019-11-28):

Get an oAuth token proactively

jschrempp, 2019-11-28:
An oAuth token for the EZFacility CRM system is only good for one hour. If a person uses a device more than one hour after the last user, they must wait for us to acquire a new token. This takes time and adds to the overall response time to the user. Often we see that "the first" attempt to badge in times out and the second attempt "is fast".

This enhancement request is to get a new oAuth token every hour whether we need it or not.

The routine ezfGetCheckInToken() checks if the current token is still valid. If so, the routine just exits. We could call ezfGetCheckInToken() every time though the main loop, but this could lead to multiple calls to the token issuer while the transaction is in flight.

Recommended solution is to add an element to the global token structure that holds the time when we made the most recent token request. A new token request would only be started if 1) we did not have a valid token before (this is probably the first call after a reboot) and 2) the previous request was made more than 20 seconds ago (we can assume the previous request failed to complete for some reason). With this rate limitation in place we can then add a call to ezfGetCheckInToken() to the main loop.

Of course in the main loop we should bracket that call so that it only happens between the hours of 9am and 11pm. This is enough of a time buffer around our open hours of operation. If someone did badge in outside of these times the system would still work, but the checkin might take longer as the system obtains an oAuth token.

Closed 2019-12-01.

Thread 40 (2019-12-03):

Tried to getPackage with null token

jschrempp, 2019-12-03:
Today I observed the woodshop test box doing a request for packages information with a null token. This, of course, did not work and resulted in the user getting a "timeout packages" error.

I have a screenshot of the particle console showing the traffic. We know the device had a valid token because it had just successfully completed a ezfClientByClientId call.  The trace shows

```
ezfClientByClientID
ezfCheckinToken   (why is it asking for a token?)
debug - JSON Parse Error  (as it is getting bits of the token)
ezfGetPackages    (which has a null token)
debug - have token now
debug - 15 second timer expired waiting for get packages
```
There is a window where this could happen ... The code checks for a valid token and decides the current one is good, moves on. Meanwhile the global check token routine sees that the token is expired and wipes it out before going to get a new token. Now the main code asks for packages with a null token. However, this is a tiny window and it seems unlikely that I would hit it on my first test.

Note that the box had been idle for 12 hours. The box was running the 1.41 code that gets tokens proactively.

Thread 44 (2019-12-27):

Enh: indentification of station type

BobGlicksman, 2019-12-27:
If the cloud function setDeviceType() is called with a -1, issue a beep (as now) but also return the integer code for the current type of that station.

BobGlicksman, 2020-01-05:
Implemented in the latest firmware,

Closed 2020-01-05.

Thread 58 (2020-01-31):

Bug: Set Dev Type does not work for type 0

jschrempp, 2020-01-31:
Reported by Bob G on latest firmware.

jschrempp, 2020-02-27:
Well, how dumb is this?

`Converts a valid String to an integer. The input string should start with an integral number. If the string contains non-integral numbers, the function will stop performing the conversion. Returns: long (If no valid conversion could be performed because the string doesn't start with a integral number, a zero is returned.)`

So, you can't convert the string 0 to an int.  I have to special case that.

Closed 2020-02-27.

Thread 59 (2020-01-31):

ENH: Dev type 0 should read a card

jschrempp, 2020-01-31:
Dev Type 0 is the base Undefined state. Mostly used for hardware verification prior to set up. It turns on all the LEDs, buzzes, and puts text on the LCD.

This enhancement is for the Undefined state machine to also read an RFID card when presented. It should not try to access the CRM since webhooks might not be set up. It should just read the card and report it on the LCD.

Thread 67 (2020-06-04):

Panic after receiving a Particle event

jschrempp, 2020-06-04:
We know that when in a Particle event handler we cannot call a Particle.publish - it causes a panic. We avoid this by adding protection in routines like particleCallbackMNLOGDB. In those routines we start by setting a global to false: allowDebugToPublish = false; As the last act in the event handler we set allowDebugToPublic to true.

The debug publish routines are called in the main loop. They all check this global before publishing and will buffer debug messages until the global is true.

In making the lockbox client I found that this protection is not enough. If the main loop is very slim it is possible for debug publish routines to be called by the main loop after the global is set to true, but before the particle OS has finished cleaning up the event handler. I saw this on a Photon running 1.4.4.

jschrempp, 2020-06-04:
My suggested fix is to change the global variable from a boolean to an unsigned long and when a particle event handler is entered set the variable to max_value. Then when exiting the event handler set it to millis() + 500. The debug publish routines will not check for true, but check to see if current millis is > the global variable.

This will delay debug publishing for one half second after the event handler ends, but that is not a big deal.

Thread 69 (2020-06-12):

ENH: Reply with error when devType set to >999

jschrempp, 2020-06-12:
We are reserving device types over 999 for Lock Boxes. The RFID station should return an error code if asked to take a devType over 999

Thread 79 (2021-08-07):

Wrong name on checked-in display

jschrempp, 2021-08-07:
Today I found that the checkin screen had a photo of Emilio with the name "Angel" under it. Angela had been in the makerspace earlier that day but was not there at the time I saw this.

Looking at the page source, the clientID associated with the photo was indeed the correct one for Emilio.

Looking in the database I found that in the clientInfo table, the clientID for Emilio had the first and last name of the member Angela in it. I also found the record in the rawData table for Emilio's checkin and that also had the first name "Angela".

1. The checkin display takes the value from the rawData table. I corrected that and the checkin display was now correct. I also corrected the clientInfo table for Emilio's clientID.
2. The facility database allows for the updating of the name in the clientInfo table. When an entry is made in rawData table, if needed clientInfo is updated.

I assume there is a bug in the checkin device firmware that somehow associates the wrong name with the clientID and sends that to the facility database.

jschrempp, 2021-08-07:
I looked at Emilio's clientID in the rawdata table and all the records have the correct first name.

I then ran a data integrity check:
```
SELECT r1.clientID, r1.firstName, r2.firstName
FROM
  (select distinct clientID, firstName from rawdata where dateCreated > '20210501') r1
  INNER JOIN
  (select distinct clientID, firstName from rawdata where dateCreated > '20210501') r2
  ON r1.clientID = r2.clientID
where r1.firstName <> r2.firstName
order by r1.clientID
```
And found lots of cases where the same clientID has more than one first name.

jschrempp, 2021-08-07:
Assuming this is a transitory problem in the device code, this might not be reported because on a subsequent checkin the correct name is sent to the facility database and going forward from there everything is ok.

jschrempp, 2021-08-08:
To investigate this I wanted to find a time when a switch of names happened for a particular clientID, then see all the log records around that time. (Note that in the clientInfo table for the Angela/Emilio case above we found that both firstName and lastName were incorrect in the clientInfo table, so both were changed.)  I used the query above to find a case. I decided on a case where clientID 23632563 switched from the correct name of James to the incorrect name of Theodore. This query shows that the switch happens at dateEventLocal 2021-07-30 20:28:41

```
SELECT datePublishedAt, dateEventLocal, coreID, deviceFunction, clientID, firstName, eventName, logEvent, logData
FROM `rawdata`
WHERE
   	dateEventLocal between '2021-07-28 04:00' and '2021-07-31 05:00'
	 and clientID = 23632563
order by dateEventLocal
```
I then used this query to see all the RFID logging activity around that time:

```
SELECT datePublishedAt, dateEventLocal, coreID, deviceFunction, clientID, firstName, eventName, logEvent, logData
FROM `rawdata`
WHERE
   	dateEventLocal between '2021-07-30 19:00' and '2021-07-30 22:00'
order by dateEventLocal
```
In the attached screen shot you can see that at recNum 47455 Theodore checks in with his correct clientID of 23954790. Then 7 seconds later at recNum 47457 a client checks in with clientID of 23632563 (which should be James) but the firstName logged is Theodore.

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

There were no other log events between these two device operations. Both operations occurred at the same coreID (Argon processor) that reports itself as the CheckIn device. Notably the Front Door was not involved in this set of transactions.

I have to guess that either 1. The CRM system returned the correct clientID but the wrong first and last name, using values from the previous CRM transaction, or 2. Our firmware did not update its internal structure with the correct first and last name, using values from its previous CRM query.

jschrempp, 2021-08-08:
Looking at another name change that happens at row 45702. Gabriel is correctly clientID 23957276, but gets reported as Joseph. Joseph is correctly clientID 25249120.

```
SELECT recNum, datePublishedAt, dateEventLocal, coreID, deviceFunction, clientID, firstName, eventName, logEvent, logData
FROM `rawdata`
WHERE
   	-- dateEventLocal between '2021-07-17 02:07:24' and '2021-07-17 12:07:24'
    recNum between 45695 and 45705
	 -- and clientID = 23632563
order by dateEventLocal
```
In the screen shot you can see this is the first activity of the day, the RFID devices all show a nightly restart. The last activity on coreID ...2e74 (the checkin device) was the previous night when Robin checked out. Then the next day Joseph checks in and the correct name/clientID is used (recNum 45700). 5 seconds later clientID ...276 checks in and instead of Gabriel the name used is Joseph.

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

This data leads to the same two possible bugs as described in the previous comment.

jschrempp, 2021-08-08:
Some other recNum ranges

(May/David) 36863 - 36868  6 seconds
(Mark/David) 40907 - 40913  10 seconds

jschrempp, 2021-08-08:
Odd one. recNum  45060 - 45070

Correct Data:
clientID        firstName
26620854    Nancy
26587830    Aaron
25024020    Mark

redNum
45063  ...854 checks in with correct name Nancy
45065  ...830 checks in with wrong name Nancy   (6 seconds later)
45067  ...020 checks in with wrong name Aaron    (6 seconds later)

In this case the error happened twice in a row. Nancy checks in. When Aaron checks in the log record gets "Nancy". When Mark then checks in the log record gets Aaron.  20 minutes later another member checks in and gets the correct name in the log db.

I think this shows that the issue is in our firmware. The second checkin apparently did get the name Aaron, perhaps just too late to post to the log db. I think we may have a race condition where we send the log record before we get the final data. Personally, I thought we marked the client information as invalid once we used it; maybe not in all cases.

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

jschrempp, 2021-08-08:
Other recNum ranges:

(Tony/Robin) 43325 - 43327  10 seconds
(Heather/Curtis) 44343 - 44345  6 seconds

jschrempp, 2021-08-08:
More recNum ranges:

(Nicholas/Jason)  41345 - 41347   6 seconds
(Nicholas/Jason)  44863 - 44866   4 seconds
(Nicholas/Sarah)  8 seconds

So far every one I've looked at has been that the clientID with the corrupted name checked in within 10 seconds of the previous checkin, taking the name from that previous checkin.

BobGlicksman, 2021-08-10:
I am not inclined to limit the possible bug locations to EZF or to the firmware, as you suggest.  From what I can see, the correct clientID is always sent (correct?).  I have not looked at the PHP script nor at the fdb schema, but I have looked a lot at the name that appears on the checkin station LCD and I have never seen an incorrect name displayed (neither at MN or in testing on the development system with our test member cards).  HOW SURE ARE WE that the name from the station is actually used to directly update the relevant table(s) in the fdb?  From what you have stated above, there are multiple names associated with some of the clientID records.  The wrong name displayed could be a result of selecting the wrong name from data stored in the fdb, accounting for the wrong name on the display (correct clientID as evidenced by the correct photo).  There should NEVER be more than one name associated with a clientID.  Hence, I speculate that the fdb itself got corrupted, somehow, sometime in the past.  This could have been a long time ago and we are just noticing it now, because both the correct name and the wrong name are associated with the clientID in the fdb.

If my theory is correct, the question becomes -- how did additional names get added to some clientID records in the fdb?  It COULD have been incorrect name data sent by the checkin station, but it could have been a failure of the php script that handles the API data, the webhook that sends the API data, or even something that corrupted the fdb itself.  The point is that something strange may have happened once, a long time ago, and may not be reproducable.

I suggest cleaning out the fdb of the incorrect names, or perhaps of all of the names and let it repopulate from new checkins going forward.  We can then monitor the fdb for a while and see if any incorrect names get added to the fdb.  If this was a result of a one time unique failure somewhere (could be the Particle cloud, the web hosting service, the checkin firmware or ezfacility), we should not see any new problems.  If we do see new problems, we can then trace them to the source.

I also recommend refining the PHP script and its SQL to ONLY add name information to the table in the fdb is there is no name already in the fdb client info table.  This will ensure that multiple names cannot exist for one clientID, which is correct.  Alternatively, the fdb stores both the clientID and the  name, but deletes any old name associated with that clientID.  Either way, we eliminate the possibility of multiple names for a client ID and the potential for the wrong name to show up in the display page query.  In other words, an incorrect name cannot then come from a corrupted database and must come from the checkin station (either because of a firmware bug, or some issue with EZfacility).  Even so, this will ensure that any such occasional problem doesn't itself corrupt the fdb.  Make sense?

jschrempp, 2021-08-10:
I have found 20 cases of bad names since May 1, 2021. Since then there have been 3500 checkin events. This is exceedingly rare.

In the 10 cases I've examined, each one happened within 10 seconds of the previous, correct checkin that was the source of the bad name. It seems hard to imagine that database corruption could cause this issue by mangling so many specific cases as there is nothing in the database to tie those cases together.

Today I tried checking in two people quickly and then observing the database. I did this about 15 times. I never saw the failure.

jschrempp, 2021-08-12:
Did not intend to close this.

On 8/10 we created version 2.0 and flashed it to the checkin station at 234. This version comments out the call to inform the CRM system (EZF) that a person is checking in. We don't use that function in the CRM and we wondered if that was causing some confusion in the systems. It's a long shot, but we'll give it a try.

jschrempp, 2021-08-14:
On 8/14 we had another name mixup (Rosina/Stefan). I was able to capture the CRM responses in the Particle console integration log. The responses from the CRM system appear to be correct.

jschrempp, 2021-09-30:
Since 9/18/2021 we have not had any cases of mixed names. Could this be attributed to our upgrade to the new version of ArduinoJSON? Or the fact that we put mustache code in ezfClientByClientID to reduce the amount of data sent to ArduinoJSON for deserialization? Don't know. Will continue to monitor the FDB for this situation to occur.

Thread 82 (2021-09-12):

5 second delay on verifying client credentials

jschrempp, 2021-09-12:
We have observed that on occasion there is a many second lag between getting a successful one beep indicating a good card read and the actual "you've been checked in" or out message.

While we have done many, many test transactions this will only happen every once in a while. In one case, two hours of testing yielded only three of these events.

Occasionally, after reading the RFID card the user will get a timeout "could not get client info" error. This happens if the wait time exceeds 15 seconds.

jschrempp, 2021-09-12:
We look specifically at the period from requesting client info (ezfClientByClientID) until we log the activity to the facility database (FDB) via (RFIDLogCheckInOut).

This is a typical transaction where it all completes within two seconds.
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

Here is a transaction showing a 5 second delay between the return of the third, and last, piece of the JSON and our log to the FDB. What could be happening in that 5 seconds?
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

jschrempp, 2021-09-12:
One theory is that the Particle OS or Cloud is somehow holding off our action. This transaction list disproves that.

In this sample we enabled debugX. We also put a publish of "got client info" in the main loop state machine at the point that client_info.isValid goes TRUE. So "got client info" is published as soon as we have successfully parsed the JSON from the CRM system. Note that the last bit of JSON is sent at :17. We then see a debugX publication at :18 and another at :19; clearly the main loop is running and ParticleOS is allowing us to publish events. (debugX events are no different than other events to Particle). Finally, at :22 we see the "got client info" event and the process runs to completion.

In the analysis above the last JSON is sent at :17 but it takes 5 seconds for "got client info" to appear.

This was also running with `SYSTEM_THREAD(ENABLED);`   So having this disabled did not cause the delay.

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

jschrempp, 2021-09-12:
Not directly related, but while testing we also saw a time when another JSON deserialization process took a long time. You can see here that at :04 the Particle cloud sent the return from the FDB (`<p><ActionTaken>C...`) but at :10 we report a timeout waiting for a response from the FDB. How can that take 6 seconds?

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

jschrempp, 2021-09-12:
Current theory - something in the ArduinoJSON library is causing us a big delay. Sure, 5 seconds is eons of time, but we don't have much other code in between these two points.

We notice today that we are currently using ArduinoJSON 6.11 while the currently released version is 6.18.

Two potential next steps:

1/ Update to the new ArduinoJSON library.
2/ Implement mustache code in the Particle webhook ezfClientByClientID with the theory that our current 2.5K byte JSON package may be putting strain on the library.

jschrempp, 2021-09-17:
We updated the JSON client to 6.18.4 and did more testing. We still saw the infrequent delays.

One thing we noticed is that the Particle cloud appears to run slowly at times. In this case you'll see the cloud timestamp for publication from our device is 6 seconds earlier than the timestamp on the event saying that the webhook was sent off to the CRM system. This delay is usually sub second, and is completely out of our control. We only saw this once in all of our testing, but
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
it does show that the cloud can have delays.

jschrempp, 2021-09-17:
In another test we saw that the Particle cloud send the webhook request at :54. The EZF system responded and the Particle cloud split the response into three messages and published them all within one second at :55. We added a debug statement into our code to mark when each piece is received (note that these debugX publications are throttled to be only 1 per second). We see that our code acknowledged the first message immediately, then the next piece comes in quickly (the time delay could be due to debugX or the 1 second resolution of the Console display). However, the third piece does not arrive until 5 seconds later! While we could question whether our device held off receipt or publication for some reason, given the previous comment about cloud delays I would attribute this to the Particle cloud.

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

jschrempp, 2021-09-17:
Lastly, here's something we cannot explain. We added debugX calls before and after the calls to the JSON parse routine that calls ArduinoJSON. We had a case where three pieces were returned and then we still failed to correctly parse the client info JSON, resulting in a 15 second time out. This was the only time we saw a 15 second timeout, but we have seen them in production from time to time. Clearly, even though it seems that the device received all the three messages from the cloud, the library was still not able to parse the JSON. (We tried instrumenting more but could not get the failure again, of course.)

This becomes one more reason to implement Mustache code in the Particle webhook to cut down on the amount of data we have to receive in order for the device to do its job.

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

jschrempp, 2021-11-19:
We now know that the Particle cloud connection to the edge devices is UDP based and does not guarantee delivery. However, the cloud will try three times randomly within a max of 20 seconds (much longer for cellular data based devices) to get the message delivered and receive an acknowledgement. We found that our front door device had very poor wifi connectivity that was probably leading to lost data and transmission retries. Once we fixed the wifi reception problem by adding a whip antenna the device, these delay problems all seem to have gone away.

Closed 2021-11-19.

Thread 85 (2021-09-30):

ENH: Get Client Info should not wait after one message returned from cloud

jschrempp, 2021-09-30:
ezfReceiveClientByClientID currently waits for up to 4 messages back from the cloud. When it is able to parse the returned JSON (meaning it has all the data of the JSON) it updates g_clientInfo and sets g_clientInfo.isValid to true. This signals the main state machine that the data is ready. The state machine has a 15 second timer before it gives up. If the code receives all the messages from the cloud but is still unable to parse the JSON, this could also lead to a 15 second timeout.

Now that we have Mustache code in the webhook ezfClientByClientID we should only get one message back from the cloud from this webhook. There is no reason for ezfReceiveClientByClientID to wait for additional messages.

We suggest changing the code so that after if the JSON deserialization fails after one message is received, then the code should report the error and move on. There is no reason to wait 15 seconds after one message has been received. In addition, if a deserialization error occurs, we should log that data in the FDB for analysis.

jschrempp, 2021-10-10:
Fixed in v2.2 pull request #12

Closed 2021-11-19.

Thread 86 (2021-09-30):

ENH: Don't get packages if not needed

jschrempp, 2021-09-30:
We track member permission to use a piece of equipment or area with "packages" in the CRM system. When a user taps their RFID card on an equipment station, it will retrieve their list of packages from the CRM system. An equipment device is configured to require a certain string in the packages to allow access. For example, the woodshop device might be configured to only allow access when the string "wood" is in the title of a package.

In some cases no particular string is needed to allow access. For example, we might deploy an RFID box in the electronics lab to track access, but anyone can use the lab without needing any particular package.

In the equipment device state machine we always get packages from the CRM system. In the case of no string needed this is unnecessary and causes the member to wait for another round trip to the CRM system.

This enhancement is to change the equipment device state machine so that if the configured "ok" string is null, then the device should not request packages from the CRM system.

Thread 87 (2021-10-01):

ENH: If getToken fails, do not continuously retry

jschrempp, 2021-10-01:
We had a situation where our CRM vendor went offline. Requests to get an access token failed. In this case our firmware continued to try to obtain a token.

When getToken fails we should not continue to try just because the current token has expired. I suggest that if getToken fails, then we should only try to get a token when a user presents an RFID card. If the CRM is back up then the user will be delayed slightly. If the CRM is down the user might try once or twice and then give up; this is better than continuously banging on the CRM to get a token. Also, the users who fail will probably alert staff who can then discover the problem and power off the devices until the CRM is back up.

I would also suggest that once the device is able to obtain a good token it should again attempt to get a token five minutes before the good token expires.

jschrempp, 2021-10-10:
Suggested solution.

Add a boolean to the authorization structure. The boolean is set when we have a serious problem getting a token. If we successfully get a token the boolean is reset.

While the boolean is set we will never try to get a token unless it is in response to an RFID card tap. The card tap will override the error holdoff.

We'll have to add a parameter to ezfGetCheckinToken that will indicate whether to override the error holdoff. I'd call it cardIsPresented. Calls from the idle states and loop would call with this set to false. Calls from a state machine that is servicing a user RFID card tap would set this to true.

jschrempp, 2021-11-19:
This has been deployed for three weeks and seems to be working fine.

Closed 2021-11-19.

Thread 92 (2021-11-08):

click to checkout is broken

jschrempp, 2021-11-08:
On the page of currently checked in members, it was possible to click the person's name and have the system log them out. It was reported that this stopped working with release #84, the fix for generic images.

jschrempp, 2021-11-08:
Found that this is not caused by the fix for generic images. The root cause is that the web page rfidcurrentcheckins.php expects to be http not https. When the user clicks on a person's name the page issues a POST to the facility database as http.

If rfidcurrentcheckins.php has been opened as https then the post to an http link yields a "Mixed Content (nonsecure items) Error on SSL Secure Site".

I'm not sure how the browser got the checkin screen changed to https, but this is the root cause of the change.

jschrempp, 2021-11-08:
Some possible fixes:

1. Apparently meta content on the page could instruct the browser to ignore the Mixed Content error. Seems not such a good idea.
2. We could have the PHP script check for current SSL status and issue the appropriate link. Seems like a lot of work for this issue.
3. We could set the facility database checkout link to be https and always use that. If the page happens to be opened under http I think this would still work as it is a security upgrade. It requires us to maintain our SSL certificate.
4. We could open the current checkin web page as http instead of https and it will go back to working. This is the easiest.

pdlloyd, 2021-11-08:
> I'm not sure how the browser got the checkin screen changed to https
* https://blog.chromium.org/2021/03/a-safer-default-for-navigation-https.html?m=1
* https://blog.mozilla.org/security/2020/11/17/firefox-83-introduces-https-only-mode/

I think most browsers are moving toward making automatic https substitutions by default because of security concerns. I personally like option 3 and use something like that for my own projects -- if people try to access the pages with http, the server automatically upgrades them to https. I use [Let's Encrypt](https://letsencrypt.org/) and their CertBot tool to get free SSL certs and to automate management and renewal. It's super easy to integrate into Apache, Nginx, or whichever server framework is used.

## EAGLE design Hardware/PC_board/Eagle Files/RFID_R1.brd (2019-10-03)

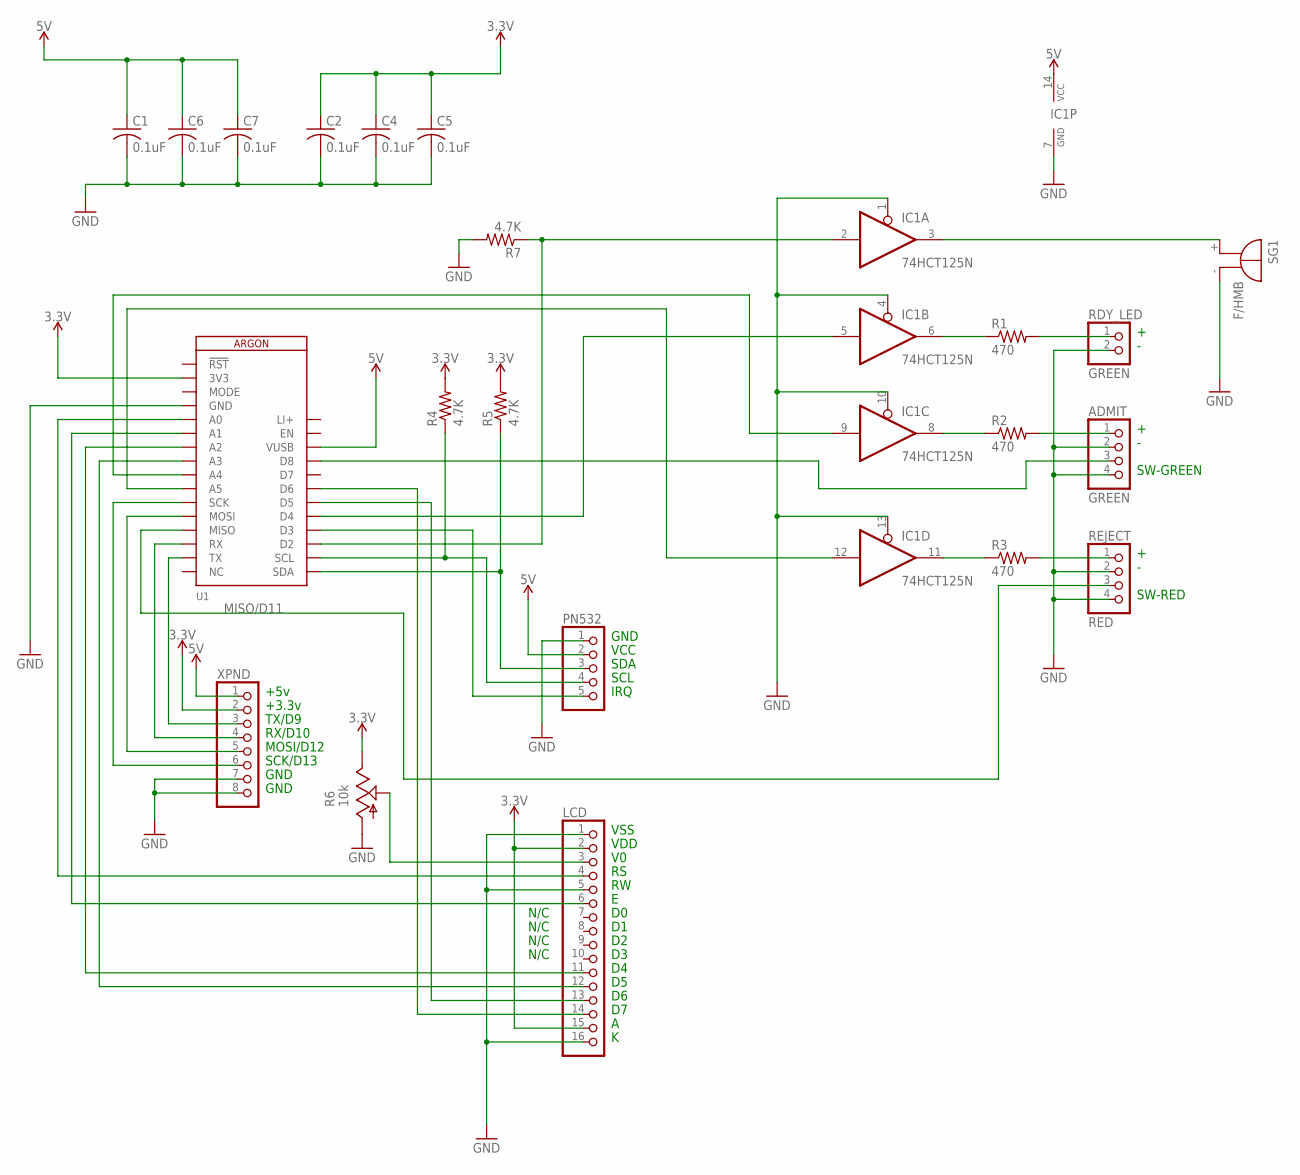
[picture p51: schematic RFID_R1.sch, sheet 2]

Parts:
ADMIT: GREEN; 1X04
C1, C2, C4, C5, C6, C7: 0.1uF; C025-024X044
IC1: 74HCT125N; DIL14
LCD: PINHD-1X16; 1X16
PN532: PINHD-1X5; 1X05
R1, R2, R3: 470; 0204/7
R4, R5, R7: 4.7K; 0204/7
R6: 10k; CT6
RDY_LED: GREEN; 1X02
REJECT: RED; 1X04
SG1: F/HMB
U1: ARGON
XPND: PINHD-1X8BIG; 1X08-BIG

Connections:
3.3V: C2.1, C4.1, C5.1, LCD.2, LCD.15, R4.2, R5.2, R6.E, U1.2 (3V3), XPND.2
5V: C1.1, C6.1, C7.1, IC1.14 (VCC), PN532.2, U1.26 (VUSB), XPND.1
GND: ADMIT.2, ADMIT.4, C1.2, C2.2, C4.2, C5.2, C6.2, C7.2, IC1.1 (OE), IC1.4 (OE), IC1.7 (GND), IC1.10 (OE), IC1.13 (OE), LCD.1, LCD.5, LCD.16, PN532.1, R6.A, R7.2, RDY_LED.2, REJECT.2, REJECT.4, SG1.-, U1.4 (GND), XPND.7, XPND.8
LI+: U1.28 (LI+)
MISO/D11: REJECT.3, U1.13 (MISO)
unnamed: IC1.3 (O), SG1.+
unnamed: IC1.6 (O), R1.1
unnamed: IC1.8 (O), R2.1
unnamed: IC1.11 (O), R3.1
unnamed: R1.2, RDY_LED.1
unnamed: ADMIT.1, R2.2
unnamed: R3.2, REJECT.1
unnamed: LCD.4, U1.5 (A0)
unnamed: LCD.6, U1.6 (A1)
unnamed: LCD.11, U1.7 (A2)
unnamed: LCD.12, U1.8 (A3)
unnamed: LCD.13, U1.22 (D5)
unnamed: LCD.14, U1.23 (D6)
unnamed: PN532.4, R4.1, U1.18 (SCL)
unnamed: IC1.9 (I), U1.9 (A4)
unnamed: PN532.3, R5.1, U1.17 (SDA)
unnamed: LCD.3, R6.S
unnamed: PN532.5, U1.20 (D3)
unnamed: ADMIT.3, U1.25 (D8)
unnamed: IC1.5 (I), U1.21 (D4)
unnamed: IC1.12 (I), U1.10 (A5)
unnamed: IC1.2 (I), R7.1, U1.19 (D2)
unnamed: U1.12 (MOSI), XPND.5
unnamed: U1.11 (SCK), XPND.6
unnamed: U1.14 (RX), XPND.4
unnamed: U1.15 (TX), XPND.3

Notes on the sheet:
VSS
VDD
GND
VCC
SDA
SCL
IRQ
N/C
+5v
+3.3v
MOSI/D12
SCK/D13
SW-GREEN
SW-RED
RX/D10
TX/D9

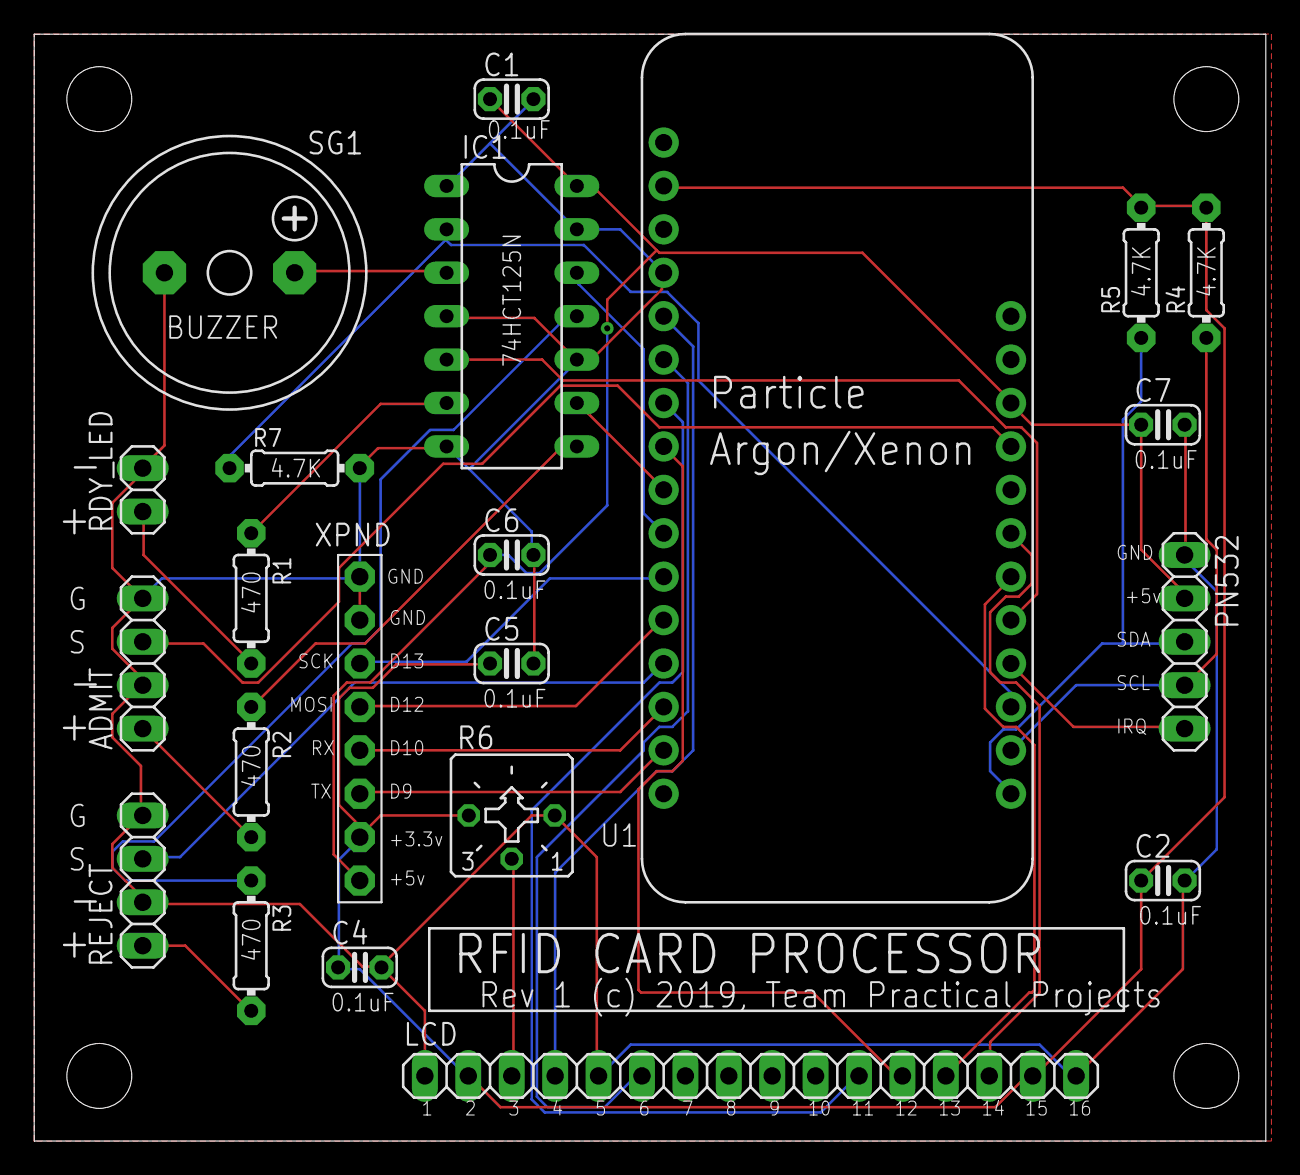
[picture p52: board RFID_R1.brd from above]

Board: 2 copper layers, 72.1 x 64.8 mm, 22 parts (0 on the bottom side), 30 nets.

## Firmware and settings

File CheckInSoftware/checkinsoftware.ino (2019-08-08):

/*********************************************************************
 * MNCheckin
 * 
 * This program is used to verify and checkin members to the Maker Nexus
 * makerspace. The program waits for a correctly formated Mifare RFID card
 * to be presented. Two values are read from the card: clientID and UID. 
 * The program verifies that the CRM system (EzFacility) has a contact with
 * clientID and that the contact record has UID associated with it. This 
 * validates the card and the contact. The program then determines if the 
 * contact has a valid, paid-up membership. If all tests are good a green
 * light and beep are presented. If not a red light and a long buzz are 
 * presented.
 * 
 * RFID Card Functions
 * This program integrates the Adafruit PN532
 * RFID brakout board with Particle (Photon).  The Particle device
 * is interfaced to the Adafruit breakout board using I2C.  Wiring
 * is as follows;
 * 
 *  Photon powered via USB
 *  PN532 breakout board 5.0V to Photon VIN
 *  PN532 breakout board GND to Photon GND (both GND)
 *  PN532 breakout board SDA to Photon D0
 *  PN532 breakout board SCL to Photon D1 
 *  Both SCL and SDA pulled up to Photon +3.3v using 5.6kohm resistors
 *  PN532 breakout board IRQ to Photon D3
 *  Photon D4 not connected but reserved for "RST"
 *  Breakout board jumpers are set for I2C:  SEL 1 is OFF and SEL 0 is ON
 * 
 * A 16x2 lcd display as also connected to the Photon.  LCD wiring is:
 *  lcd VSS to GND.  lcd VDD to +3.3 volts. lcd V0 to wiper of a 10K pot.  
 *    One end of the pot is connected to +3.3. volts and the other end to GND.
 *  lcd RS to Photon A0. lcd RW to GND. lcd EN to Photon A1. lcd D0 - D3 are left unconnected.
 *  lcd D4 to Photon A2.  lcd D5 to Photon A3.  lcd D6 to Photon D5.  lcd D7 to Photon D6.
 *  LCD A to +3.3 volts.  lcd K to GND.
 * 
 * 
 * The program initially waits 5 seconds so that a tty port can be connected for
 * serial console communication.  A "trying to connect ..." message is then
 * printed to the serial port to show that things are ready.  Next, the Photon
 * communicates with the breakout board to read out and print the PN532 firmware
 * version data to show that the Photon is talking to the breakout board.  
 * 
 * This program determines if an ISO14443A card presented to the reader is
 * factory fresh or if it has been formatted as Maker Nexus.  Based upon the
 * determined format, the firmware then changes keys to reverse the format;
 * i.e. make factory fresh to MN or make MN to factory fresh.  After changing
 * the card format, this firmware then writes some data to blocks 0 and 1
 * and reads them back, in order to verfy the key changes.  If the new format
 * is factory fresh, the data written to both blocks is 16 bytes of 0x00.  However,
 * if the new format is MN, the data written to blocks 0 and 1 is test data 
 * that is different for each block.  Thus, the firmware toggles the card
 * back and forth between MN format and factory default format with each 
 * placement and removal of the test card.
 * 
 * 
 * Adapted from code at:
 *   https://github.com/adafruit/Adafruit-PN532/blob/master/examples
 * 
 * Once the clientID and UID have been stored in g_clientInfo the program will 
 * move on to the next steps and mark the clientID record as "checked in" in
 * the CRM system (EzFacility).
 * 
 * 
 * 
 * CheckIn
 * 
 * The program uses Particle.io webhooks to 
 * access and update information in the EZFacility CRM database used
 * by Maker Nexus. Associated with this file is a file called webhooks.txt
 * that contains the JSON code needed to recreate each Particle.io
 * webhook used by this code. Once the webhooks have been created 
 * you will need to modify the webhook ezfGetCheckInToken to have a valid 
 * EZFacility authentication token and username/password.
 * 
 * There are several cloud functions so this program can be tested
 * through the Particle.io console.
 * 
 * The primary call-in is the cloud function RFIDCardRead. Call this
 * with a two value, comma separated string of the form
 *     clientID,UID
 * where clientID is a valid clientID and UID is expected to be found 
 * in the associated record in the EZFacility CRM database. An example is:
 *     21613660,rt56
 * Currently the UID is ignored in this code.
 * 
 * After calling RFIDCardRead, a series of debug events are published
 * for your convenience. When the process successfully completes you
 * can verify the action by going to the EZFacility Admin console and 
 * running the report Check-in Details.
 * 
 * 
 * (c) 2019; Team Practical Projects
 * 
 * Authors: Bob Glicksman, Jim Schrempp
 * version 1; 8/4/2019.
 * 
************************************************************************/

//#define TEST     // uncomment for debugging mode
#define RFID_READER_PRESENT  // uncomment when an RFID reader is connected
#define LCD_PRESENT  // uncomment when an LCD display is connected

//Required to get ArduinoJson to compile
#define ARDUINOJSON_ENABLE_PROGMEM 0
#include <ArduinoJson.h>
//https://arduinojson.org/v6/assistant/

// This #include statement was automatically added by the Particle IDE.
#include <Adafruit_PN532.h>

// This #include statement was automatically added by the Particle IDE.
#include <LiquidCrystal.h>

// ----------- RFID Constants and Globals -------------------

#define IRQ_PIN D3
#define RST_PIN D4  // not connected
#define LED_PIN D7

#define READY_LED D4
#define ADMIT_LED A4
#define REJECT_LED A5
#define BUZZER_PIN D2

// Sector to use for testing
const int SECTOR = 3;	// Sector 0 is manufacturer data and sector 1 is real MN data

// Encryption keys for testing
uint8_t DEFAULT_KEY_A[6] = { 0xFF, 0xFF, 0xFF, 0xFF, 0xFF, 0xFF };
uint8_t DEFAULT_KEY_B[6] = { 0xFF, 0xFF, 0xFF, 0xFF, 0xFF, 0xFF };
uint8_t MN_SECRET_KEY_A[6] = { 0xA0, 0xA1, 0xA2, 0xA3, 0xA4, 0xA5 };
uint8_t MN_SECRET_KEY_B[6] = { 0xB0, 0xB1, 0xB2, 0xB3, 0xB4, 0xB5 };

// Access control bits for a sector
    // the default is block 0, 1, and 2 of the sector == 0x00
	// the default for block 3 (trailer) of the sector is 0x01
	// the desired MN bits for block 0, 1, and 2 of the sector == 0x04
	// the desired MN bits for block 3 (trailer) of the sector is 0x03
	// byte 9 is user data.  We will make this byte 0x00
	// compute ACB bytes using http://calc.gmss.ru/Mifare1k/
uint8_t DEFAULT_ACB[4] = {0xFF, 0x07,0x80, 0x00};
uint8_t MN_SECURE_ACB[4] = {0x7C, 0x37,0x88, 0x00};

// Global variables to hold card info
uint8_t uid[] = {0, 0, 0, 0, 0, 0, 0};  // 7 byte buffer to store the returned UID
uint8_t uidLength;  // Length of the UID (4 or 7 bytes depending on ISO14443A card type)

// Global variable for messages
String message = "";

// Data for testing
uint8_t TEST_PAT_1[] = {0, 1, 2, 3, 4, 5, 6, 7, 8, 9, 10, 11, 12, 13, 14, 15};
uint8_t TEST_PAT_2[] = {255, 254, 253, 252, 251, 250, 249, 248, 247, 246, 245, 244, 243, 242, 241, 240};


// instantiate in I2C mode   
Adafruit_PN532 nfc(IRQ_PIN, RST_PIN); 

// instatiate the LCD
LiquidCrystal lcd(A0, A1, A2, A3, D5, D6);



// -------------------- UTILITIES -----------------------

template <size_t charCount>
void strcpy_safe(char (&output)[charCount], const char* pSrc)
{
    // Copy the string — don’t copy too many bytes.
    strncpy(output, pSrc, charCount);
    // Ensure null-termination.
    output[charCount - 1] = 0;
}

char * strcat_safe( const char *str1, const char *str2 ) 
{
    char *finalString = NULL;
    size_t n = 0;

    if ( str1 ) n += strlen( str1 );
    if ( str2 ) n += strlen( str2 );

    finalString = (char*) malloc( n + 1 );
    
    if ( ( str1 || str2 ) && ( finalString != NULL ) )
    {
        *finalString = '\0';

        if ( str1 ) strcpy( finalString, str1 );
        if ( str2 ) strcat( finalString, str2 );
    }

    return finalString;
}  
  


// Define the pins we're going to call pinMode on

int led = D0;  // You'll need to wire an LED to this one to see it blink.
int led2 = D7; // This one is the built-in tiny one to the right of the USB jack


//----------- Global Variables

String g_tokenResponseBuffer = "";
String g_cibmnResponseBuffer = "";
String g_cibcidResponseBuffer = "";
String g_packagesResponseBuffer = "";

String JSONParseError = "";
String g_recentErrors = "";
String debug2 = "";
int debug3 = 0;
int debug4 = 0;
int debug5 = 0;

String g_packages = ""; // Not implemented yet

struct struct_cardData {
    int clientID = 0;
    String UID = "";
} g_cardData;


struct struct_authTokenCheckIn {
   String token = ""; 
   unsigned long goodUntil = 0;   // if millis() returns a value less than this, the token is valid
} g_authTokenCheckIn;

struct  struct_clientInfo {  // holds info on the current client
    bool isValid = false;        // when true this sturcture has good data in it
    int clientID = 0;           // numeric value assigned by EZFacility. Guaranteed to be unique
    String RFIDCardKey = "";    // string stored in EZFacility "custom fields". We may want to change this name
    String memberNumber = "";   // string stored in EZFacility. May not be unique
    String contractStatus = ""; // string returned from EZF. Values we know of: Active, Frozen, Cancelled, Suspended
} g_clientInfo;

typedef enum eRetStatus {
    IN_PROCESS = 1,
    COMPLETE_OK = 2,
    COMPLETE_FAIL = 3,
    IDLE =4
} eRetStatus;


// ------------------   Forward declarations, when needed
//
eRetStatus checkInClientByClientID(int clientID, String cardUID);


//-------------- Particle Publish Routines --------------
// These routines are used to space out publish events to avoid being throttled.
//

int particlePublish (String eventName, String data) {
    
    static unsigned long lastSentTime = 0;
    
    if (millis() - lastSentTime > 1000 ){
        // only publish once a second
        
        Particle.publish(eventName, data);
        lastSentTime = millis();
        
        return 0;
        
    } else {
        
        return 1;
        
    }
}

String messageBuffer = "";
// Call this from the main look with a null message
void debugEvent (String message) {
    
    if (message.length() > 0 ){
        // a message was passed in
        
        messageBuffer =  message + " | " + messageBuffer;
        
        if (messageBuffer.length() > 600 ) {
            // message buffer is too long
            
            messageBuffer = messageBuffer.substring(0,570) + " | " + "Some debug messages were truncated";
        }
        
    }
    
    if (messageBuffer.length() > 0) {
        
        // a message buffer is waiting
    
        int rtnCode = particlePublish ("debugX", messageBuffer);
        
        if ( rtnCode == 0 ) {
        
            // it succeeded
            messageBuffer = "";
        
        }
    }
}



// ------------- Get Authorization Token ----------------

int ezfGetCheckInTokenCloud (String data) {
    
    ezfGetCheckInToken();
    return 0;
    
}

int ezfGetCheckInToken () {
    
    if (g_authTokenCheckIn.goodUntil < millis() ) {
        // Token is no longer good    
        g_authTokenCheckIn.token = "";
        g_tokenResponseBuffer = "";
        Particle.publish("ezfCheckInToken", "");
    
    }

    return 0;
    
}

void ezfReceiveCheckInToken (const char *event, const char *data)  {
    
    // accumulate response data
    g_tokenResponseBuffer = g_tokenResponseBuffer + String(data);
    
    debugEvent ("Receive CI token " + String(data) );
    
    const int capacity = JSON_OBJECT_SIZE(8) + 2*JSON_OBJECT_SIZE(8);
    StaticJsonDocument<capacity> docJSON;
   
    char temp[3000]; //This has to be long enough for an entire JSON response
    strcpy_safe(temp, g_tokenResponseBuffer.c_str());
    
    // will it parse?
    DeserializationError err = deserializeJson(docJSON, temp );
    JSONParseError =  err.c_str();
    if (!err) {
        //We have valid JSON, get the token
        g_authTokenCheckIn.token = String(docJSON["access_token"].as<char*>());
        g_authTokenCheckIn.goodUntil = millis() + docJSON["expires_in"].as<int>()*1000 - 5000;   // set expiry five seconds early
        
        debugEvent ("now " + String(millis()) + "  Good Until  " + String(g_authTokenCheckIn.goodUntil) );
   
    }
}

// ------------ ClientInfo Utility Functions -------------------

void clearClientInfo() {
    
    g_clientInfo.isValid = false;
    g_clientInfo.clientID = 0;
    g_clientInfo.RFIDCardKey = "";
    g_clientInfo.contractStatus = "";
    
}

int parseClientInfoJSON (String data) {
    
    // try to parse it. Return 1 if fails, else load g_clientInfo and return 0.
    
    DynamicJsonDocument docJSON(2048);
   
    char temp[3000]; //This has to be long enough for an entire JSON response
    strcpy_safe(temp, g_cibmnResponseBuffer.c_str());
    
    // will it parse?
    DeserializationError err = deserializeJson(docJSON, temp );
    JSONParseError =  err.c_str();
    if (!err) {
        
         // is the memberid unique?
         JsonObject root_1 = docJSON[1];
        if (root_1["ClientID"].as<int>() != 0)  {  // is this the correct test?
            
            // member id is not unique
            g_recentErrors = "More than one client info in JSON ... " + g_recentErrors;
            
        } else {
         
            JsonObject root_0 = docJSON[0];
            g_clientInfo.clientID = root_0["ClientID"].as<int>();
            
            g_clientInfo.contractStatus = root_0["MembershipContractStatus"].as<char*>();
            
            String fieldName = root_0["CustomFields"][0]["Name"].as<char*>();
            
            if (fieldName.indexOf("RFID Card UID") >= 0) {
               g_clientInfo.RFIDCardKey = root_0["CustomFields"][0]["Value"].as<char*>(); 
            }
            
            g_clientInfo.isValid = true;
            
        }
        
        return 0;
        
    } else {
        
        debugEvent("JSON parse error " + JSONParseError);
        return 1;
    }
    
}


// ------------- Get Client Info by MemberNumber ----------------

int ezfClientByMemberNumber (String data) {
    
    // if a value is passed in, set g_memberNumber
    String temp = String(data);
    if (temp == "") {
        g_recentErrors = "No Member Number passed in. ... " + g_recentErrors;
        return -999;
    } 
    
    g_cibmnResponseBuffer = "";  // reset last answer

    clearClientInfo();

    // Create parameters in JSON to send to the webhook
    const int capacity = JSON_OBJECT_SIZE(8) + 2*JSON_OBJECT_SIZE(8);
    StaticJsonDocument<capacity> docJSON;
    
    docJSON["access_token"] = g_authTokenCheckIn.token.c_str();
    docJSON["memberNumber"] = temp.c_str();
    
    char output[1000];
    serializeJson(docJSON, output);
    
    int rtnCode = Particle.publish("ezfClientByMemberNumber",output );
    
    return g_clientInfo.memberNumber.toInt();
}


void ezfReceiveClientByMemberNumber (const char *event, const char *data)  {
    
    g_cibmnResponseBuffer = g_cibmnResponseBuffer + String(data);
    debugEvent("clientInfoPart " + String(data));
    
    parseClientInfoJSON(g_cibmnResponseBuffer); // try to parse it

}


// ------------- Get Client Info by ClientID ----------------
int ezfClientByClientIDCloud (String data) {
    
    // if a value is passed in, set g_memberNumber
    String temp = String(data);
    if (temp == "") {
        debugEvent("No Client ID passed in from cloud function ");
        // We don't change g_clientID
        return 1;
    } 
    
    if (temp.toInt() == 0){
        debugEvent("Cloud function passed in non-numeric or 0 clientID");
        // We don't change g_clientID
        return 1;
        
    }
    
    ezfClientByClientID(temp.toInt());
    
    return 0;
    
}


int ezfClientByClientID (int clientID) {
    
    
    g_cibcidResponseBuffer = "";  // reset last answer

    clearClientInfo();

    // Create parameters in JSON to send to the webhook
    const int capacity = JSON_OBJECT_SIZE(8) + 2*JSON_OBJECT_SIZE(8);
    StaticJsonDocument<capacity> docJSON;
    
    docJSON["access_token"] = g_authTokenCheckIn.token.c_str();
    docJSON["clientID"] = clientID;
    
    char output[1000];
    serializeJson(docJSON, output);
    
    int rtnCode = Particle.publish("ezfClientByClientID",output );
    
    return 0;
}


void ezfReceiveClientByClientID (const char *event, const char *data)  {
    
    g_cibcidResponseBuffer = g_cibcidResponseBuffer + String(data);
    debugEvent ("clientInfoPart " + String(data));
    
    const size_t capacity = 3*JSON_ARRAY_SIZE(2) + 2*JSON_ARRAY_SIZE(3) + 10*JSON_OBJECT_SIZE(2) + JSON_OBJECT_SIZE(20) + 1050;
    DynamicJsonDocument docJSON(capacity);
   
    char temp[3000]; //This has to be long enough for an entire JSON response
    strcpy_safe(temp, g_cibcidResponseBuffer.c_str());
    
    // will it parse?
    DeserializationError err = deserializeJson(docJSON, temp );
    JSONParseError =  err.c_str();
    if (!err) {

        g_clientInfo.clientID = docJSON["ClientID"].as<int>();
            
        g_clientInfo.contractStatus = docJSON["MembershipContractStatus"].as<char*>();
            
        String fieldName = docJSON["CustomFields"][0]["Name"].as<char*>();
            
        if (fieldName.indexOf("RFID Card UID") >= 0) {
            g_clientInfo.RFIDCardKey = docJSON["CustomFields"][0]["Value"].as<char*>(); 
        }
            
        g_clientInfo.isValid = true;
        
    }
}

// ----------------- GET PACKAGES BY CLIENT ID ---------------


int ezfGetPackagesByClientID (String notused) {

    g_packagesResponseBuffer = "";
    g_packages = "";

    // Create parameters in JSON to send to the webhook
    const int capacity = JSON_OBJECT_SIZE(8) + 2*JSON_OBJECT_SIZE(8);
    StaticJsonDocument<capacity> docJSON;
    
    docJSON["access_token"] = g_authTokenCheckIn.token.c_str();
    docJSON["clientID"] = String(g_clientInfo.clientID).c_str();
    
    char output[1000];
    serializeJson(docJSON, output);
    
    int rtnCode = Particle.publish("ezfGetPackagesByClientID",output );
    
    return rtnCode;
}


void ezfReceivePackagesByClientID (const char *event, const char *data)  {
    
    g_packagesResponseBuffer = g_packagesResponseBuffer + String(data);
    debugEvent ("PackagesPart" + String(data));
    
    DynamicJsonDocument docJSON(2048);
   
    char temp[3000]; //This has to be long enough for an entire JSON response
    strcpy_safe(temp, g_packagesResponseBuffer.c_str());
    
    // will it parse?
    DeserializationError err = deserializeJson(docJSON, temp );
    JSONParseError =  err.c_str();
    if (!err) {
        
        
    }
        
}

// ----------------- CHECK IN CLIENT -------------------
int ezfCheckInClient(String clientID) {
    
     // Create parameters in JSON to send to the webhook
    const int capacity = JSON_OBJECT_SIZE(8) + 2*JSON_OBJECT_SIZE(8);
    StaticJsonDocument<capacity> docJSON;
    
    docJSON["access_token"] = g_authTokenCheckIn.token.c_str();
    docJSON["clientID"] = clientID.c_str();
    
    char output[1000];
    serializeJson(docJSON, output);
    
    int rtnCode = Particle.publish("ezfCheckInClient",output );
    
    return rtnCode;
}



// ------------------- CLOUD TESTING CALLS ----------------

// Called to simulate a card read. 
// Pass in: clientID,cardUID

int RFIDCardReadCloud (String data) {
    
    int commaLocation = data.indexOf(",");
    if (commaLocation == -1) {
        // bad input data
        debugEvent("card read: no comma found ");
        return 1;
    }
    
    String clientID = data.substring(0,commaLocation);
    String cardUID = data.substring(commaLocation+1, data.length());
    debugEvent ("card read. client/UID: " + clientID + "/" + cardUID);
    
    int clientIDInt = clientID.toInt();

    if (clientIDInt == 0) {
        // bad data
        debugEvent ("card read: clientID is 0 or not int");
        return 1;
    }
    
    if (cardUID.length() < 1) {
        // bad data
        debugEvent ("card read: cardUID length is 0");
        return 1;
    }
    
    // setting this global variable will cause the main loop to begin the checkin process.
    // these  will be set to "" when the checkin process is done or gives up.
    g_cardData.clientID = clientIDInt;
    g_cardData.UID = cardUID;
    debugEvent("card read success: " + String(g_cardData.clientID) + "/" + g_cardData.UID );
    
    return 0;
}
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
void loop() {
    
    enum mlState {mlsIDLE, mlsCARDPRESENT, mlsCARDOK, mlsCHECKINGIN, mlsERROR};
    
    static mlState mainloopState = mlsIDLE;
    
    switch (mainloopState) {
    case mlsIDLE: {
        
        eRetStatus retStatus = readTheCard();
        if (retStatus == COMPLETE_OK) {
            // move to the next step
            mainloopState = mlsCHECKINGIN;
        }
        break;
    }
    case mlsCHECKINGIN: {
        
        eRetStatus retStatus = checkInClientByClientID(0,""); 
        debugEvent("state machine returned status: " + String(retStatus));
        
        switch (retStatus) {
        case IN_PROCESS:
            break;
        case IDLE: {
            
            eRetStatus retStatus = checkInClientByClientID(g_cardData.clientID, g_cardData.UID); 
            // xxx we should check the return status here to make sure the checkin took off
            g_cardData.clientID = 0;
            g_cardData.UID = "";
            break;
        }
        case COMPLETE_OK:
            mainloopState = mlsIDLE;
            break;
        case COMPLETE_FAIL:
            break;
        } // switch (retStatus)
        
        break;
    }
    case mlsERROR:
        break;
    default:
        break;
    } //switch (mainloopState)
    
    
    heartbeatLEDs();

    debugEvent("");  // need this to pump the debug event process

}

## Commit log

2019-06-19 Board config and initial test
    An Adafruit PN532 breakout board is connected to a Photon using I2C. The firmware runs a basic test that connects to the breakout board, reads out its firmware version and awaits for an RFID card to 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
2019-06-24 Create test-PN532-keyChange.ino
    This is a test for building the sector trailer with new keys and new access control bits. The sector trailer is not changed in this test -- the data is written to a data block and read back to make sure that the 16 byte construction is correct.
    [test-PN532-keyChange.ino]
2019-06-26 Update test-PN532-keyChange.ino
    This code adds functions to authenticate a block (with relative block numbers and error checking) and to read data, including authenticating a block.
    This version also has a function to determine the card type based upon trying to authenticate with various keys. HOWEVER, it appears that if you authenticate with a bad key and it fails, then authenticating with a good key will also fail!
    [test-PN532-keyChange.ino]
2019-06-27 Update test-PN532-keyChange.ino
    Fixed the testCard() function so that it resets after authentication failure and also only tries key A for authentication (so that it can be used in any app -- doesn't need to know secret key B - the write key). Also, waits for card to be removed at the end of loop().
    [test-PN532-keyChange.ino]
2019-06-29 test-PN532-keyChange.ino v2.1
    commenting out #define DEBUG in version 2.0 did not remove the test printout code. Changing DEBUG to TEST works fine. This is the only change from v2.0. I also included a printout of the results with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
2019-07-16 Added pin definitions and lcd code
    Added a hardware folder and place a document with Photon/Argon pin assignments into it. Also added lcd display code to the RFID test firmware; mostly to test out compatibile pin assignments on a Phot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
2019-08-03 Preliminary Reader PCB Files
    Eagle files + PDF form of the schematic. The schemtic is complete and reading for testing on a breadboard. Board layout has not been started.
    [MN_RFID.brd, MN_RFID.sch]
2019-08-08 Updated Schematic
    Updated schematic per testing breadboard at MN 8/07/19. Decided to power from Argon and remove external 5v USB connector, 3.3v power converter, and 100 uF cap. 5v supplied from Argon via VUSB pin. 3.3v supplied from Argon via 3.3v pin. Also added 5.6Kohm pulldown on D4 to prevent buzzer from going off while Argon sets up.
    [MN_RFID.brd, MN_RFID.sch]
2019-08-08 PCB Parts PLacement
    [MN_RFID.brd]
2019-08-08 Update MN_RFID.brd
    Jiggled around the layout a little.
    [MN_RFID.brd]
2019-08-08 Updated schematic
    Changed pull-up/down resistors from 5.6K to 4.7K -- more common value.
    [MN_RFID.brd, MN_RFID.sch]
2019-08-10 Cleaned up initial readCard implementation. Added test for bad read and buzz. LCD messages changed. No longer blocks waiting for card.
    [checkinfirmware.ino]
2019-08-11 PCB Finalization
    Added expansion connector and board name. Routed and coppoer pour. Annotated the top silkscreen layer for connection information.
    [MN_RFID.brd, MN_RFID.sch]
2019-08-12 Update MN_RFID.brd
    Added some addtional text to top silkscreen layer.
    [MN_RFID.brd]
2019-08-12 Added buzzer responses when things happen. Also updates to LCD messages.
    [checkinfirmware.ino]
2019-08-12 Create Reader PCB Parts List.xlsx
    Preliminary parts list in Excel format - currently incomplete
    [Reader PCB Parts List.xlsx]
2019-08-16 Update Reader PCB Parts List.xlsx
    Changed ADMIT and REJECT LEDs to be backlit panel buttons (per team meeting 8/16/19)
    [Reader PCB Parts List.xlsx]
2019-08-25 LED handled correctly, more errors displayed, buzzer in places, welcome with client name
    [checkinfirmware.ino]
2019-08-28 Added LCD error messages in SetUp()
    [checkinfirmware.ino]
2019-08-29 Updated Parts List
    renamed and updated the Excel parts list. Added in Jim's parts from EBay.
    [Reader PCB Parts List.xlsx, Reader_PCB_Parts_List.xlsx]
2019-08-31 Cloud function to configure device type
2019-09-01 Added folder for Admin GUI App
    The folder contains Particle test code to test out the app. The GUI is an .aia file that is currently in design and development.
2019-09-02 admin device loop works, but not all functionality is there.
2019-09-03 Admin query member and burn card work!
    [checkinfirmware.ino]
2019-09-20 1.071 bug fix to the timeout code after displaying a query name
    [checkinfirmware.ino]
2019-09-21 1.074 fix to burnUID. Checkin test now validates UID, contract status, amount due.
    [checkinfirmware.ino]
2019-09-23 added logToDB to send log records via a webhook. Set timezone and DST. Fix to cloudIdentifyCard
    [checkinfirmware.ino]
2019-09-29 fixed bug in cloudIdentifyCard
    [checkinfirmware.ino]
2019-10-03 R1 Board
    Updated schematic and board layout for rev 1. Rev 1 includes part placement adjustment and addition of pin header connections for the pushbutton switches.
    [RFID_R1.brd, RFID_R1.sch]
2019-10-03 Update RFID_R1.brd
    Slight adjustments and additions to top silkscreen to make the board look good as rendered by OSHPark.
    [RFID_R1.brd]
2019-10-04 1.083 fixed bug in one dblogging
    [checkinfirmware.ino]
2019-10-06 1.084 resetCard works. "ing" denial bug fixed.
    [checkinfirmware.ino]
2019-10-07 JSON to app bug fixed
    [checkinfirmware.ino]
2019-11-08 CAm files and PCB Order Information
    Included a .zip archive of manufacturing (CAM) data from Eagle. These files worked with PCLPCB, a low cost PB manufacturer. Also included is a .txt file that describes this.
2019-11-15 Fixed woodshop using old package data
    [checkinfirmware.ino]
2019-11-15 Hardware/Enclosure Files
    Reorganized the Hardware folder with subfolders for PCB and Enclosure. Added enclosure CAD files. photos, and notes for later document development. Renamed the Parts List spreadsheet to reflect that 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
    [MN_RFID.brd, MN_RFID.sch, RFID_R1.brd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]
2019-11-15 Update RFID_Station_Parts_List.xlsx
    Not complete but added Jim's parts and links
    [RFID_Station_Parts_List.xlsx]
2019-11-16 Completed Parts List
    All parts are on the parts list, with jameco alternatives where known. The parts list is now stored in PDF format in this repository. The spreadsheet version is available in Google Docs.
    [RFID_Station_Parts_List.xlsx]
2019-11-17 turn on all LEDs when device type undefined
2019-11-28 Reboots every day after 1:05 AM
    [checkinfirmware.ino]
2020-01-02 added lasers as device 105
2020-01-04 laser case file updated
2020-01-11 current checkin webpage - needs db stored proc
2020-01-11 SetDeviceType now delays reboot to return a value.
    [checkinfirmware.ino]
2020-01-22 deleted. old per bob g
    [MN_RFID.brd, MN_RFID.sch]
2020-02-06 Posted released v1 Hardware Build Manual
    Cleaned out old photos and others docs/notes that are incorporated into the Manual.
    [MN_RFID.brd, MN_RFID.sch]
2020-06-19 Updated Station Config App to v2.1
    Disabled the station code text box so that device/listen codes can only be selected from the list obtained from the fdb. This resolves the bug that crashes the app if someone types in an unassigned type code.
2020-06-19 V2.2 of Station Config App
    I noticed a cosmetic probem with the app and I cleaned it up. Previously, there was a label for the new station type and another for the new listen type. With the current GUI having one new type code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
2020-06-25 Update RFID_Administrator_User_Manual.pdf
    Revised to include instructions for RFID Lock devices
2020-08-19 1.72 eqstation checks membership. blinks led
2020-12-17 1.8 bug in client info receive
    [checkinfirmware.ino]
2020-12-18 changed one error message
    [checkinfirmware.ino]
2021-08-10 2.0 attempted fix for github #79
    [checkinfirmware.ino]
2021-09-14 2.1 update ArduinoJSON
2021-10-08 switch back to dev compile option
2021-10-10 v2.3 on token error, wait for RFID card tap
    [checkinfirmware.ino]

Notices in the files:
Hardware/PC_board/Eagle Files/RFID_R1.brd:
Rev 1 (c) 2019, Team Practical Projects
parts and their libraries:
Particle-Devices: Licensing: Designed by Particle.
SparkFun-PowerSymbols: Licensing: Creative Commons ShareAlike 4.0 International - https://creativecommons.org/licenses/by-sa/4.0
